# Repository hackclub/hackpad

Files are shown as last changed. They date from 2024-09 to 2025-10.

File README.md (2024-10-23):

# Hackpad

https://hackpad.hackclub.com/ <- website is live! This is probably a better place to start

## Overview
This is a limited-time introductory YSWS (you ship, we ship) where *you* design your own macropad, and we'll ship it to you for free! This is something you definitely don't want to miss out, so make sure to join #hackpad in the slack!

### You ship:
- A PCB Design and schematic
- Files for a case, either in STL or DXF format.
- Firmware for the keyboard. You are allowed to use QMK or other pre-existing firmware!

### We'll send you:
- 3 PCBs! Keep one for yourself, or share some with your friends. Or you can keep them all, I won't judge.
- a Seeed XIAO RP2040 microcontroller. They're pretty nifty microcontrollers, so you can use them for something else too
- Switches! Choices TBD, but you'll have a great selection
- Other components you may need, such as LEDs, diodes, knobs, OLED screens, and more!
- Your case! You can either have it 3D printed, laser cut in acrylic, or both.
- A grab bag of DSA keycaps, and a custom Hack Club keycap too.

You can get the macropads soldered if you don't have a soldering iron, or we can send you the parts directly if you're up for a soldering task. The only catch is that if you want it to be soldered, you *must* use through-hole components only!

### Requirements:
- You design a macropad that integrates a [Seeed XIAO RP2040](https://wiki.seeedstudio.com/XIAO-RP2040/) as the main MCU. Nothing else allowed, sorry!
- It has 20 or less inputs. A single input includes a rotary encoder, switch etc.
- It is meaningfully unique to you. This could be as simple as making a custom layout and adding some decor, or as elaborate as writing an entire firmware in Rust
- The PCB only uses 2 layers
- The PCB does not exceed 100mm in length in any direction
- Don't make a macropad with 40 screens. Or out of pure gold. Please!!

Once that's done, you can go on and make a PR. The instructions will be in the template.

## Anything else?

This YSWS is only guaranteed to run through October 21st, so make sure to get yours submitted before then. Depending on skill level, this should take roughly 6-12 hours to finish.

List of questions from the slack that you may want answered too:

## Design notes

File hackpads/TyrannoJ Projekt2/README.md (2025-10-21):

# TYRANNOJ PROJEKT2  
This is my first PCB, just want to play around with it. My firmware is not fully optimized due to a lack of time, I will optimize it when the parts get shipped. My libraries in the pcb part are zipped, so I could upload everything, you have to unzip them or else the pcb won't work
picture of project  

### Inspiration

Somebody in school told me about it

### Challenges

Did it for the first time, was pretty difficult

### Specifications

BOM:\
•   4x Cherry MX Switches  
•	2x SK6812 MINI Leds  
•	1x XIAO RP2040  
•	2x: RotaryEncoder_Alps_EC11E-Switch_Vertical_H20mm_CircularMountingHoles  
•	4x Blank DSA Keycaps  
•	4x M3x16 Bolt  
•	4x M3 Heatset  

Others: \
•	KMK Firmware <br>
•	Top.stl \
•	Bottom.stl 
Schematic            |  PCB         |   Case
:-------------------------:|:-------------------------:|:-------------------------:|
schematic    |  PCB  | case

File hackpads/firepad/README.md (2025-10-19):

# Firepad
## Firepup's macropad

Primarily intended as a general-use hackpad, I intend to use most of the extra F-keys for stream keybinds, although I've given myself more of those then I needed.

### Pictures

#### Above
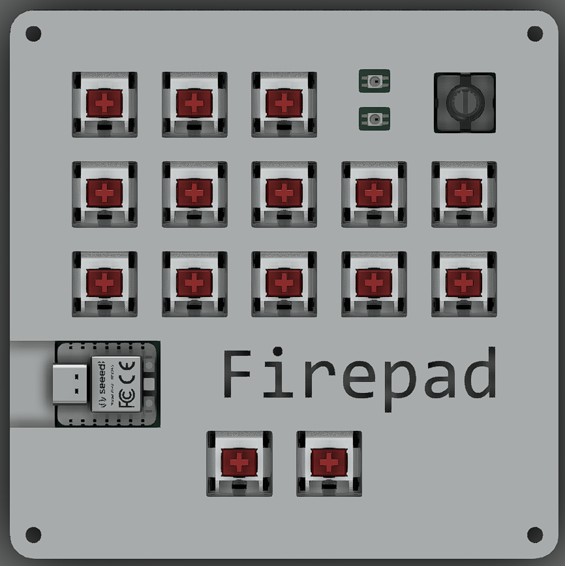
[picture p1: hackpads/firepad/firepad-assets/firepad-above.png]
Above View

#### Diagonal
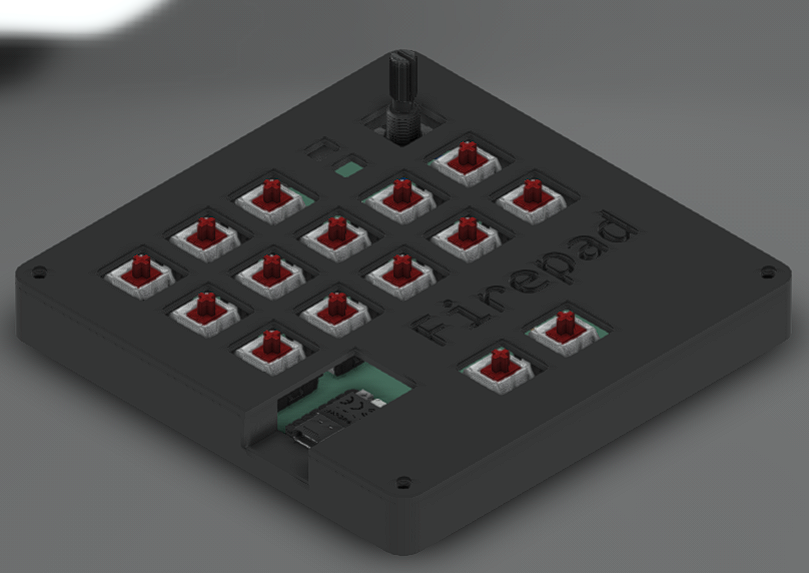
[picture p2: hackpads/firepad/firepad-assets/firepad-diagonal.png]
Diagonal View

#### Below
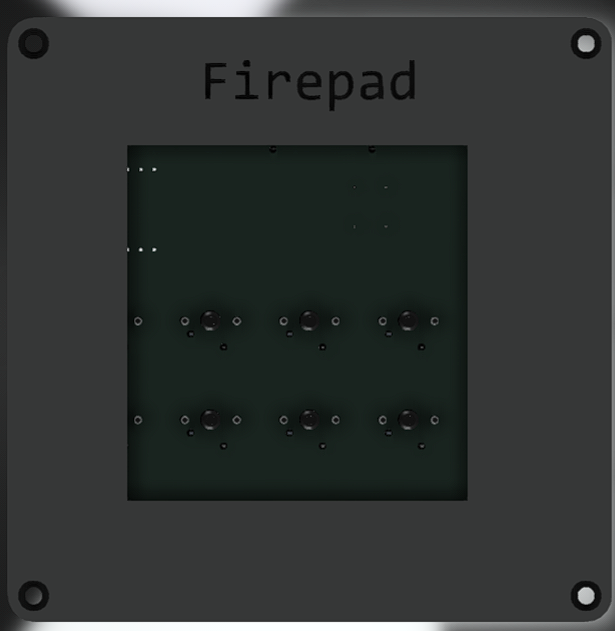
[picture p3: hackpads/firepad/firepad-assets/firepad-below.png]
Below View

#### PCB
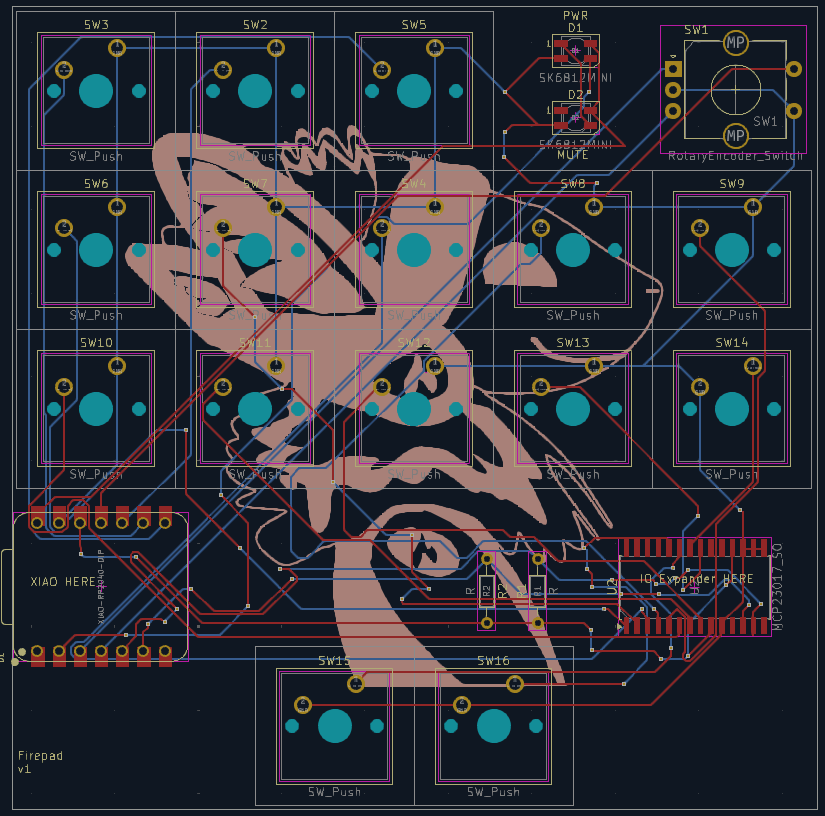
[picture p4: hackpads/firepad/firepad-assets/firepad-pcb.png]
PCB View

#### 3D PCB
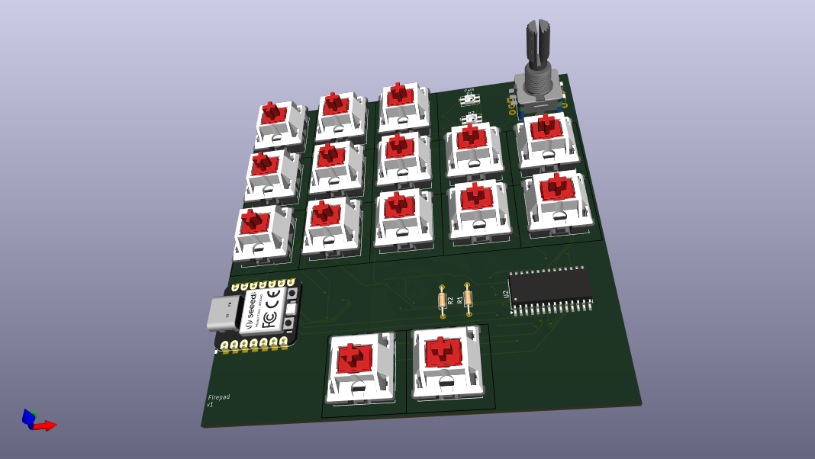
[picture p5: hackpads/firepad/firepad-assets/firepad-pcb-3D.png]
3D PCB View

#### Schematic
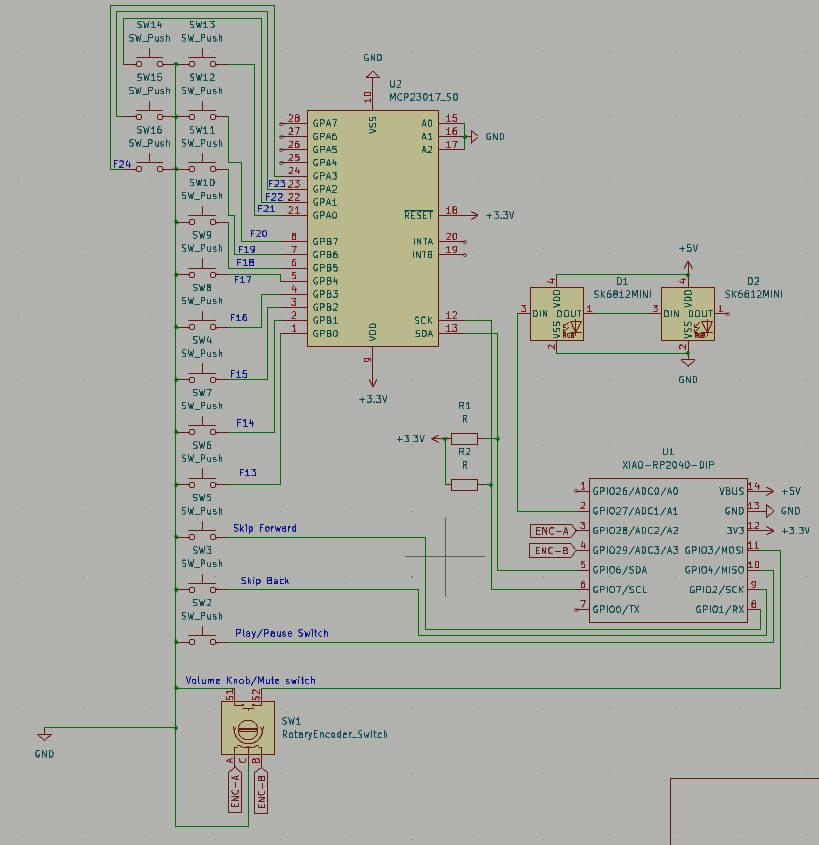
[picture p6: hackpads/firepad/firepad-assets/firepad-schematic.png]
Schematic View


### Frimware

The top three buttons (from left to right) are:
- Skip Backward
- Pause/Play
- Skip Forward

The next 5 buttons are F13-F17, the next five F18-F22, and the last two are F23 and F24.

The rotary encoder is volume control, and can be clicked to mute.

Clicking any button will slightly adjust the color of the power LED, and the mute key will switch on/off the mute LED, although it might be inverted, since I don't think I can detect host mute status.

### BOM
- 1x Seeed XIAO RP2040
- 15x Cherry MX Switches
- 1x EC11 Rotary encoder
- 15x Blank DSA keycaps (Red, preferably)
- 2x SK6812 MINI-E LEDs
- 4x M3x16mm screws
- 4x M3 hex nuts
- 4x M3x5mx4mm heatset inserts
- 1x MCP23017 io expander chip
- 1x Case (2 printed parts)

### TODO:
- Double check BOM & try to find prices

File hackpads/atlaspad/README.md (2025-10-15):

# Atlaspad

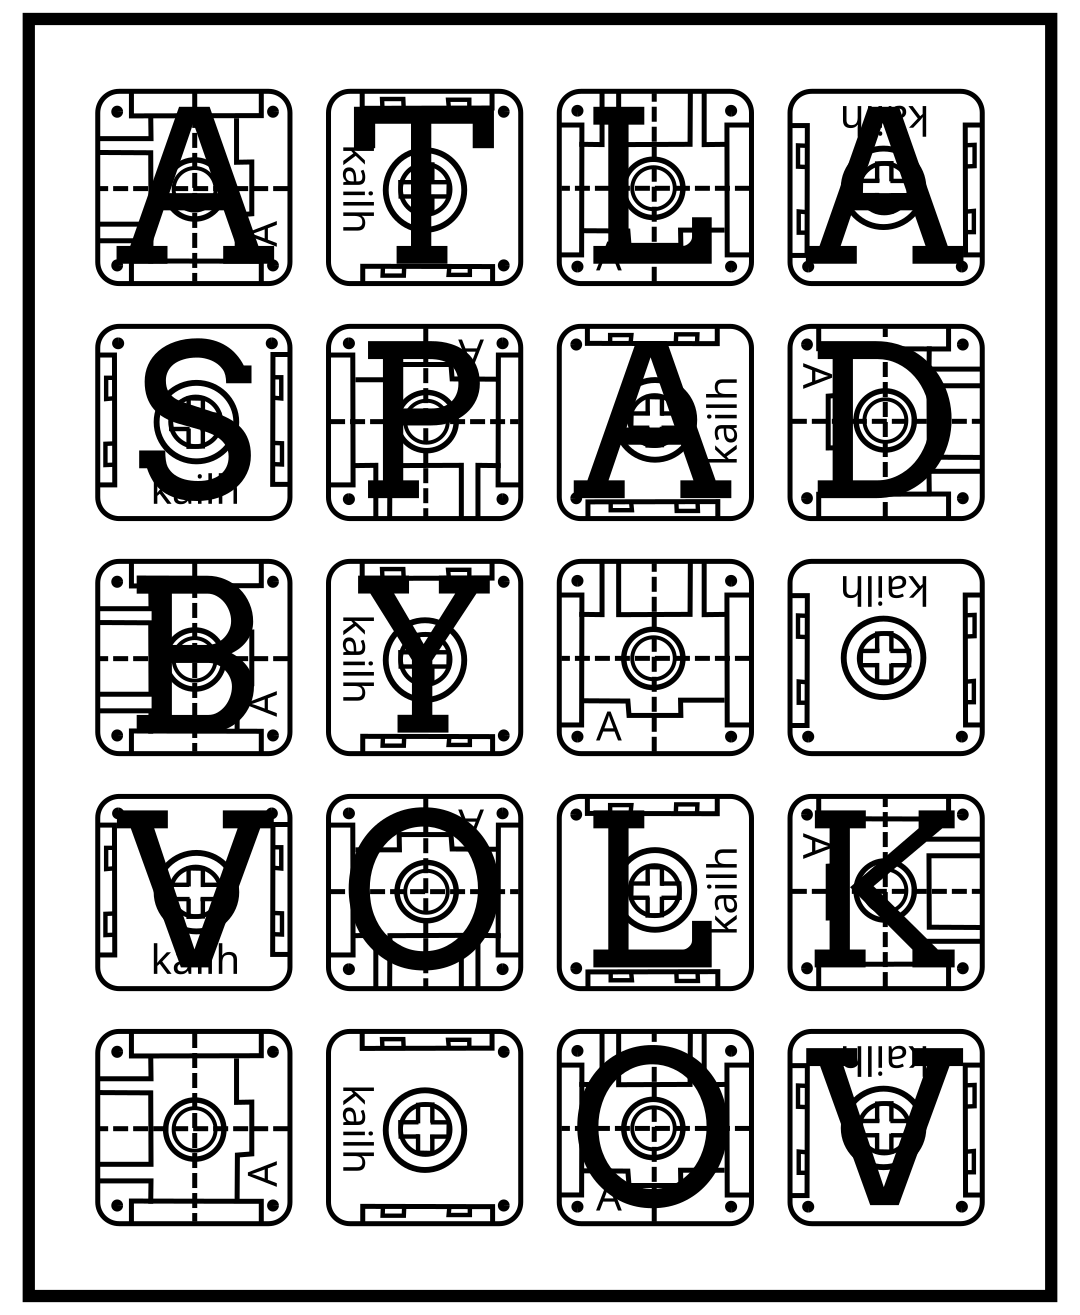
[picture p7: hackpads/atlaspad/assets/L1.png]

A compact Macropad based on a rp2040 xiao, packed with features!
(Originally intended as a Macropad for playing NMS, that functionality is WIP)

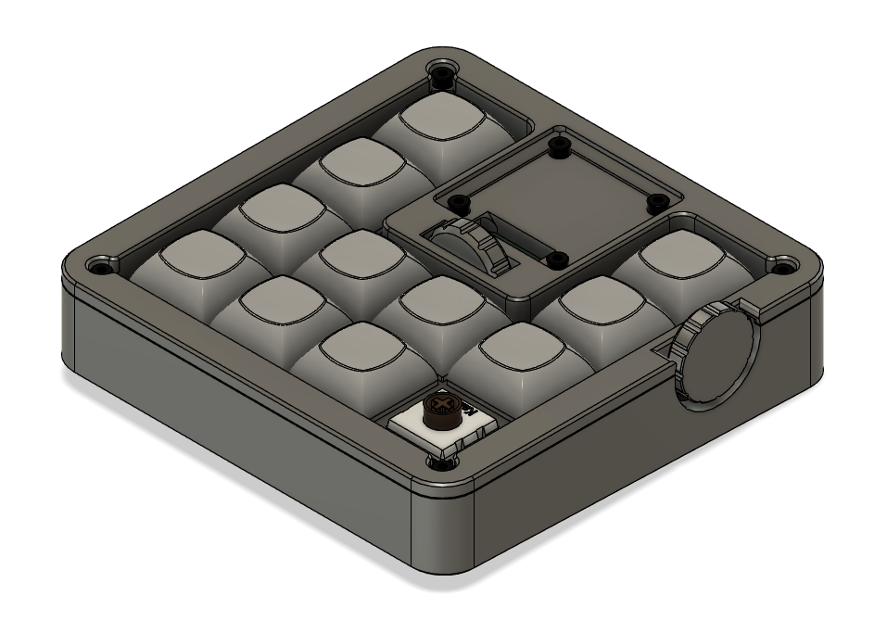
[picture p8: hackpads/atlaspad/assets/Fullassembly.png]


## Features:

-   12 ChocV2 Low-Profile Switches
-   14 Adressable LEDs Distributed across the Board
-   0.96" OLED Display
-   2 (Horizontal) Encoders

## CAD Model:

The model is based on a sandwich mount (Top,Plate,Base), but also includes the following parts:

-   2 custom wheels for the encoders (slightly slimmer one goes on the side, the thicker one in the middle)
-   an insert into the Top.stl piece thatll allow the OLED to be mounted slightly inset w/o any overhangs when printing

It's held together by 6 M2x16 (Back&OLED) and 2 M2x12 (Front) screws and corresponding hex nuts (DIN 912 & 934)

Exploded Assembly
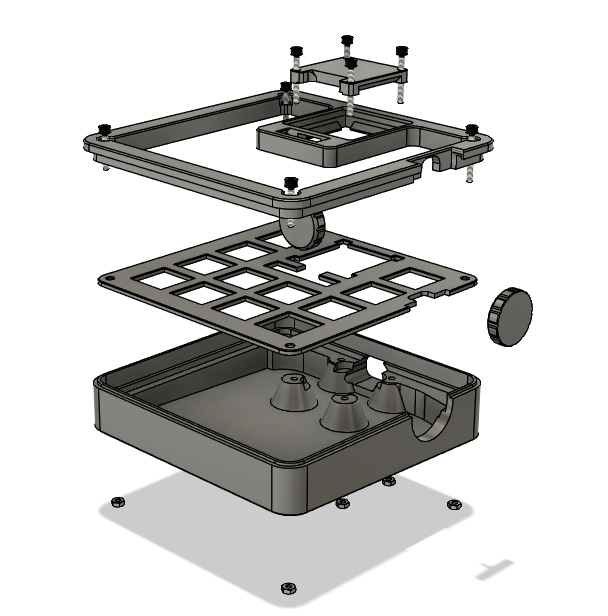
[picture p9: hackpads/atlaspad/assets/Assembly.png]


(the wheels are press-fit for the encoders / have to be glued, these were the only encoders small enough i could find)
_Designed in Fusion360_

## PCB

Schematic:

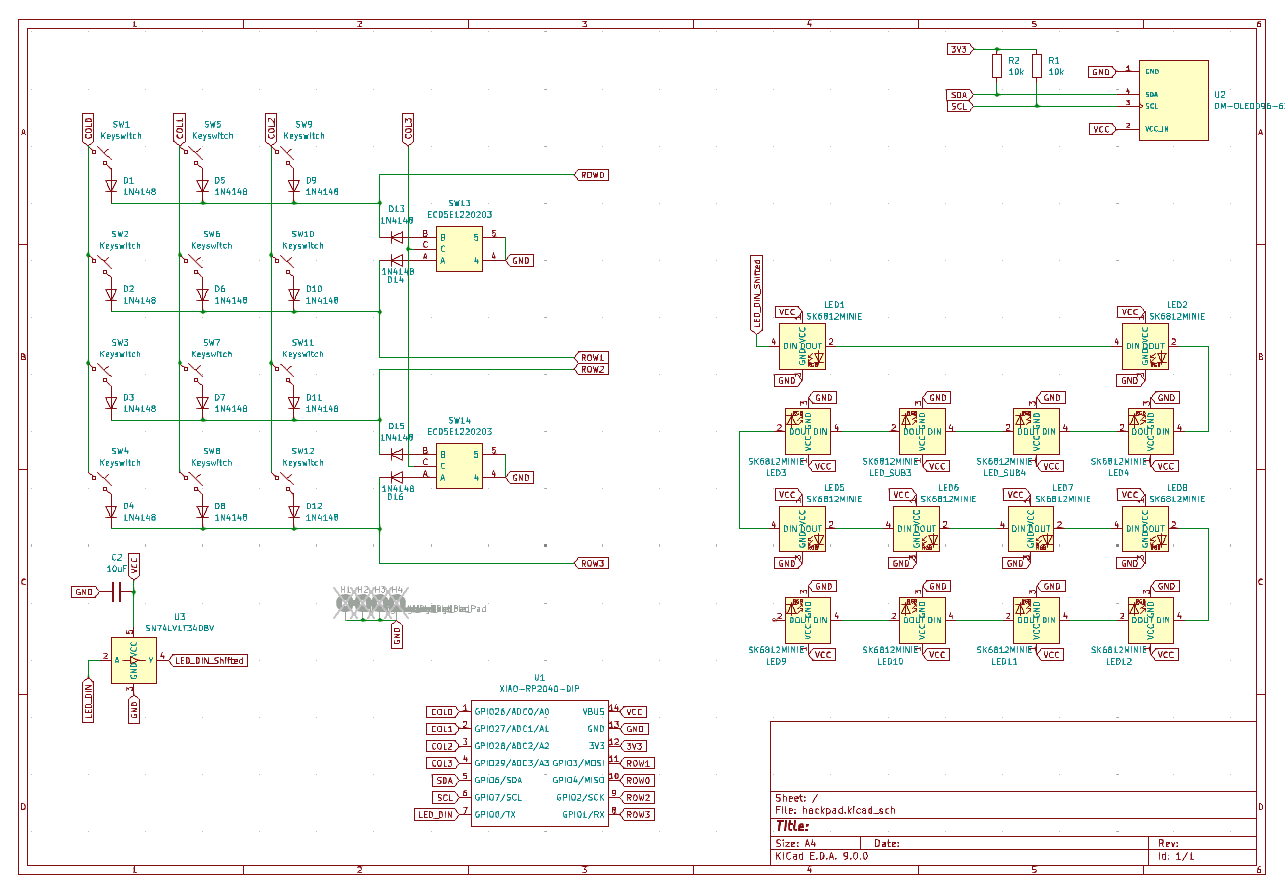
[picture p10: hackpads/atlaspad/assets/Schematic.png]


Front side of PCB:

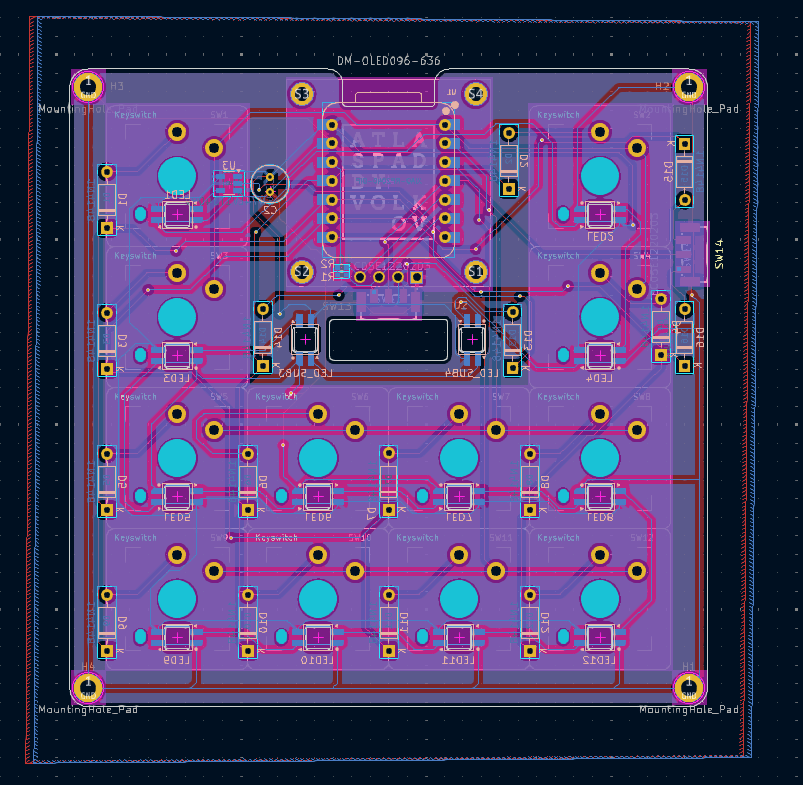
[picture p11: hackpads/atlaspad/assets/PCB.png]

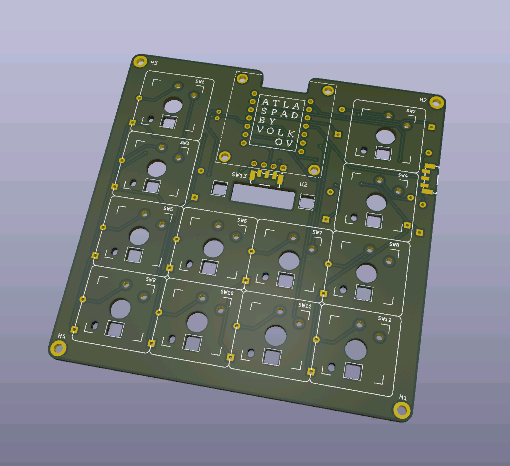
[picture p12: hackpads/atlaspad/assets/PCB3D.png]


_Designed in KiCad_

## Firmware Overview

This hackpad uses [QMK](https://qmk.fm/) firmware for everything.

Since this is my first time using QMK, only a basic configuration using this layout (mainly for KiCad) is in place:

    /*
     * ┌───┬───────┬───┐
     * │/\ │       │Hom│
     * ├───┤       ├───┤
     * │\/ │       │End│
     * ├───┼───┬───┼───┤
     * │F1 │F2 │F3 │F4 │
     * ├───┼───┼───┼───┤
     * │F5 │F6 │F7 │F8 │
     * └───────┴───┴───┘
     */

The LEDS are in a rainbow pattern :3 and the encoders are configured to sideways scrolling and volume. (encoder configuration might still be a bit buggy)
The OLED currently only displays debug information.

### Features planned

Once i get a working hackpad i can debug on, these are the features i wanna add

-   Multiple layers for different tasks (Fusion Shortcuts, Emojis/Emoticons/ NMS shortcuts)
-   OLED displaying info on layers (maybe even showing the layout itself, as a kind of label for the keys) & Toggle keys
-   LEDs reacting to keypresses, custom wave animation (going out from the pressed key)

## BOM:

Here should be everything you need to make this hackpad besides the PCB and 3d printed parts:

#### Mechanical

-   2x M2x12 Screws
-   6x M2x16 Screws
-   8x M2 Hex nuts

#### Main Features

-   1x Seeed Studio rp2040 xiao
-   12x ChocV2 Switches
-   14x sk6812-mini-e LEDs (sk6812-mini have a different pinout)
-   1x .96" sd1306 OLED Display (if you wanna connect it through a pin header, make sure the Order is GND/VCC/SCL/SDA)
-   2x EC05E1220203 Rotary encoders (SMD)

#### Additional

-   16x 1N4148 THT Diodes

### Optional (but recommended)

-   2x 10k 0402 Resistors
-   1x 10uF Electrolytic cap
-   1x SN74LV1T34DBV level shifter

The hackpad might work w/o these components, but its better to add them.
Here is how to adjust when leaving them out:

-   Resistors are i2c pullups. leave empty
-   Capacitor is a buffer for the LEDs (the can draw >700mA at max Brightness). leave empty
-   Voltage shifter is to accomodate the specified 3.4V minimum data High level, just above the 3.3V outputted by the rp2040. It may work without, but possibly inconsistently. If leaving out, bridge the LED_DIN and LED_DIN_Shifted contacts of the IC Footprint (see below).

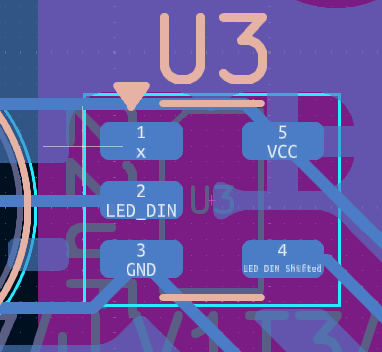
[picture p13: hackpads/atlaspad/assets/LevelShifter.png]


## Notes:

I hope this works lol .-.

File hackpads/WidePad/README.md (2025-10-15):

# WidePad

WidePad is a 15 key macropad with an OLED display. It uses diodes and switches in a matrix to 
achieve key rollover. Currently the test firmware is KMK, although it is very likely that 
WidePad will be migrated to use QMK.

## Features
- 0.96" OLED screen
- Silkscreen art
- 15! Cherry MX style switches
- A wide and large(ish) form factor
- KMK firmware!
- PCB is friction fit so no need for an extra screw :3

## Challenges

Too many to count. I did all the PCB design in a VM on my server (which only has 2.5" SMR 
disks, which was painfully slow). KiCad crashed multiple times. Additionally I made many 
routing mistakes and ended up redoing the whole board (I had LEDS in the first board I was 
designing, cost me 5 hours).  I did all of this in 
<24h and pulled an all nighter.

## BOM
- XIAO RP2040
- 15x Cherry MX style switches
- 15x Blank DSA keycaps
- 1x SSD1306 128x64O LED (5V VCC, 3.3V logic, I2C)
- 2x 4.7k ohm resistors
- 6x 1N4148 diodes
- 4x Same screws and heatset inserts as orpheuspad (M3 Bolts and heatset inserts?)

## Gallery

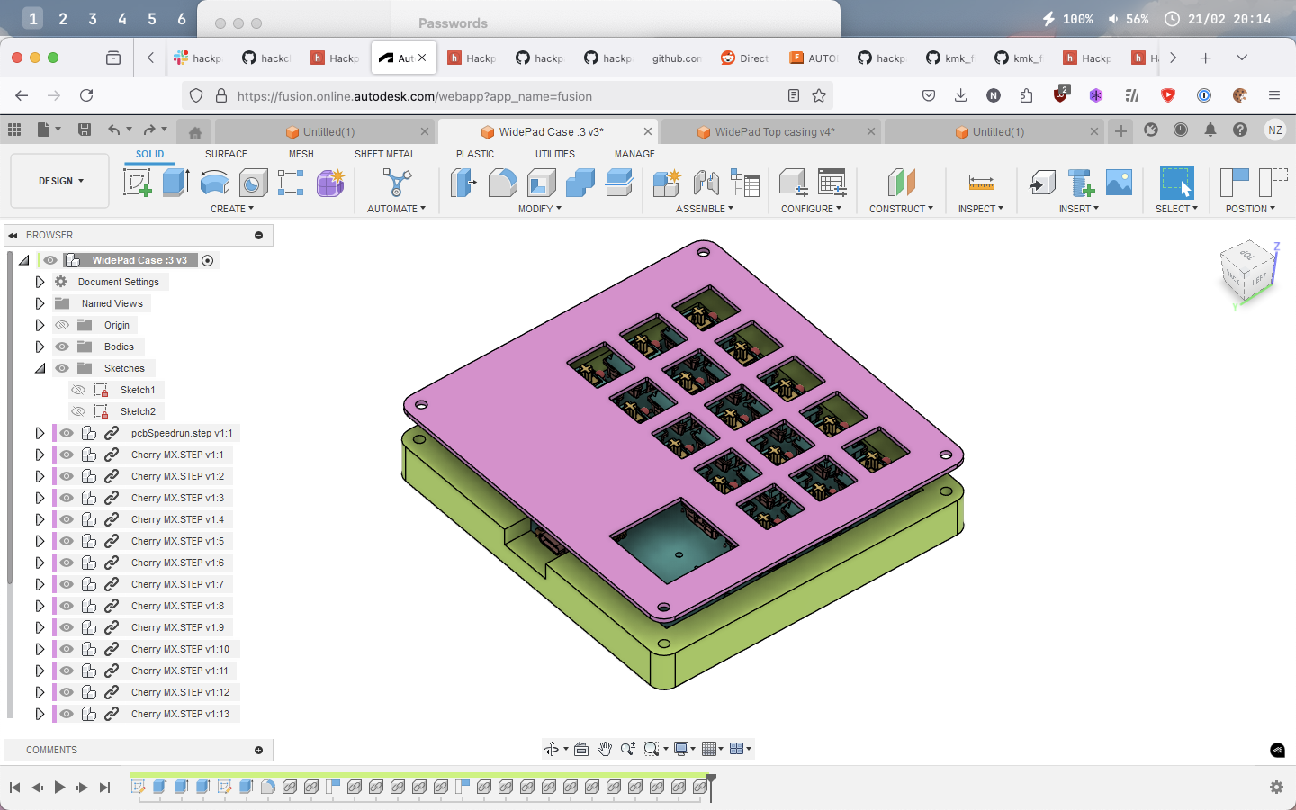
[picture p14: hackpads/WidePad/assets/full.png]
Everything put together

Note OLED screen not cadded because I can't find a model (or maybe the sleep loss is getting 
to me deadge)

Here are some pictures of my schematic, PCB, and case:

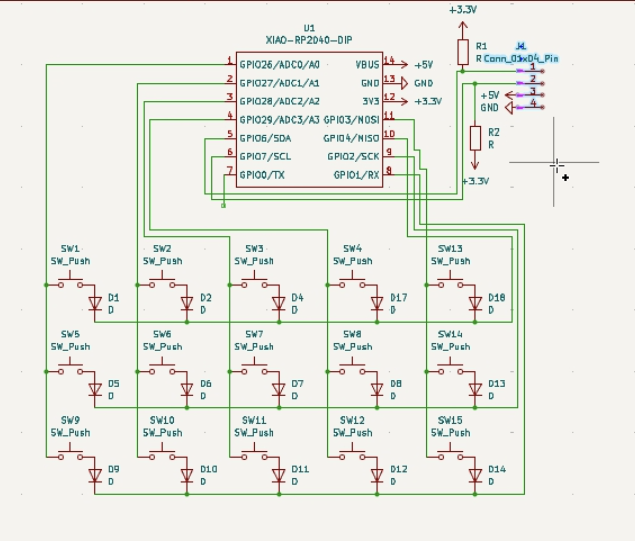
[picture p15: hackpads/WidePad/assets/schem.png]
Schematic

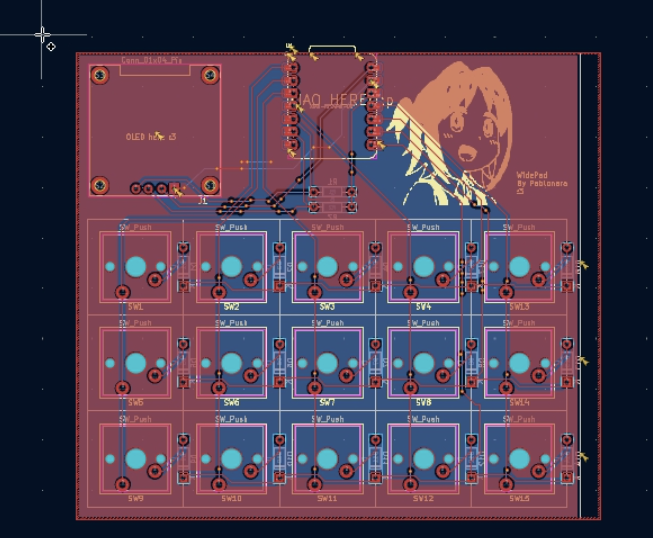
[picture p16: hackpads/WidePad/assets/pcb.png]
PCB

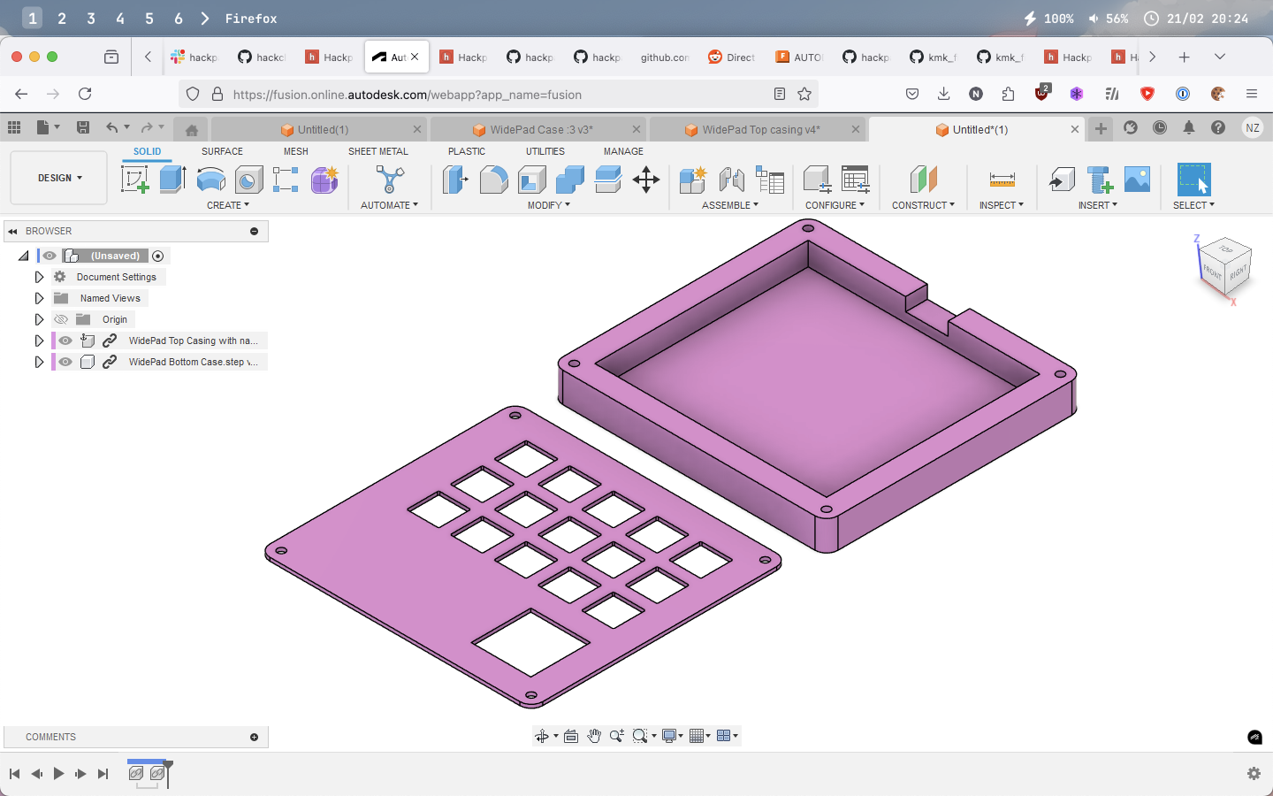
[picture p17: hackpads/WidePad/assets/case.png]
Case


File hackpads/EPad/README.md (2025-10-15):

# Epad
This is my submission for Hackpad V2!

## Inspiration
I was inspired by a macropad that I saw in a YouTube video a while back. It looked really cool so I tried to replicate it as best as I could from memory.

## Challenges
My biggest challenge was getting everything to line up correctly. I know I spent a long time just getting every hole at the top lined up with the switches.

## Features
- 12x cherry mx keys
- 1x rotary encoder switch
- KMK firmware

## PCB

| **Schematic** | **PCB** |
|---|---|
|||

## CAD

Designed with Fusion 360. The guide helped a ton!




## Firmware

Made using KMK Firmware

## BOM
- 1 XIAO-RP2040
- 12x Cherry MX Switches
- 12x White keycaps
- 12x 35_SOD27_P7.62mm diodes
- 1x Rotary Encoder Switch
- 4x 8mm deep 3.332mm wide 4mm size m4x0.7 screws
- 1x knob for the rotary encoder

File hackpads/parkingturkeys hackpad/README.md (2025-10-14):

# PARKING TURKEYS'S awesome hackpad :3c

*abbreviated as p-t's hackpad :3c*
p-t's hackpad :3c is a 4 key macropad arranged in the style of arrow keys. You can use it for playing games and typing and stuf.

## Features:
- Keys.
- the power of WONDERHOY⭐
- 4 LEDs
- ✨customizability✨

## CAD Model:
Everything fits together using 5 M3 Bolts and heatset inserts. 4 for the case, one for the PCB. Also, it has a 5 degree tilt

It has 2 separate printed pieces. The bottom and the top cover.
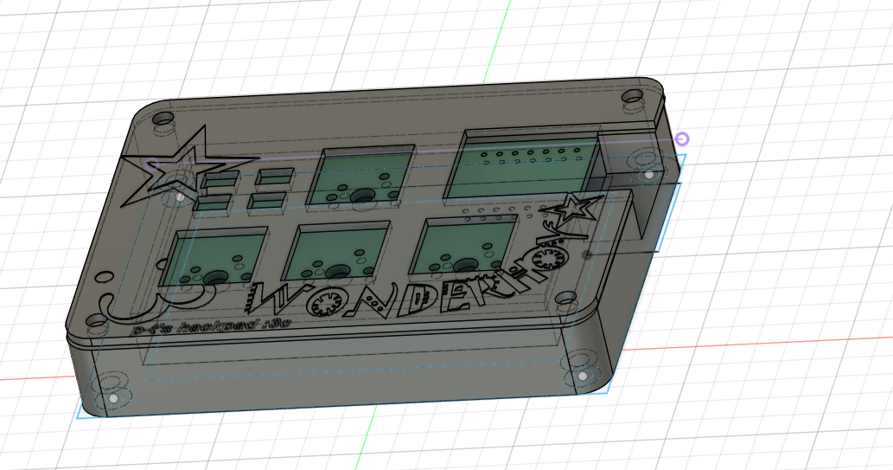
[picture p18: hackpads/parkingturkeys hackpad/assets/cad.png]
3d model of the case


I made it in Fusion 360! :3

## PCB
Here's my PCB! It was made in KiCad.

Schematic
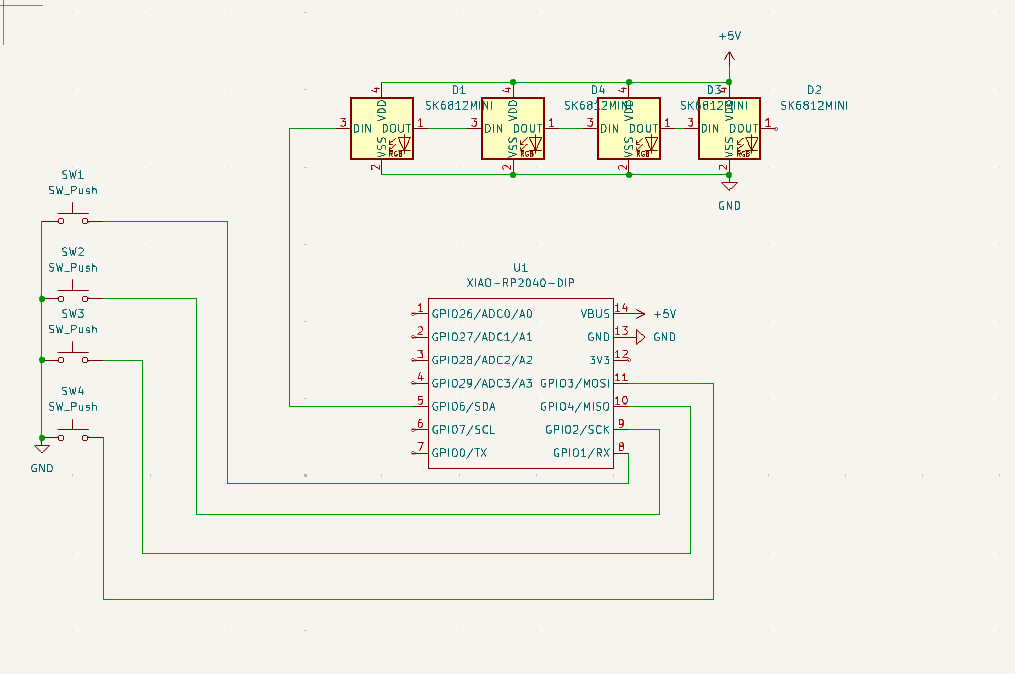
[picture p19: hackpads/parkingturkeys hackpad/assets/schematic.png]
Schematic


PCB
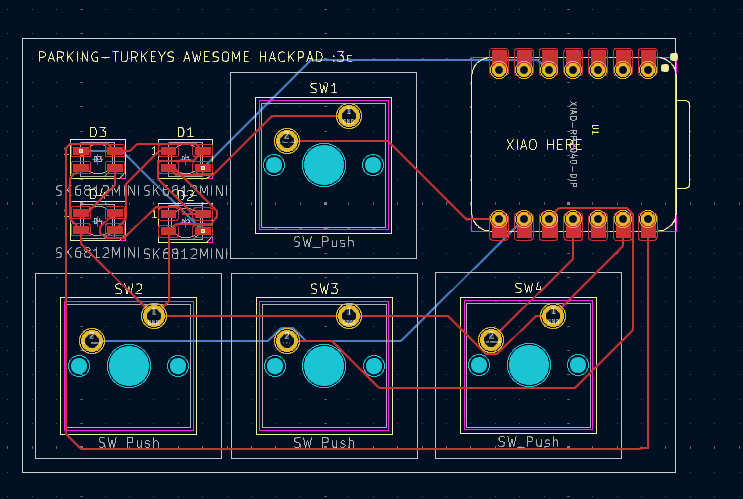
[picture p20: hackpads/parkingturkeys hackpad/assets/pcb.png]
pcb


It was made by moving around the tutorial a bit

## Firmware Overview
This hackpad uses [KMK](https://github.com/KMKfw/kmk_firmware/) firmware for everything. 

- I'm using the keys as arrows for now
- I would like to try macros at some point
- IDK how the LED works :heavysob:

:heavysob:

I might add more in the future! That's it for now

## BOM:
Here should be everything you need to make this hackpad

- 4x Cherry MX Switches
- 4x DSA Keycaps (preferred black)
- 4x M3x16 Bolt
- 4x SK6812 MINI Leds
- 1x Case (2 printed parts)
- 1x XIAO RP2040

... this is probably wrong :heavysob:

## Extra stuff

WONDERHOY is a project sekai reference. :3c

A lot of this README is taken from the Orpheuspad one so heres the MIT license it's under 

```
MIT License

Copyright (c) 2024-2025 Hack Club

Permission is hereby granted, free of charge, to any person obtaining a copy of this software and associated documentation files (the “Software”), to deal in the Software without restriction, including without limitation the rights to use, copy, modify, merge, publish, distribute, sublicense, and/or sell copies of the Software, and to permit persons to whom the Software is furnished to do so, subject to the following conditions:

The above copyright notice and this permission notice shall be included in all copies or substantial portions of the Software.

THE SOFTWARE IS PROVIDED “AS IS”, WITHOUT WARRANTY OF ANY KIND, EXPRESS OR IMPLIED, INCLUDING BUT NOT LIMITED TO THE WARRANTIES OF MERCHANTABILITY, FITNESS FOR A PARTICULAR PURPOSE AND NONINFRINGEMENT. IN NO EVENT SHALL THE AUTHORS OR COPYRIGHT HOLDERS BE LIABLE FOR ANY CLAIM, DAMAGES OR OTHER LIABILITY, WHETHER IN AN ACTION OF CONTRACT, TORT OR OTHERWISE, ARISING FROM, OUT OF OR IN CONNECTION WITH THE SOFTWARE OR THE USE OR OTHER DEALINGS IN THE SOFTWARE.
```

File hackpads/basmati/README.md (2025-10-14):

# basmati
Yet another macropad. Built for [hackpad](https://hackpad.hackclub.com).

## Designs
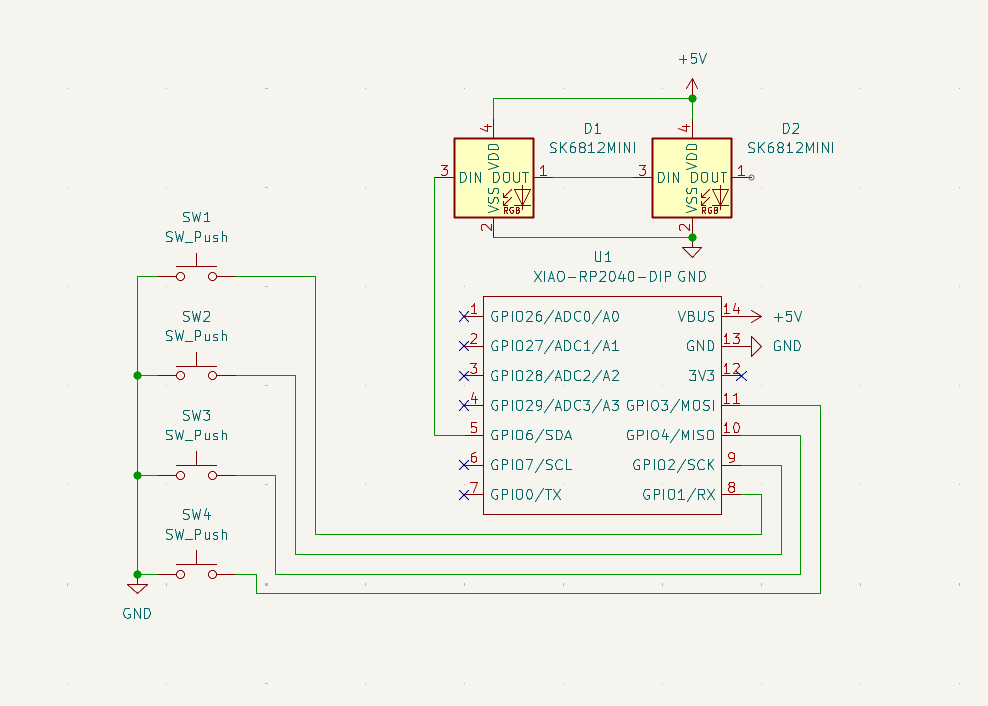
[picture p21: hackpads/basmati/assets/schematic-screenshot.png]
Schematic Diagram

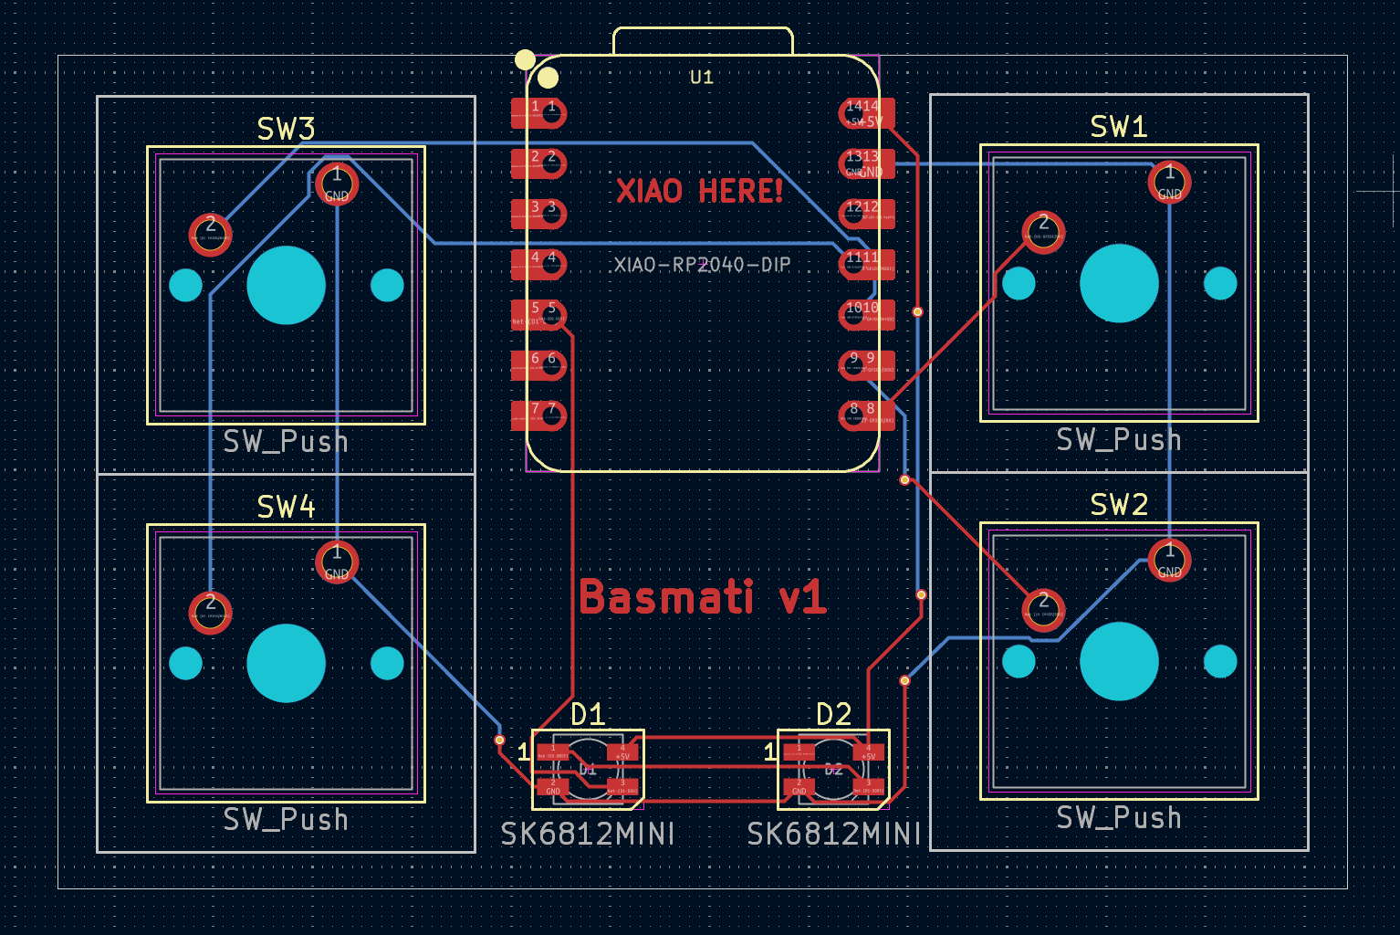
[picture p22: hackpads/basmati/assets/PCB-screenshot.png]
PCB Diagram

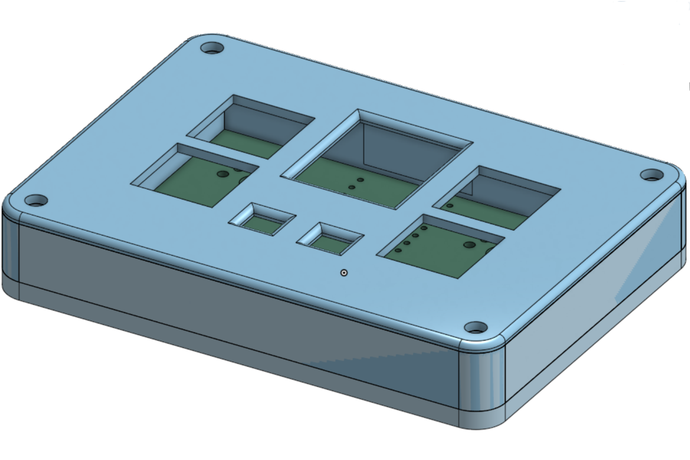
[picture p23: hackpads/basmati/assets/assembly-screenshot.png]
Assembly


## Firmware

Firmware for basmati is made with [KMK](https://github.com/KMKfw/kmk_firmware). Located at `production/main.py`.

## BOM

- SK6812 Mini LEDs
- XIAO RP2040 Microcontroller
- SW Cherry MX Switches
- 3D-Printed Case (See `CAD/`)
- PCB (SEE `PCB/`)
- 4x Red DSA Keycaps
## Case

The case comes in two parts:
- The base holds the PCB, and has text engraved on the bottom.
- The top has holes for all the keys and LEDs, plus it exposes the RP2040 so you can be hacker.

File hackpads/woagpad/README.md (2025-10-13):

# The Woagpad

## A macropad of all time

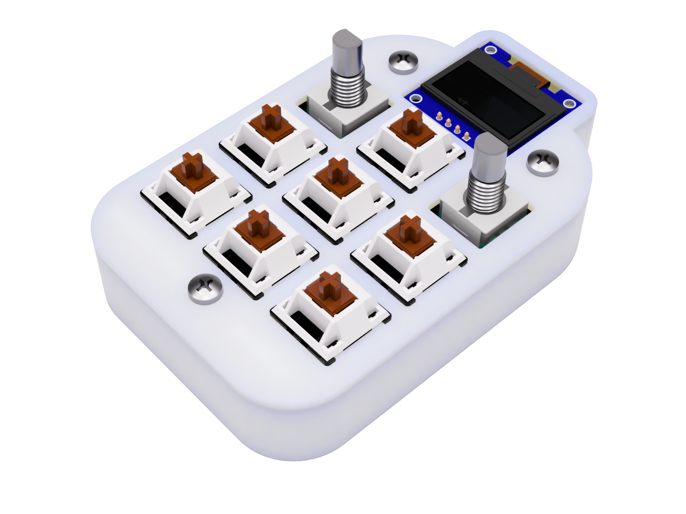
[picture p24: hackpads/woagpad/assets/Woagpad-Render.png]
Woagpad


The woagpad is a board I decided to create because a macropad
kinda just sounds fun. I really also wanted the rotary encoders
to be able to change volume and control media playback (although RMK doesn't support it yet. Eventually:tm:).

## Features

- **Rust based firmware**: Through the power of [RMK](https://haobogu.github.io/rmk), the firmware is written in 100% Rust. Crab gaming :crab:
  - [VIAL](https://get.vial.today/) support OOTB
- **128x64 OLED Display**: Display whatever the hell you want*
- **2 EC11 Rotary Encoders**: Control your volume or scroll through pages with these*
- **3x3 key matrix**: Keypad, macro, media controls, whatever the hell you want. You have 9 keys to mess around with (this includes the push buttons on the rotary encoders)

*The default rmk firmware does not support OLED display or rotary encoders yet.
Once those are implemented, the firmware will be updated to support them.
Write your own firmware to take advantage of these features!

## Design

### PCB
Schematic

Bog standard PCB Schematic for a macropad.
This is actually my first design that uses a matrix
and an OLED display so that's fun.

Also yes, 2 encoders can share a pin! Neat.

|Front|Back|
|---|---|
|PCB Front Design|PCB Back Design|

First PCB with actual mounting holes.
although in this case, the mounting holes are used
for mounting the top and bottom of the case.
See the case design for more details.

### Case
Case Design

Top integrated plate + frame. Bottom half with standoffs
for heat inserts to screw the two halves together.

Also yes, the encoder holes are slightly larger than the encoders.
I have no idea how well they'll actually fit so I decided for
more tolerance than normal. It'll be fine... right?

### BOM
- 1x PCB
  - see production/gerber.zip
- 1x Case
  - see production/Top.step
  - see production/Bottom.step
- 7X Cherry MX Switches
- 7X DSA Keycaps
- 2X Rotary Encoders
- 9X 1N4148 Diodes
- 3X M3x5mx4mm Heatset inserts
- 3X M3x16mm Bolts
- 1x XIAO RP2040
- 1x 0.91" 128x64 OLED Display

## Extras
First time using [RMK](https://haobogu.github.io/rmk) for firmware. It was WAY easier compared to other firmware options.
Highly reccomend if you don't need additional features.

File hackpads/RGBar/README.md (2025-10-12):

# RGBar
RGBoard is an 8 key macropad with a rotary encoder. Each key is backlit with a SK6812 reverse mounted neopixel.
KW-01 Assembled

### Inspiration
I wanted to make something sleek and minimalist - kinda like a streamdeck, but with keys. I couldn't resist the RGB temptation though... oh well. More is better than less, right?

### Challenges
Since this was my first ever PCB, routing and learning the process took a looong time... Also, writing firmware without testing was a bit unorthodox, it it's *probably* fine...

## Features
- 3D printed case
- EC11 rotary encoder
- 8 keys w/ rgb backlighting

## CAD
The top and bottom are assembled using 4 M3 bolts and heated inserts. 
KW-01 Deconstructed

Here's a top view:


## PCB
The PCB was made in KiCad - the board is powered by a Seeed Studio XIAO RP2040.

Here's the schematic:


...and the PCB:


## Firmware
This hackpad uses KMK firmware. Currently, RGBar just acts like a numpad (with backlighting on press) and the rotary encoder adjusts screen brightness, but it can be reprogrammed to do much more...

## BOM
### Custom Components
- 1x Custom PCB
- 1x 3D printed case (top, bottom, and knob)
- 8x 3D printed keycaps (...or any other keycap for Cherry MX switches)
  
### COTS Components
- 8x Cherry MX switches (4 clicky and 4 linear as a personal preference~)
- 8x 1N4148 Diodes (through hole)
- 8x SK6812 MINI-E LEDs
- 1x EC11 Rotary encoder
- 1x Seeed XIAO RP2040 (through hole)
- 14x Male headers
- 4x M3 x 6mm Screws
- 4x M3x5mx4mm heatset inserts

## Extra stuff
I built this as a part of Hack Club's Hackpad program. I haven't tested any of it yet, since I don't currently have the parts~

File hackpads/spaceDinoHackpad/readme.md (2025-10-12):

# Space Dino Hackpad
The Space Dino Hackpad is a 12 key macropad. It also contains a rotary encoder, and 12 leds, one under each key.
It uses KMK firmware, designed to make programming easier.

## Features List
- 2 part 3d printed case
- EC11 Rotary Encoder
- 12 keys
- 12 rgb leds

## Case
The case is fully 3d printed, and contains two parts. The two parts are attached with 4 M3 bolts and heatset inserts. It was designed in FreeCad.
20250217_14h36m06s_grim

## PCB
The PCB was designed in KiCad. It uses a switch matrix to attach all the keys. The LED's are reverse mounted, and simply wired in a line.

Schematic
20250220_13h25m19s_grim

The PCB is 2 layers, and contains a ground plane. The silkscreen art was drawn by me.
PCB
20250220_13h31m59s_grim

## Firmware
The firmware was written in python using KMK.

### Rotary Encoder
The rotary encoder simply controls volume. Pressing the switch mutes volume.

### LEDs
The LEDs are set to run a "rainbow" animation

### Keys
The keys are all linked to various functions useful when programming.

#### Copy Paste

The first two keys on the top row are routed to Ctrl+Shift+C and Ctrl+Shift+V. This allows for copying and pasting in the terminal on most Linux systems.
The two keys below these are routed to Ctrl+C and Ctrl+V for copy pasting in most IDEs and text editors

#### Run
On the first row the rightmost key is routed to F5. This is the shortcut in VS Code to start debugging.
The key below this is routed to Ctrl+F5, which runs without debugging in VS Code.

#### Macros
The third row is dedicated to useful macros for programming. The first key inserts a TODO comment.
The second inserts a formatedd docstring with spots to insert a function description, info on parameters, and info on returns.
The last key copies the current line, pastes it on a new line below, and comments the original. This is useful for testing alternative parameters, without deleting the original.
These are all setup to use python formatting, and the last one uses VS Code shortcuts.

#### Terminal shortcut
The first key on the fourth row is routed to Ctrl+ `. In VS Code, this switches between the code editor and the terminal.

#### Blank Keys
The last two keys currently have no function. Functions will likely be added in the future. For now, they serve as keys to fidget with while thinking.

## Challenges
This was my first time using both KiCad and 3d design software, meaning I had to learn the ins and outs of the software. I also attempted to use FreeCad on a pi 4, which in hindsight wasn't the best of ideas. It led to long loading times, slow software, and many crashes. It wasn't too bad, as these problems were minimized for most of the design process, and mostly caused problems when the PCB was loaded into the software. 

## BOM
- 12x Cherry MX Switches
- 12x DSA Keycaps(assorment of colors prefered)
- 12x SK6812 MINI-E LEDs
- 12x Through hole 1N4148 Diodes
- 1x EC11 Roatary Encoder
- 1x Seeed XIAO RP2040
- 4x M3 screws
- 4x M3 heatset inserets
- 1x 3d printed case(2 parts)

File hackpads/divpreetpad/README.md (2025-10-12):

# divpreetpad
-- --
> a custom macropad i made to boost my productivity, or ruin it.
-- --
entire_board

### Inspiration
After hours of binging custom macropad videos, i finally got the chance to make my own! and its REALLY fun, i didnt really have alot of time to spend (only two days!) but i did end up pulling it off, the journey is pretty fun! but at times it gets annoying, yup thanks but no thanks FreeCAD
-- --
### Challenges
It was my first time using a set of software like KiCad and Fusion! it was really frustruating since mouse controls in KiCad SUCK, but once you get the hang of it, they arent that bad! also i tried FreeCAD, which was my worst choice in the journey. spending almost two days on just the plate! im really greatful to @Cyao, @Daamin, and #hackpad for helping me out! 
-- --
top case
-- --
### My Overall Journey
I'll try to keep this as short and simple as i can! so i first went ahead to make my schematics following the [guide](https://hackpad.hackclub.com), and stuff was going pretty well, until i wanted to add a display! so i spammed google, slack, and ChatPPT, and eventually i did get the OLED Screen ready! next was the routing, it seems pretty complicated, but once you get the hang of it and learn to keep one finger at V, its pretty easy! after that, we had to make the 3D Models! this part was where i messed up by choosing FreeCAD. it was less resource intensive, so i chose it! it took me TWO days to get the top plate, so i gave up and moved onto Fusion! in which i was able to make the whole case in a day (same day as PR)! after that every thing was pretty smooth, i did face problems in the measurements, but taking a closer look and asking for help got me a pretty great result! after that it was time for the firmware, the starter code and the documentation really helped in that too! oops too long 😭
-- --
Schematic            |  PCB         |   Case
:-------------------------:|:-------------------------:|:-------------------------:|
shematic    |  pcb  | 

-- --
### Specifications

BOM:
- 12x Cherry MX Switches
- 12x 1N4148 diodes
- 1x XIAO RP2040
- Blank DSA Keycaps (6x Black, 6x White)
- 1x SSD1306 128x32 0.91" OLED (5V VCC, 3.3V logic, I2C)
- 4x M3x16 Bolt
- 4x M3 Heatset
- 1x Case (Top and Bottom)
- 1x PCB
  
-- --

Others:
- KMK Firmware
- Top.step
- Bottom.step
-- --
### Final Look
i love it

completed

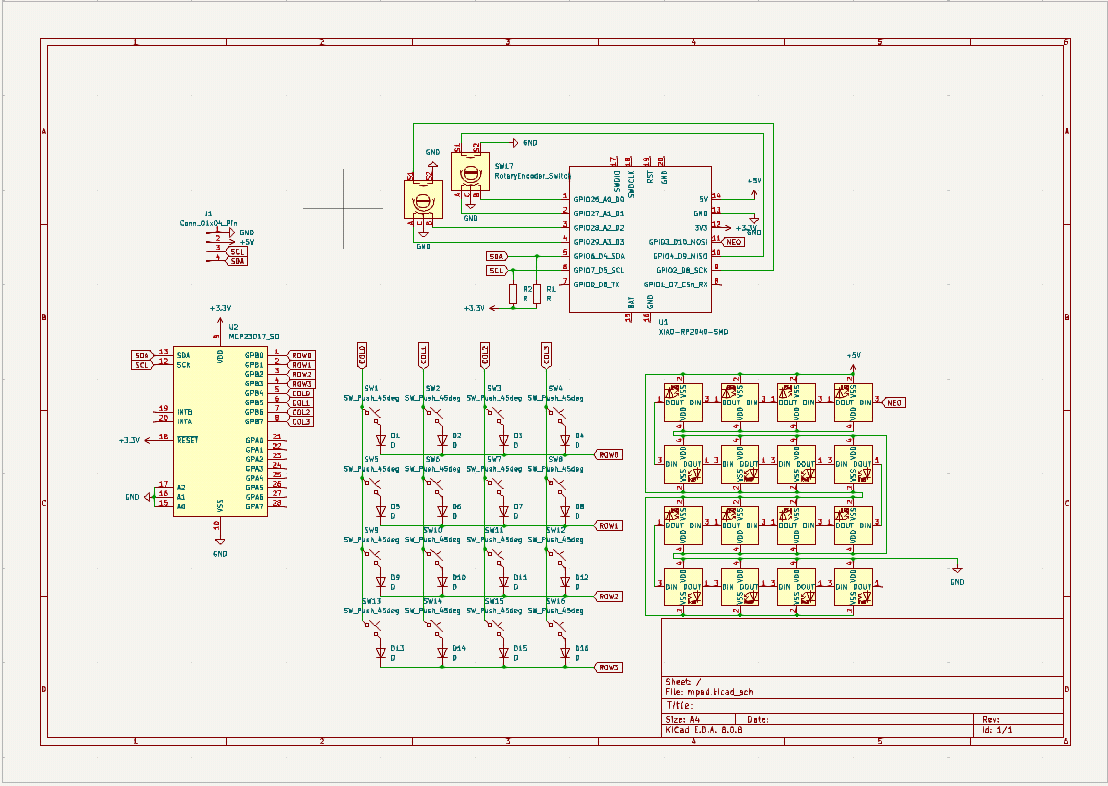
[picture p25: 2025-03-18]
hackpads/jankpad/assets/schematic.png

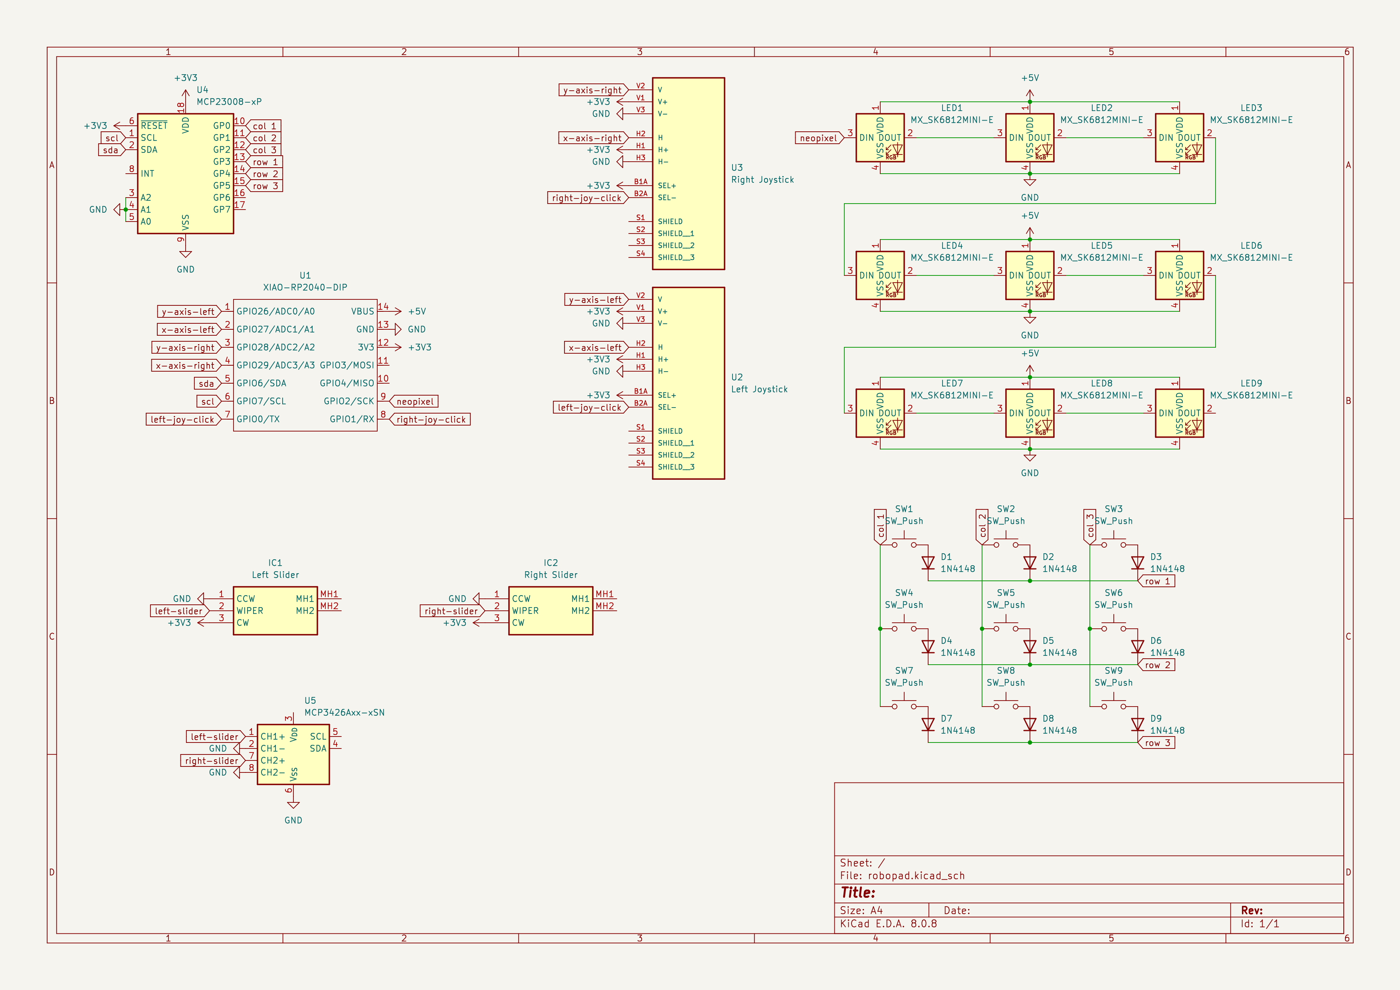
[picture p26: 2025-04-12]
hackpads/robopad/assets/schematic.png

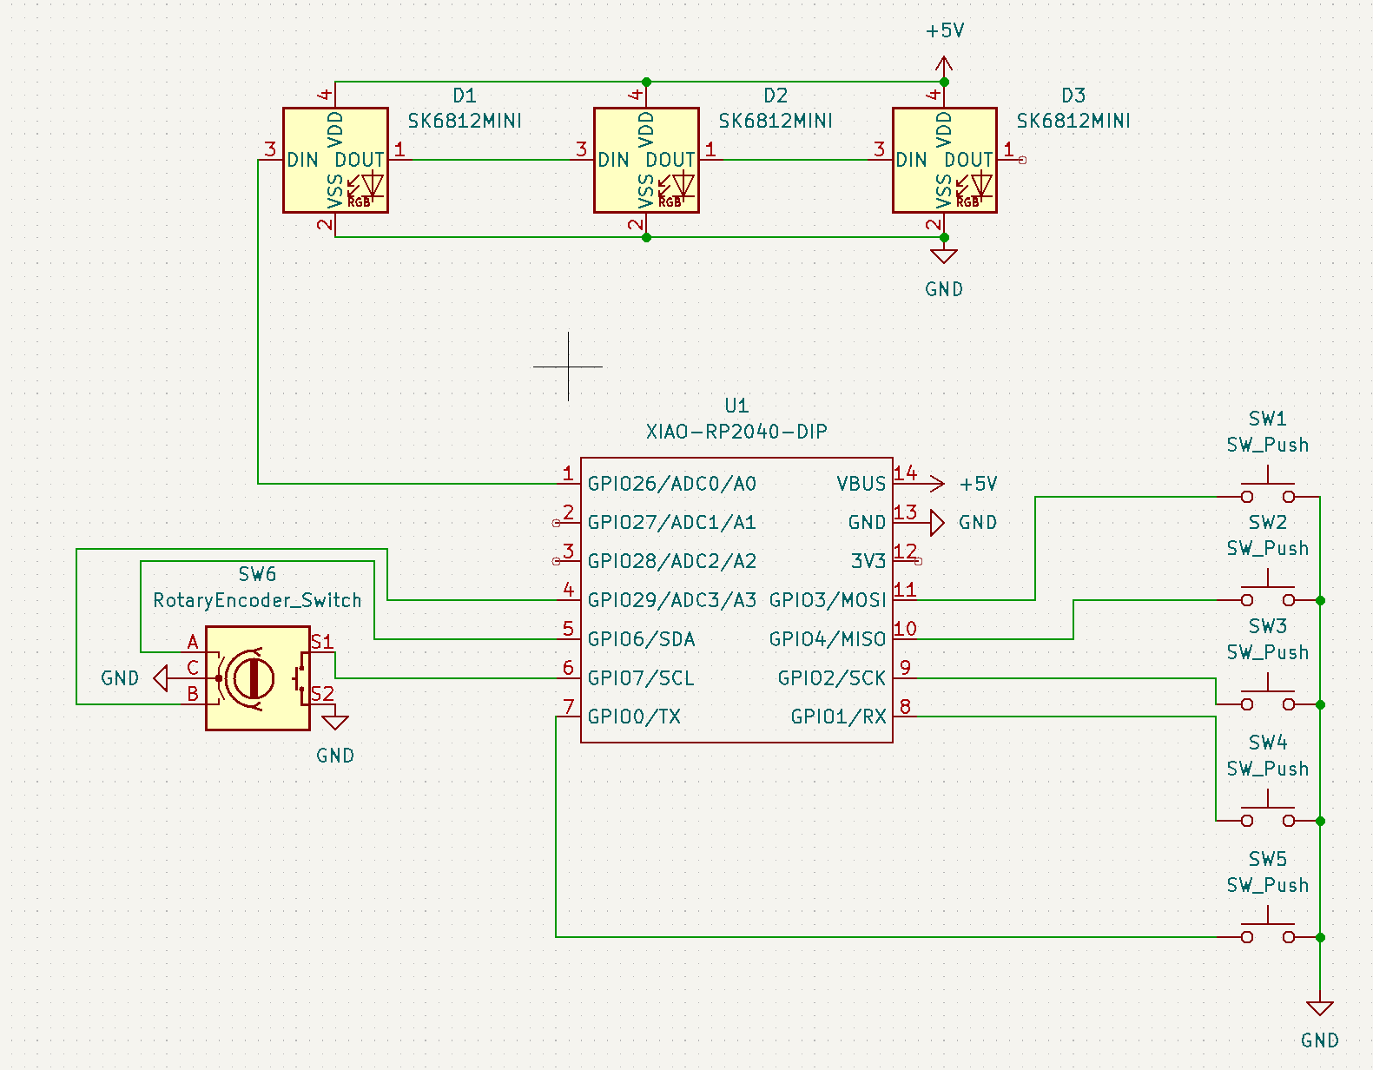
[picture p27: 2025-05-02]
hackpads/ButtonMasher.exe/assets/pcb_schematic.png

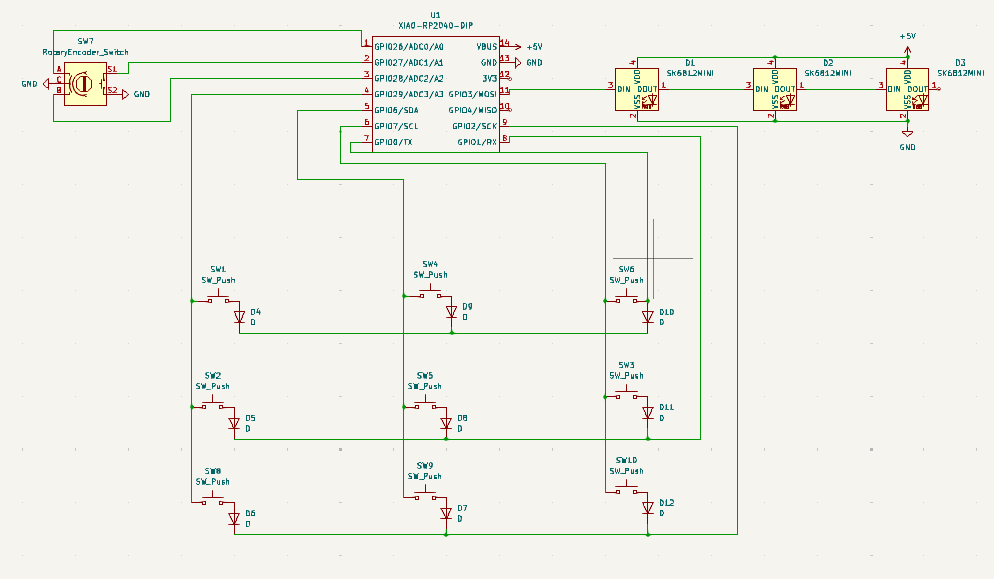
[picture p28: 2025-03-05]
hackpads/Yound PADavan/assets/Schematic.png

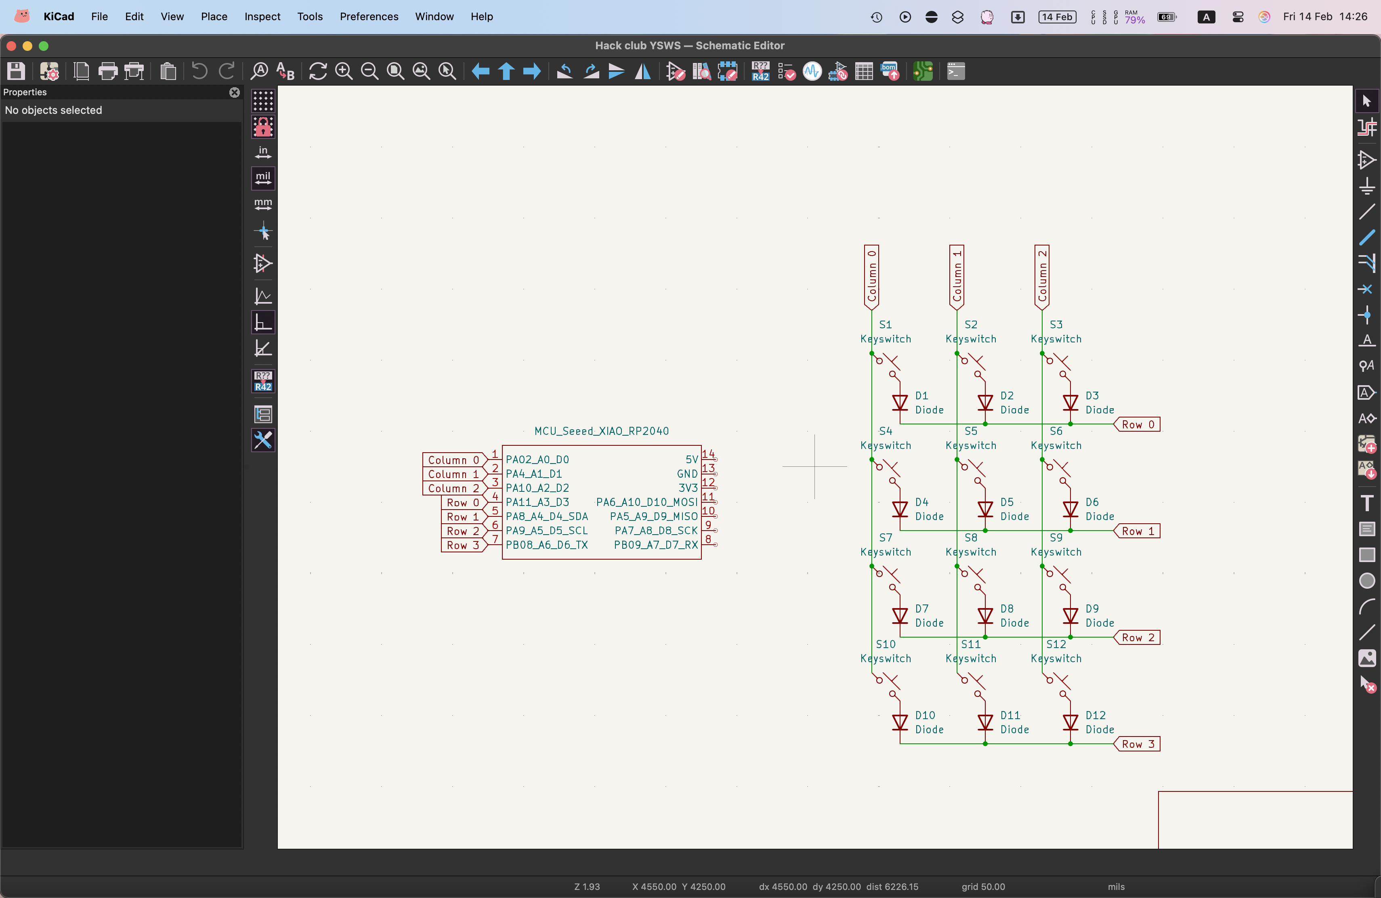
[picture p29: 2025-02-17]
hackpads/Shortycuts/assets/Schematic.png

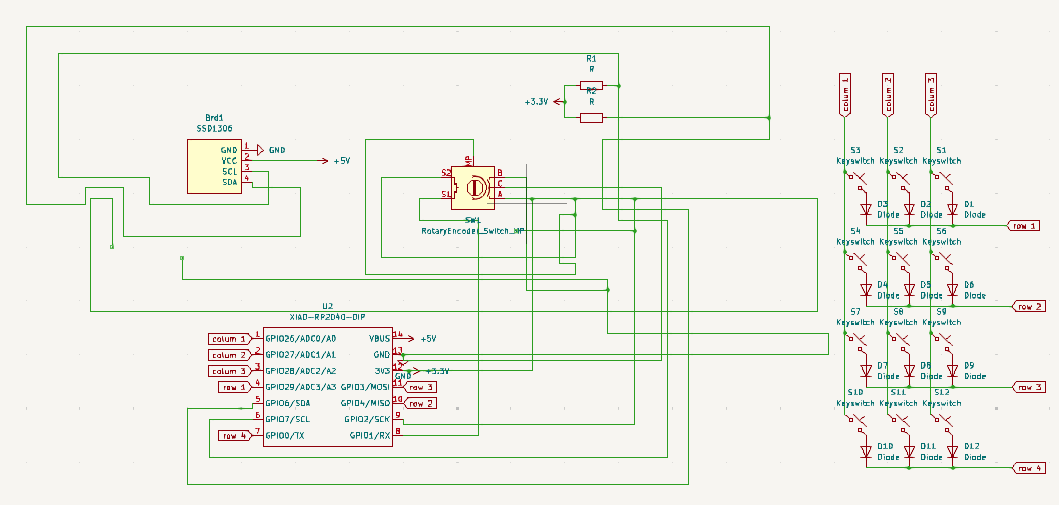
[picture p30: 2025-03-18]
hackpads/Astral_Hack_Pad/assets/schematic.png

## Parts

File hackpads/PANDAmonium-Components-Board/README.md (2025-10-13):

# PANDAmonium Components Board
The PANDAmonium Components board is a panda themed macropad designed by me (kai pereira);

It's a simple 9 key layout with some fun LED's and silly design.

I'm really happy I did this project because it heavily inspired me to turn away from just software and build more hardware projects.

## What I want to use it for
I want to use my macropad to potentially make some complicated VIM motions like search and replace or smth and maybe for optimizing the browser experience.

## Features
- 9 keys
- RGB LED's
- Panda themed case

## Screenshots

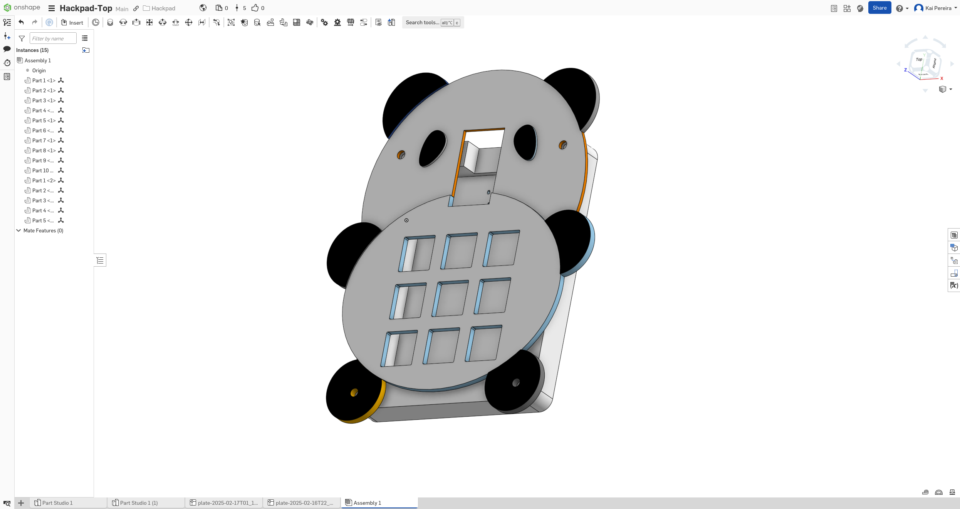
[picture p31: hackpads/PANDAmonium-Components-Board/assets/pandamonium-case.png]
case Case

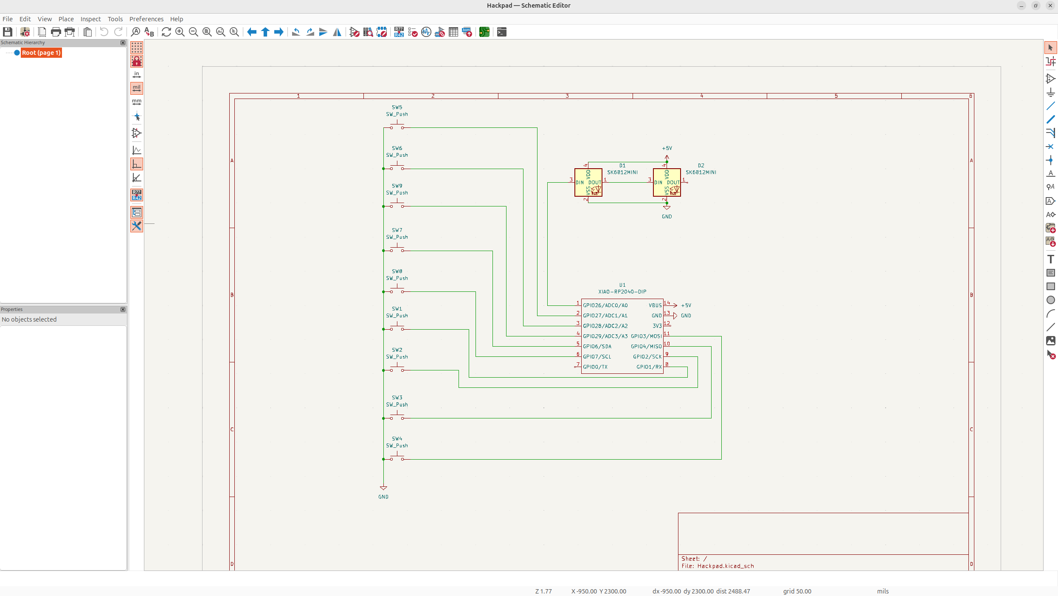
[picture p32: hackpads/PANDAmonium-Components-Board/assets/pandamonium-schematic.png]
schematic Schematic

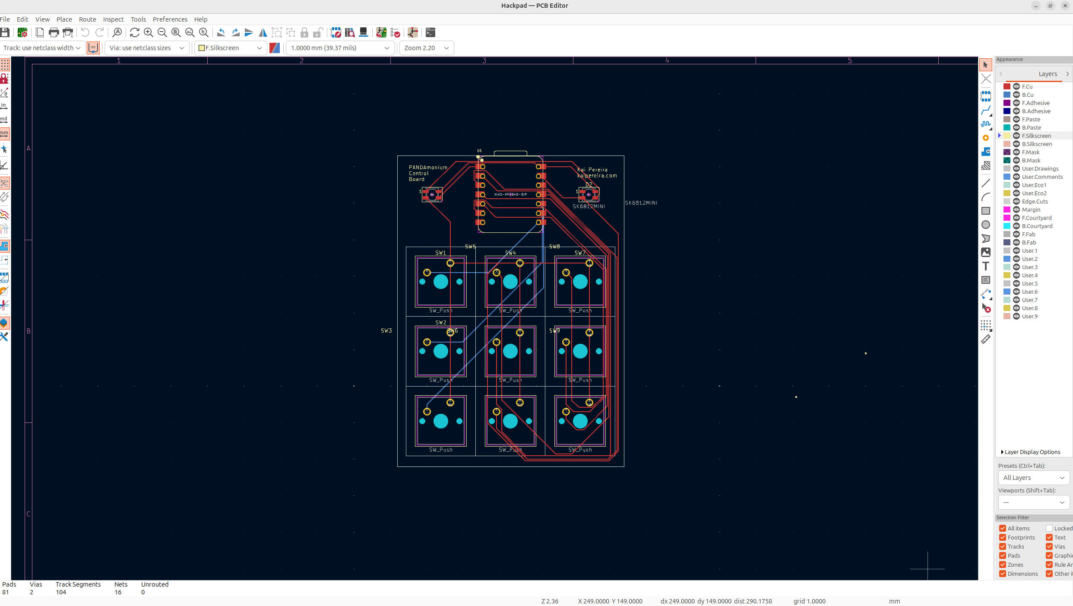
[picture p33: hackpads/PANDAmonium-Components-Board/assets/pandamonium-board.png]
board Board


## BOM

- 1x XIAO-RP2040-DIP
- 9x Cherry MX Switches
- 2x SK6812 MINI LED

Expanded BOM in /PCB/BOM.csv

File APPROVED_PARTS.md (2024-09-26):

# List of approved parts

Here is the list of approved parts!! If there's anything you think should be here please send it in #hackpad!

NOTE: For parts that we do *not* have at HQ, it may take significantly longer (1-2+ more weeks) for your parts to arrive. 

NOTE 2: If you use any SMD parts (including hotswap sockets!), I will *not* solder any of it for you!!

## Parts at HQ
- Seeed XIAO RP2040 through-hole [MANDATORY TO INCLUDE]
- 1N4148 Diodes (through hole)
- MX-Style switches
    - Gateron Milky Yellows
- EC11 Rotary encoders

## Other allowed parts

ANY SMD PARTS

### Microcontrollers:
- ESP8266 modules

### Switches
- Kailh Choc V2s

### Other
- Kailh Hotswap sockets (MX STYLE ONLY)
- Mill-Max 0305s

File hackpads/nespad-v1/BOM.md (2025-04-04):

# BOM:
- 6x Cherry MX switches
- 1x SEEED XIAO DIP RP2040
- 1x PCB

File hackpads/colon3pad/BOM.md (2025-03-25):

# BOM

For PCB:
- 1x Seeed Studio XIAO RP2040 
- 1x SSD1306 128x32 OLED 
- 16x Kailh Choc V2 switches
- 16x SK6812-E reverse mount NeoPixel LEDs
- 16x 1N4148 diodes 

For Case:
- Case is 3D printed with PLA
- 4x M3x12mm screws
- 4x M3 hex nuts
- 4x M3x5mx4mm heatset inserts
- 15x 1u low profile key caps ([compatibility list](https://docs.google.com/spreadsheets/d/1ylYmEZ1jNiPuHWl6rjiI3xzooOwUTS33BZfYSW-n7Ok/edit?gid=0#gid=0))
- 1x 2u low profile key cap

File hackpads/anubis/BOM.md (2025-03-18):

# BOM
 - 14x MX-Style switches
 - 2x EC11 Rotary encoders
 - 12x Through-hole 1N4148 Diodes
 - 1x Seeed XIAO RP2040
 - 14x Blank DSA keycaps
 - 4x M3x16mm screws
 - 4x M3x5mx4mm heatset inserts
 - 2x 4.7kΩ resistors
 - 1x MCP23017 IO Expander

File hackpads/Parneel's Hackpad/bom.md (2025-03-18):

| Component | Qty | Comments |
|---|-----|---|
| XIAO RP2040 | 1 | |
| EC11 Rotary Encoder | 1 | |
| Cherry MX-style switches | 12  | will be ordering [custom switches](https://divinikey.com/products/gateron-smoothie-linear-switches) w/ grant if possible |
| 1N4148 diodes | 12  | |
| 0.91" SSD1306 OLED | 1 | |
| 1U Keycaps | 12  | preferably mostly white with a few red/black ones |
| M3x16 screws | 4 | |
| M3 heat-set inserts | 4 | |
| Case.stl | 1 | black if possible |
| Plate.stl | 1 | black if possible |
| Knob.stl | 1 | black if possible |
| PCB | 1 |

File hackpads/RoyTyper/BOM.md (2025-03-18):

# Bill Of Materials

### Name - Link(just for example, doesn't have to be from there)

XIAO RP2040 Microcontroller - [here](https://www.amazon.in/Microcontroller-Dual-Core-MicroPython-CircuitPython-Interfaces/dp/B09NNVNW7M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) (x1)

1N4148 / Diodes - [here](https://www.digikey.com/en/products/detail/onsemi/1N4148/458603) (x9)

Cherry MX Keys - [here](https://www.amazon.in/dp/B09ZT8BY6W/ref=twister_B0BFGC2MJY?_encoding=UTF8) (x9)

SK6812 Mini - [here](https://keeb.io/products/sk-6812-mini-e-rgb-leds-12-pack) (x3)

EC11 Rotary Encoder - [here](https://keeb.io/products/rotary-encoder-ec11) (x1)

1.7mm(diameter)x10mm screws (x4)  - [here](https://www.moddiy.com/products/M1.7-x-10mm-Black-Screws-(PM1.7X10).html)

Blank DSA Keycaps (Black)(x9) - [here](https://meckeys.com/shop/accessories/keyboard-accessories/keycaps/blank-dsa-keycaps-1u/)

EC11 Rotary Encoder knob (Black)(x1) - Couldn't find any

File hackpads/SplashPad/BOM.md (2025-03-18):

# SplashPad - Bill of Materials

Welcome to the **Bill of Materials (BOM)** – the sacred scroll of **everything** needed for my SplashPad. 

*(Because nothing’s worse than realizing you forgot the screws after your parts arrive.)* 

| **Component** | **Qty** |
|---|---|
| **XIAO RP2040** | 1 |
| **SK6812 Mini LEDs** | 14 |
| **Rotary Encoder** | 1 |
| **Cherry MX Switches** | 9 |
| **PCB** | 1 |
| **Diodes (1N4148)** | 9 |
| **M3x8 Bolt** | 4 |

Others:

| **Component** | **Qty** |
|---|---|
| **1U Keycaps** | 9 |
| **KMK Firmware** | 1 |
| **PCB** | 1 |
| [**Case Top.stl**](./CAD/STL/SplashPad%20Case%20-%20Case%20Top.stl) | 1 |
| [**Case Bottom.stl**](./CAD/STL/SplashPad%20Case%20-%20Case%20Bottom.stl) | 1 |
| **Knob.stl** | 1 |

### Notes:
It would be awesome to have the crown parts printed in black! (Files in [production folder](./Production).)<br>
I can print the knob.<br>
I am buying the M3x8 Bolts.<br>

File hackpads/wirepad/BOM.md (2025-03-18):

# BOM

- 1x Seeed XIAO - RP2040 (THT)
- 1x 0.96" 4-pin I2C OLED display
- 12x 1N4148 THT diodes
- 12x MX-style switches (15x15 mm from the approved parts)

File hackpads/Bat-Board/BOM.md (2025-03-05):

## BOM
- 13x Cherry MX Switches
- 4x SK6812 MINI Leds
- 1x XIAO RP2040
- 4x Blank DSA Keycaps
- 9x M3x16 Bolt
- 9x M3 Heatset
- 1x 0.91" 128x32 OLED Display
- 13x Through-hole 1N4148 Diodes
- 1x Red Blank DSA keycaps
- 4x White Blank DSA keycaps
- 9x Black Blank DSA keycaps
- 9x M3 hex nuts

Extras:-
- Few Jump Wires
- Breadboard
- A soldering iron and its required materials
For testing before placing
- a sd card

Others:
- KMK Firmware
- Top Case.stl 
- Bottom Case.stl

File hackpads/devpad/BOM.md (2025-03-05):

# **BOM**
- 2x LED_SK6812MINI_PLCC4_3.5x3.5mm_P1.75mm
- 4x Cherry MX Switches
- 1x SEEED Xiao RP2040

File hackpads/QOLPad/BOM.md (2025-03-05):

To make this project, I'll need:
- 6x Cherry MX Switches
- 6x Blank DSA Keycaps
- 1x EC11E Rotary Encoder
- 6x 1N4148 Diodes
- 6x SK6812 Mini-E LEDs
- 1x XIAO RP2040 Microcontroller
- 4x M3 Heatset
- 4x M3x16 Bolt

- 1x Case (Top case printed in black, bottom in black if possible)

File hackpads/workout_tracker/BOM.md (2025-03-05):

# BOM:
2x Cherry MX switches
1x EC11 Encoder
1x PCB - black with white drawings if possible
3x Through-hole resistors (5k)
1x 0.96" OLED
3D printed case

Self-provided SD card reader (supported but optional)

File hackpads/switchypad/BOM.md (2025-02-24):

# BOM

| Footprint | Quantity | Designation |
|---|---|---|
| SW_Cherry_MX_1.00u_PCB | 9 | SW_Push |
| LED_SK6812MINI_PLCC4_3.5x3.5mm_P1.75mm | 2 | SK6812MINI |
| XIAO-RP2040-DIP | 1 | XIAO-RP2040-DIP |
| D_DO-35_SOD27_P7.62mm_Horizontal | 9 | 1N4148 |

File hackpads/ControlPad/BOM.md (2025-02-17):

# BOM:
- 12x Cherry MX switches
- 1x EC11 Rotary Encoder
- 12x Through-hole 1N4148 Diodes
- 1x 0.91" OLED
- 4x M3x5mx4mm heatset inserts
- 4x M3x16mm screws

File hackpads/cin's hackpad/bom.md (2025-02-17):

# Bill Of Materials

Here should be everything you need to make this hackpad.
- 5x Cherry MX Switches
- 5x DSA Keycaps
- 4x M3x5mx4mm heatset inserts
- 4X M3x16mm screws
- 2x SK6812MINI LEDs
- 1x XIAO RP2040
- 1x Case (2 printed parts)
#### The following will be sourced with my grant. All costs are in USD:
- 1x PCB (It cost 14.08 USD to make and ship. $2.00 for 5x + 12.08 for shipping from JLCPCB)
### Total before tax: $14.08

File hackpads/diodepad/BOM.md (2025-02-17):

# BOM
<hr>
<ul>
    <li>10x Cherry MX switches</li>
    <li>10x DSA Keycaps</li>
    <li>1x 0.91" 128x32 OLED screen</li>
    <li>10x DO-35 1N4148 Diodes</li>
    <li>4x M3 Headset</li>
    <li>4x M3x16 Bolt</li>
    <li>XIAO RP2040</li>
</ul>

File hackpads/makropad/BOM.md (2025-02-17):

# Makropad BOM

| Quantity | Component Description |
|---|---|
| 10x | Kailh choc v2 switches (Brown/Blue, or any other color) |
| 8x | Red Keycaps |
| 2x | White Keycaps |
| 6x | Normal front-mounted SK6812-MINI SMD LEDs (SK6812mini-012) |
| 2x | EC11 Rotary encoders |
| 1x | 0.91" OLED display |
| 1x | Seeed Studio XIAO RP2040 |
| 5x | M3 hex nuts |
| 5x | M3x5mx4mm heatset inserts |
| 5x | M3x16mm screws |
| 12x | SMD Diodes (1N4148W) |
| 6x | 10kΩ SMD 1206 resistors |
| 16x | 100nF SMD 1206 capacitors | 
| 1x | PCF8574A I2C I/O expander |
| 10x | Reverse-mounted SK6812MINI-E SMD LEDs |

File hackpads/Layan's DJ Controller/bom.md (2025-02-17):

# Hackpad - Bill of Materials

- 1x XIAO SEEED RP2040: XIAO-RP2040-DIP
- 1x MCP23017-SO: Package_SO:SOIC-28W_7.5x17.9mm_P1.27mm
- 2x LEDs: LED_SK6812MINI_PLCC4_3.5x3.5mm_P1.75mm
- 2x Bourns slide potentiometer: TRIM_PTA4543-2015DPA103
- 2x 4.7kΩ resistors: R_Axial_DIN0204_L3.6mm_D1.6mm_P7.62mm_Horizontal
- 8x Cherry MX switches: SW_Cherry_MX_1.00u_PCB
- 2x Alps rotary encoders: RotaryEncoder_Alps_EC11E_Vertical_H20mm

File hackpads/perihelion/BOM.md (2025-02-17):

# BOM

This file contains all the components you need to build your own Perihelion. 

| Component | Qty |
|---|---|
| XIAO RP2040 | 1 |
| SK6812MINI LEDs | 7 |
| Cherry MX Switches | 4 |
| 1U Keycaps | 4 |
| PCB | 1 |
| OLED Display 128x32 | 1 |

You also need the case for the Perihelion! It's included in the CAD folder.

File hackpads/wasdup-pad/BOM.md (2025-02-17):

# Bill Of Materials for wasdup_pad

## The big parts

- 1x Case (2 printed parts)
- 1x PCB of the keyboard

## For the PCB

- 1x XIAO RP2040
- 4x 3.5x3.5mm LED
- 2x 4.7kΩ horizontal resistors
- 2x 6mm Push button
- 4x Cherry MX switches
- 1x 0.96" 128x64 OLED Display

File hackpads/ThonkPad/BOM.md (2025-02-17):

List of Materials:
- 3D printed base + side housing (black if possible)
- 1 Seeed XIAO RP2040
- * 1N4148 Diodes
- 6 MX-Style switches
- 1 EC11 Rotary encoder
- 1 0.91 inch OLED displays
- Blank DSA keycaps (preferably black but white is the second choice)
- 5 M3x16mm screws
- 55 M3 hex nuts

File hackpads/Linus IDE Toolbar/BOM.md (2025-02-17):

# BOM

## Components

- 5x Cherry MX key switches
- 1x SSD1036 OLED 128x32 0.96"
- 2x WS2812B LEDs
- 1x PCB
- 1x Red DSA key cap
- 4x Black DSA key caps

## Colours
I'd like the case to be black if possible.

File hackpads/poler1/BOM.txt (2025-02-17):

BOM for poler1

1. PCB in white color
2. Seeed XIAO RP2040
3. 6 Gateron Jupiter Red Switches
4. 6 Blank Keycaps (Black Color)
5. 16 SK6812 MINI-E LEDs
6. 4 M3x16mm screws
7. 4 M3 hex nuts
8. 6 Through-hole 1N4148 Diodes
9. Soldering Iron
10. Pin Cutter
11. 0.96 inch OLED display
12. EC11 Rotary encoders

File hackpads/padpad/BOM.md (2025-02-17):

# BOM
- 1x SEEEDUINO XIAO RP2040
- 1x 0.91 inch OLED display (128x32)
- 6x Cherry MX Switches
- 6x DSA Keycaps
- 4x same screws as orpheuspad and corresponding nuts
- 3D Printed Case

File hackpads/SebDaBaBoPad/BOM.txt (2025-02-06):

### BOM for SebDaBaBoPad

PCBs
3-part case
20 Gateron Jupiter Banana Switches
Mill-Max 0305s for switches
Set of DSA keycaps
23 1N4148 Diodes (through hole)
2 WS2812B
Screws & heatsets for 2.9mm hole
ESP8266 module for WiFi
IO/Port expander

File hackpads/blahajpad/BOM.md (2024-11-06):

## BOM

 - 2x Case Parts (printed in Black)
 - 17x Gateron milky yellow switches
 - 2x Plate-mounted 2U Vertical stabilisers
 - 1x Plate-mounted 2U stabiliser
 - 1x EC11 Rotary Encoder
 - 1x 0.91" 128x32 SSD1306
 - 1x SEEED XIAO RP2040
 - 17x 1N1418W Diodes
 - 17x Reverse-Mount SK6812-E
 - 4x 4.7kΩ resistors
 - 1x MC23017 i2c expander
 - 34x Mill-Max 0305 Hotswap Sockets
 - 10x white keycaps
 - 4x <any colour> keycaps
 - 2x <same as above colour> 2U Vertical Keycaps
 - 1x <again same colour>2U Keycap
 - 4x M3x4 Heatset Inserts
 - 4x M3x6 Screws

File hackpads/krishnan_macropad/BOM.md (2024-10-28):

# Bill of Materials

- 1x PCB (black if possible)
- 1x case (black, no supports needed)
- 4x M3 screws and heatsets (same as OrpheusPad)
- 1x Seeed XIAO RP2040 through-hole
- 9x Cherry MX switches
- 9x blank DSA keycaps (light gray or white if possible)

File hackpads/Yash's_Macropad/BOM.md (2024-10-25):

Bill of Materials:
- 1x Xiao rp2040 Thru-Hole
- 9x Gateron Milky Yellows
- Keycaps
- 10 Diodes
- 2 4.7K thru-hole resistors
- 1x Rotary Encoder
- 1x Rotary Encoder Cap
- 1x 0.91 OLED Display
- 4 heatset inserts
- 2 M3 16mm screws
- 2 M3 12mm screws

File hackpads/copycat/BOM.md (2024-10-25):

# Bill of Materials (BOM)

## Project Name: CopyCat (Ctrl C & V) Macropad

| Description | Quantity | Notes |
|---|---|---|
| [Cherry MX switches] | [3] | [Any notes] |
| [Through-hole Seeed Xiao RP2040] | [1] | [Any notes] |
| [Through Hole LED] | [3] | [https://kono.store/products/1-8mm-keyboard-leds-100-pack] |
| [0.25W Resistor] | [3] | [https://www.digikey.com/en/products/detail/yageo/CFR-25JB-52-68R/2832?s=N4IgTCBcDaIGwA4CKAhA0gWgHIBEQF0BfIA] |
| [4 screws (from tutorial?)] | [4] | [Any notes] |

## Additional Notes
- If possible, please print the case in black, the pcb purple, and white keycaps, tysmm

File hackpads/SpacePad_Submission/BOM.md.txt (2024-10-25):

BOM materials:
- 12x Cherry MX Switches
- 12x through hole 1N4148 Diodes
- 1x SEEED Studio XIAO RP2040
- 1x PCB
- 3d case (whole case black, the "spacepad" text is blue)
- 4x M3 screw

Note: please solderate it

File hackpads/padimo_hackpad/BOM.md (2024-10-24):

# BOM:
4x Cherry MX switches
1x EC11 Encoder
1x PCB - black with white drawings if possible
4x Through-hole 1N4148 Diodes
1x 0.96" OLED
3D printed case

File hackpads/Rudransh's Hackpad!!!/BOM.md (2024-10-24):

# BOM : 

1) 15 MX style switches
2) 1 xiao rp2040
3) 15 1N4148 Diodes (through hole) 
4) case - should be white in color  
5)  pcb 
6) 15 keycaps ( Red color ) 
7) Need 8 M3 screwholes
8) 8x m3 screws

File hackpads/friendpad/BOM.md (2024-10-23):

### Bill of Materials
| Component | Quantity  |  
| --- | --- |
| Seeed Studio XIAO RP2040 | 1 |
| PCF8574A IO Expander | 1 |
| Gateron Milky Yellows MX Switches | 12 |
| EC11 Rotary Encoder | 2 |
| 1N4148 Diodes | 14 |
| THT 4.7k Ohm Resistors | 3 |
| 0.96 inch SSD1306 OLED | 1 |
| DSA Keycaps | 12 |
| Encoder Caps | 2 |
| M3x20mm Screws | 4 |

### Additional Notes  
Shapr3D wouldn't let me change the colours for the cad:  
- keycaps are stuck as red in the .3mf, but they can be any colour  
- would prefer if case could be printed in black

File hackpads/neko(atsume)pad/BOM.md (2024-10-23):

## BOM (Bill of materials)

 - 12x Diodes
 - 11x Gateron Milky Yellow Switches
 - 22x Mill-Max 0305 Hotswap Sockets
 - 17x Keycaps
 - 1x Custom Hack Club Keycap (promised like [here](https://www.youtube.com/watch?v=PBGjZdLGUp4&t=32m22s))
 - 1x SSD1306 0.91" 128x32 OLED display
 - 1x EC11 Rotary Encoder (with switch :3)
 - 1x SEEED Xiao RP2040
 - 4x M3x4 Heatset Inserts
 - 4x M3x6 Screws
 - 1x 3D Printed Case (Yellow please!)
 - 1x 3D Printed top plate (also Yellow please!)

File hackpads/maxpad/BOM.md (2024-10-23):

1x rp2040 xiao
12x gateron milky yellows
1x 0.96in oled display
1x ec11 rotary encoder
12x 1N4148 through hole Diodes

think that's it

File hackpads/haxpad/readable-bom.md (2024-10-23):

# Bill of Materials for my hackpad

## Components List

1. **Display**
   - Quantity: 1
   - Component: SSD1306 128x64 OLED Display
   - Reference Designator: Brd1

2. **Rotary Encoder**
   - Quantity: 1
   - Component: EC11E15244C0 Rotary Encoder
   - Reference Designator: U1
   - Footprint: EC11B202440M

3. **Diodes**
   - Quantity: 9
   - Component: Through-hole Diodes (DO-35 package)
   - Reference Designators: D1, D2, D3, D4, D5, D6, D7, D8, D9

4. **Mechanical Switches**
   - Quantity: 9
   - Component: MX-style Hot-swappable Keyswitches (1U size)
   - Reference Designators: S1, S2, S3, S4, S5, S6, S7, S8, S9
   Note: I preferably want to use the Gazzew Boba U4T Switches

5. **Microcontroller**
   - Quantity: 1
   - Component: Seeed XIAO RP2040 Microcontroller
   - Reference Designator: U2

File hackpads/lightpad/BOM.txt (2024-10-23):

1x Seeed Studio Xiao RP2040
1x 0.91" OLED Display
1x Microchip Technology MCP23017 IO Expander
3x 4.7k THT Resistor
16x WS2812B Neopixel SMD
16x Cherry MX Switch (Gateron Milky Yellows)
19x 1N4148 Diode (through hole)
3x EC11 Rotary Encoder (With Switch)

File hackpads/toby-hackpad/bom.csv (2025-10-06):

Quantity | Part
1 | PinHeader_1x16_P2.54mm_Vertical
12 | LED_SK6812MINI_PLCC4
10 | SW_Cherry_MX
1 | C-100nF-0603
1 | MCP23017_SO
5 | C-1uF-0603
2 | R-4.7K-0603
1 | XIAO-RP2040-DIP
1 | RotaryEncoder_Alps_EC11E-Switch

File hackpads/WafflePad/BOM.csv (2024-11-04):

Id | Designator | Footprint | Quantity | Designation | Supplier and ref
1 | SW1,SW6,SW3,SW2,SW5,SW4 | SW_Cherry_MX_1.00u_PCB | 6 | SW_Push
2 | ,, |  | 3
3 | D3,D2,D6,D1,D4,D5 | D_DO-35_SOD27_P7.62mm_Horizontal | 6 | 1N4148
4 | U1 | XIAO-Generic-Thruhole-14P-2.54-21X17.8MM | 1 | Seeed Studio XIAO SAMD21
5 | SW7 | Bourns-PEC11R-4220F-S0024-0-0-0 | 1 | RotaryEncoder_Switch

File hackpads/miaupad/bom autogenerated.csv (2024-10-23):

Id | Designator | Footprint | Quantity | Designation | Supplier and ref
1 | SW4,SW6,SW3,SW1,SW2,SW7 | 1U-Switch | 6 | SW_Push_45deg
2 | SW5 | RotaryEncoder_Alps_EC11E-Switch_Vertical_H20mm | 1 | RotaryEncoder_Switch
3 | D2,D6,D8,D9,D7,D5,D1 | Diode_DO-35 | 7 | D
4 | U1 | XIAO | 1 | MOUDLE-SEEEDUINO-XIAO
5 | U2 | SSD1306-0.91-OLED-4pin-128x32 | 1 | DM-OLED096-636

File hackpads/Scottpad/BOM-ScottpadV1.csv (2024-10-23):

ID | Name | Designator | Footprint | Quantity | Manufacturer Part | Manufacturer | Supplier | Supplier Part | Price
1 | DIODE_1N4007 | D1,D2,D3,D4,D5,D6,D7,D8,D9 | DIODE_1N4007 | 9 | 1N4007 | ST(先科) |  | C106903 | 0.017
2 | PEC11R-4015F-S0024 | ENC1 | SW-TH_PEC11R-4XXXF-SXXXX | 1 | PEC11R-4015F-S0024 | BOURNS | LCSC | C143789 | 2.292
3 | HS91L02W2C01 | OLED1 | OLED-TH_L38.0-W12.0_HS91L02W2C01 | 1 | HS91L02W2C01 | HS(汉昇) | LCSC | C5248081 | 1.992

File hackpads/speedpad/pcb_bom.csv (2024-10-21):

Reference | Value | Datasheet | Footprint | Qty
Brd1 | SSD1306 |  | custom library:SSD1306-0.91-OLED-4pin-128x32 | 1
D1,D2,D3,D4,D5,D6,D7,D8,D9 | D | ~ | custom library:DIODE-1N4148 | 9
R1,R2 | 4.7k | ~ | Resistor_THT:R_Axial_DIN0204_L3.6mm_D1.6mm_P5.08mm_Horizontal | 2
SW1,SW2,SW3,SW4,SW5,SW6,SW7,SW8,SW9 | SW_Push | ~ | Button_Switch_Keyboard:SW_Cherry_MX_1.00u_PCB | 9
SW10 | RotaryEncoder_Switch | ~ | Rotary_Encoder:RotaryEncoder_Alps_EC11E-Switch_Vertical_H20mm | 1
U2 | MCU_Seeed_XIAO_RP2040 |  | custom library:XIAO-RP2040 | 1

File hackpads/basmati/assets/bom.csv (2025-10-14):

Id | Designator | Footprint | Quantity | Designation | Supplier and ref
1 | D2,D1 | LED_SK6812MINI_PLCC4_3.5x3.5mm_P1.75mm | 2 | SK6812MINI
2 | U1 | XIAO-RP2040-DIP | 1 | XIAO-RP2040-DIP
3 | SW1,SW2,SW4,SW3 | SW_Cherry_MX_1.00u_PCB | 4 | SW_Push

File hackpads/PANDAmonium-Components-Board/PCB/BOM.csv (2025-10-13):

Id | Designator | Footprint | Quantity | Designation | Supplier and ref
1 | SW6,SW9,SW1,SW4,SW7,SW2,SW5,SW3,SW8 | SW_Cherry_MX_1.00u_PCB | 9 | SW_Push
2 | D1,D2 | LED_SK6812MINI_PLCC4_3.5x3.5mm_P1.75mm | 2 | SK6812MINI
3 | U1 | XIAO-RP2040-DIP | 1 | XIAO-RP2040-DIP

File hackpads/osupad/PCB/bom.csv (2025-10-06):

Id | Designator | Footprint | Quantity | Designation | Supplier and ref
1 | SW3,SW4,SW2,SW1 | SW_Cherry_MX_1.00u_PCB | 4 | SW_Push
2 | U1 | XIAO-Generic-Hybrid-14P-2.54-21X17.8MM | 1 | MOUDLE-SEEEDUINO-XIAO
3 | SW5 | RotaryEncoder_Alps_EC11E-Switch_Vertical_H20mm | 1 | RotaryEncoder_Switch

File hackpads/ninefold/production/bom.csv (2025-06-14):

Designator | Footprint | Quantity | Value | LCSC Part #
D1, D2, D3, D4, D5, D6, D7, D8, D9 | Diode_DO-35 | 9 | Diode
S1, S2, S3, S4, S5, S6, S7, S8, S9 | MX_Plate_1.00u | 9 | Keyswitch
U1 | XIAO-RP2040-DIP | 1 | XIAO-RP2040-DIP

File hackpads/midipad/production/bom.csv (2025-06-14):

Id | Designator | Footprint | Quantity | Designation | Supplier and ref
1 | OLED1 | OLED-TH_L38.0-W12.0_HS91L02W2C01 | 1 | HS91L02W2C01
2 | D15,D14,D13 | LED_SK6812MINI_PLCC4_3.5x3.5mm_P1.75mm | 3 | SK6812MINI
3 | SW14,SW13,SW15 | RotaryEncoder_Alps_EC11E-Switch_Vertical_H20mm_CircularMountingHoles | 3 | RotaryEncoder_Switch
4 | U1 | XIAO-RP2040-DIP | 1 | XIAO-RP2040-DIP
5 | D9,D5,D12,D11,D10,D7,D3,D6,D1,D8,D2,D4 | D_DO-35_SOD27_P7.62mm_Horizontal | 12 | D
6 | SW5,SW1,SW9,SW2,SW8,SW10,SW3,SW7,SW12,SW6,SW4,SW11 | SW_Kailh_Choc_V2_1.00u | 12 | SW_Push
7 | U2 | SOIC-28W_7.5x17.9mm_P1.27mm | 1 | MCP23017_SO
8 | R2,R1 | R_Axial_DIN0204_L3.6mm_D1.6mm_P7.62mm_Horizontal | 2 | 4.7k

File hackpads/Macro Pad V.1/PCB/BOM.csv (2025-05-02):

ID | Name | Designator | Footprint | Quantity | Manufacturer Part | Manufacturer | Supplier | Supplier Part | Price | Pins | Contributor | JLCPCB Part Class | link
1 | DISPLAY-OLED-128X64-I2C | 1 | DISPLAY-OLED-128X64-I2C | 1 |  |  |  |  |  | 4 | Ferran Soliva Alvarez
2 | 1N4148 | D1,D2,D3,D4 | 1N4148_1N4148W | 4 |  |  |  |  |  | 2 | lkjhwnsgur
3 | SK6812MINI-EA ASM | LED1,LED2,LED3,LED4,LED5,LED6 | LED-SMD_4P-L3.2-W2.8_SK6812MINI-EA ASM | 6 | SK6812MINI-EA | 欧思科光电 | LCSC | C5378731 | 0.099 | 4 | lcsc | Extended Part
4 | 10kΩ | R1,R2,R3 | RES_TH_250MW | 3 | RN 1/4W 10K F T/B A1 | Tyohm(幸亚电阻) | LCSC | C410695 | 0.01 | 2 | Deepak Sahu | Extended Part
5 | Cherry MX brown | S1,S2,S3,S4 | MX1A | 4 | MX1A-11NW |  | Mouser | 540-MX1A-11NW |  | 2 | thijsvader |  | http://cherryamericas.com/wp-content/uploads/2014/12/mx_cat.pdf
6 | Seeed XIAO RP2040 ALL PINS | U1 | SEEED XIAO RP2040 | 1 | 102010328 | Seeedstudio |  |  |  | 20 | Derick2k |  | https://www.seeedstudio.com/Seeeduino-XIAO-Arduino-Microcontroller-SAMD21-Cortex-M0+-p-4426.html
7 | ROTARY_ENCODERS_EC11 | U2,U3 | ROTARY_ENCODERS_EC11 | 2 |  |  |  |  |  | 7 | Gona_Order

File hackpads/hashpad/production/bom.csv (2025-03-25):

Designator | Footprint | Quantity | Value | LCSC Part #
D1, D10, D2, D3, D5, D6, D7, D8, D9 | D_DO-35_SOD27_P7.62mm_Horizontal | 9 | 1N4148
D11, D12, D13, D14, D15, D16, D17, D18, D4 | SK6812MINI-E | 9 | SK6812MINI
J1 | OLED_128x64 | 1 | OLED_128x64
SW1, SW2, SW3, SW4, SW5, SW6, SW7, SW8, SW9 | MX_PCB_1.00u | 9 | SW_Push
SW10 | Encoder_EC11_MX | 1 | RotaryEncoder_Switch
U2 | Seeed_XIAO_RP2040 | 1 | XIAO-RP2040-DIP

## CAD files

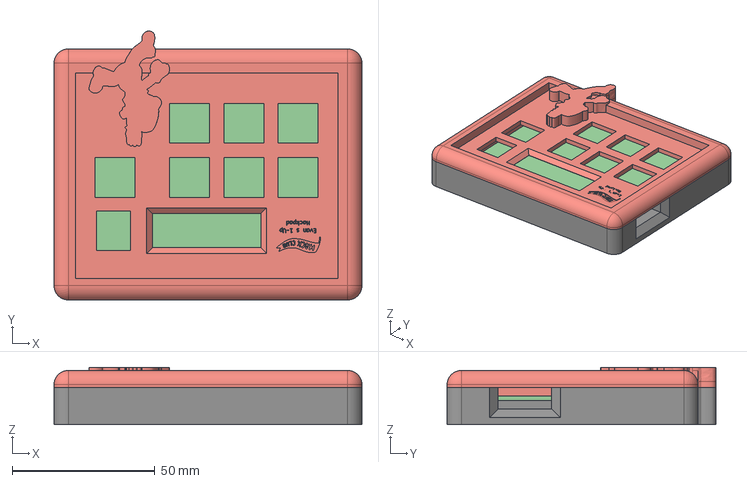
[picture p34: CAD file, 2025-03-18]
hackpads/1-Up-Hackpad/cad/Hackpad Full Model.step
108.0 x 94.3 x 20.1 mm

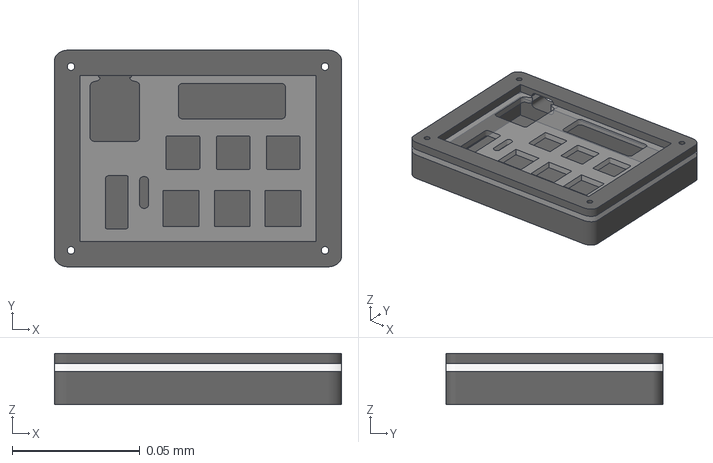
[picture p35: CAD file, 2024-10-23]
hackpads/3XAY_Hackpad/CAD/3MF/fullHackPad.3mf
0.112 x 0.0848 x 0.02 mm

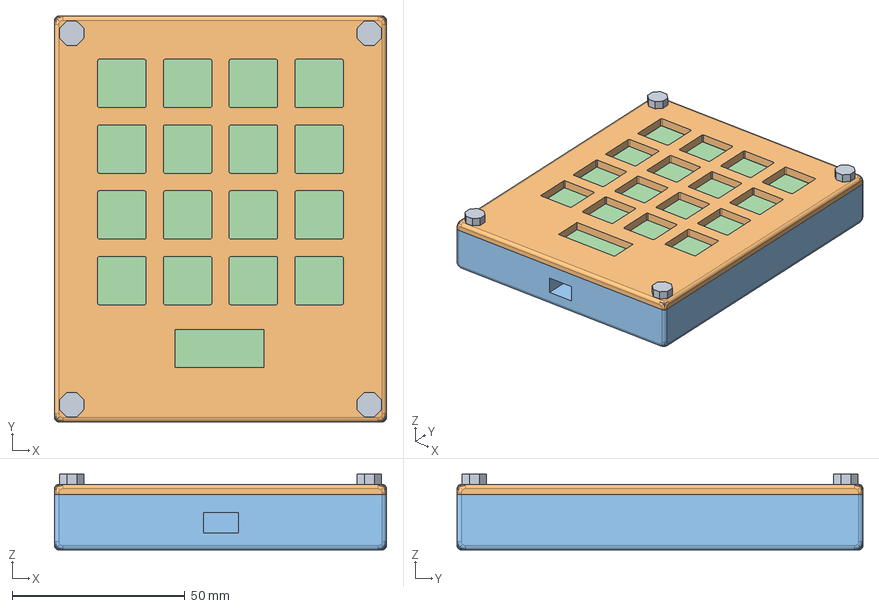
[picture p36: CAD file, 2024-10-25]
hackpads/buildpad/cad/Buildpad Assembled.step
96.2 x 117.6 x 22.0 mm
Screw x 4
Case Top
Case Bottom

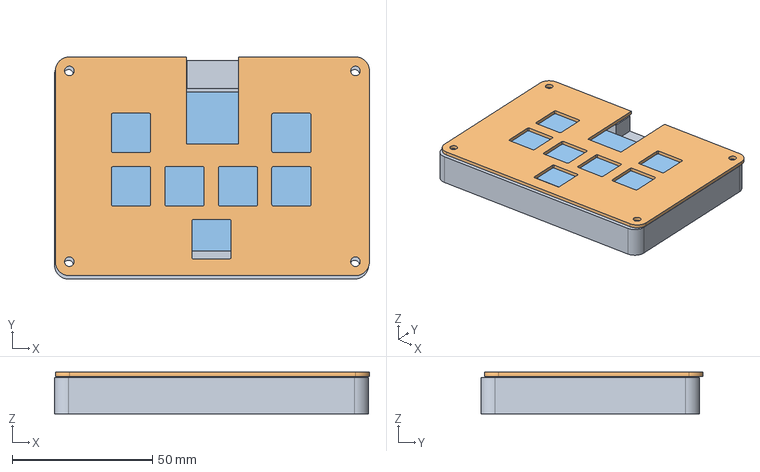
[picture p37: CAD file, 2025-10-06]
hackpads/ChessPad/CAD/Assembled_Case.step
112.3 x 79.2 x 14.9 mm

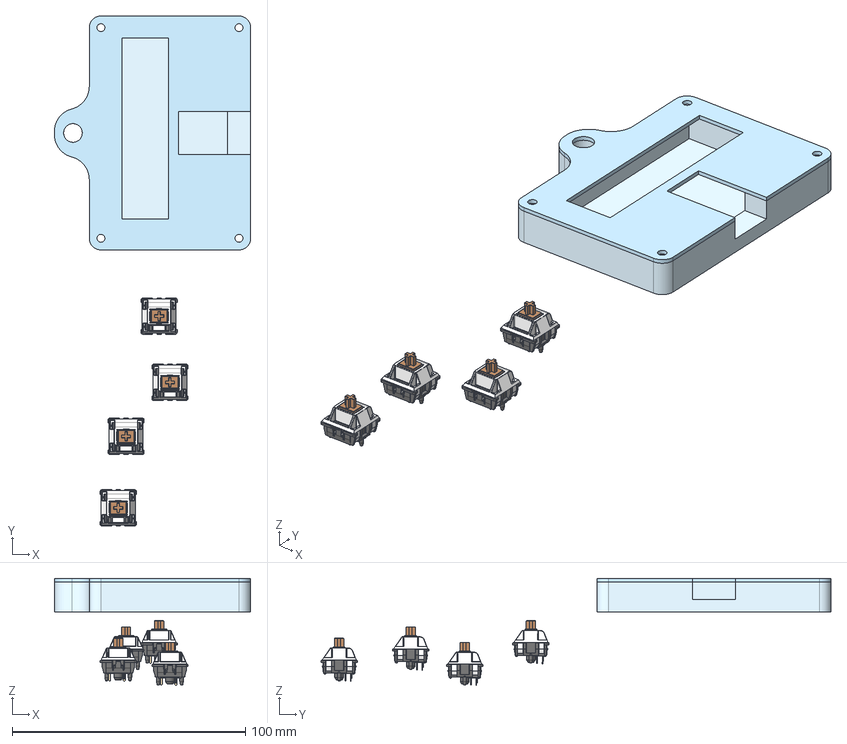
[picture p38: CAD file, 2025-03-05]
hackpads/devpad/CAD/Assembly 1 CAD.step
84.3 x 218.9 x 46.1 mm
SW_Cherry_MX_PCB_cp x 28

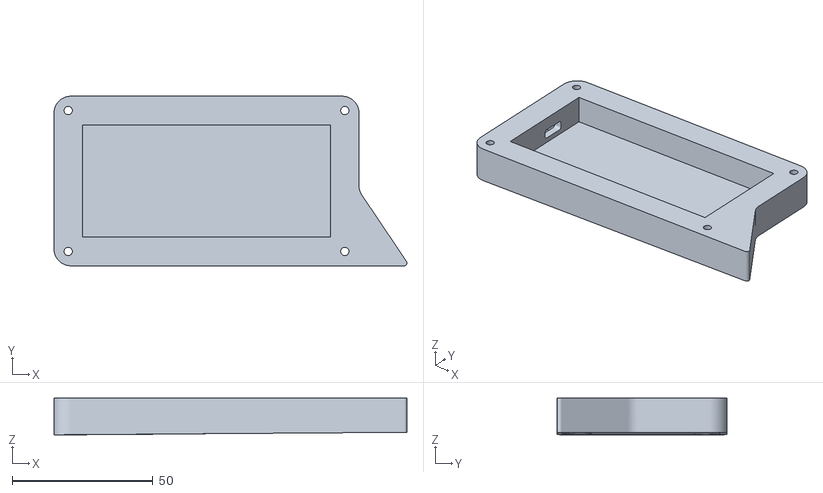
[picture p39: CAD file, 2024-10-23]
hackpads/Dinopad/production/case/main_case.stl
125.2 x 60.2 x 13.0

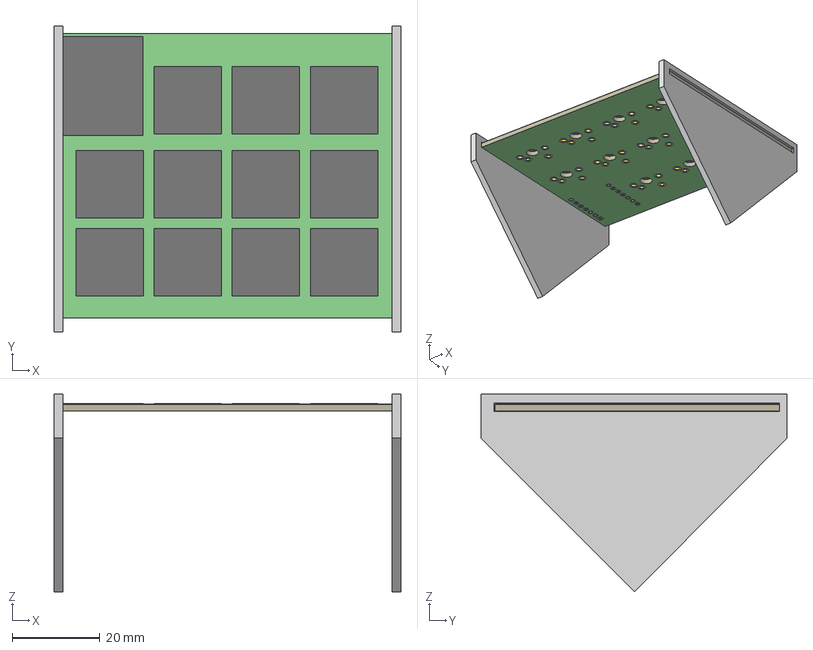
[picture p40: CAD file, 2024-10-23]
hackpads/dmcegan/cad/Full Hackpad Case.step
79.0 x 69.8 x 45.0 mm
Board
1-copper
16-copper
1-soldermask
16-soldermask
XIAO-GENERIC-THRUHOLE-MODULE14P-2.54-21X17.8MM
CHERRY-MX x 11

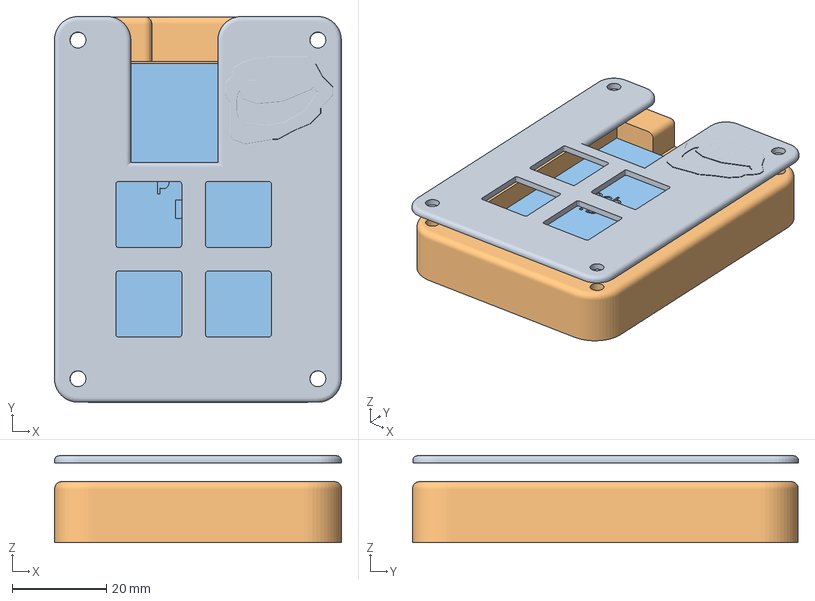
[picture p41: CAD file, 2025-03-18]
hackpads/hackpadtrollface/cad/hackpadtrollface assembled.3mf
61.0 x 82.1 x 18.6 mm
Untitled v3

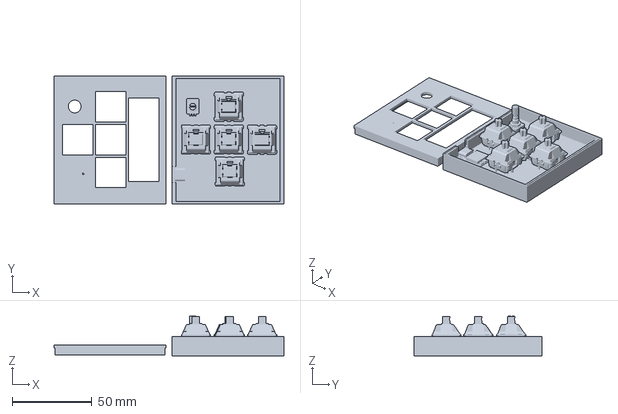
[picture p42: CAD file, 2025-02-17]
hackpads/HackPanel/CAD/HackPanelAssembled.3mf
144.0 x 80.0 x 24.9 mm

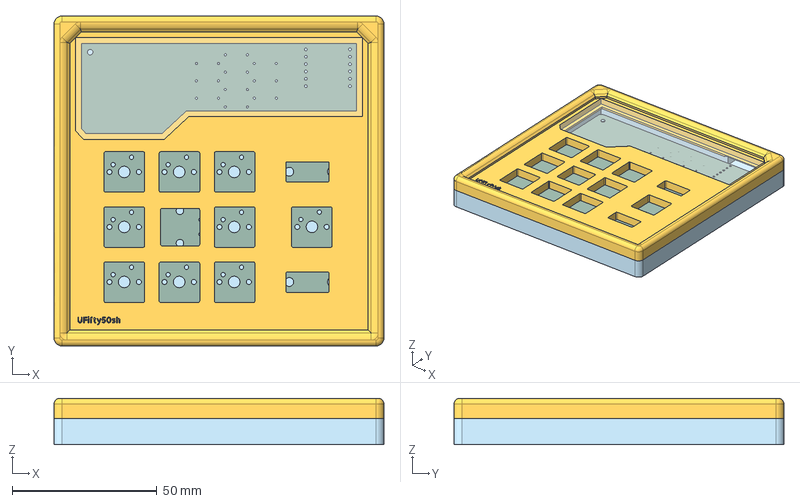
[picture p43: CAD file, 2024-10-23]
hackpads/hajpad/CAD/Whole_Model.step
114.0 x 114.0 x 16.0 mm

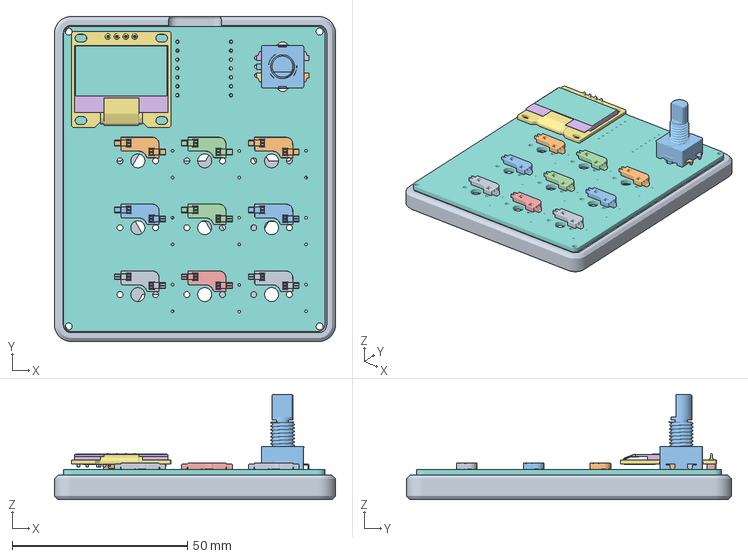
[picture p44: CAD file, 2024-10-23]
hackpads/haxpad/cad/assembled case (pcb in it).3mf
80.1 x 92.6 x 30.0 mm

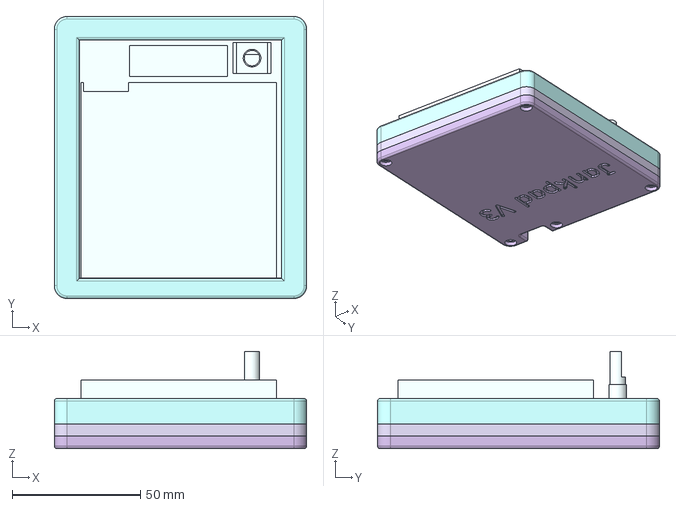
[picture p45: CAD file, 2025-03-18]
hackpads/jankpad/production/assembled.step
98.4 x 110.0 x 38.0 mm

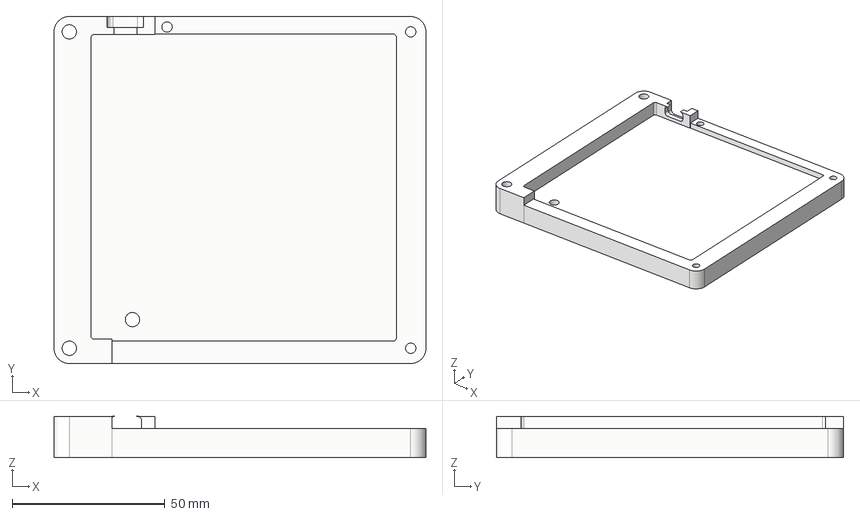
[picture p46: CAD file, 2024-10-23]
hackpads/JokaPad/Production/Case/MainBody.step
121.9 x 113.7 x 13.6 mm

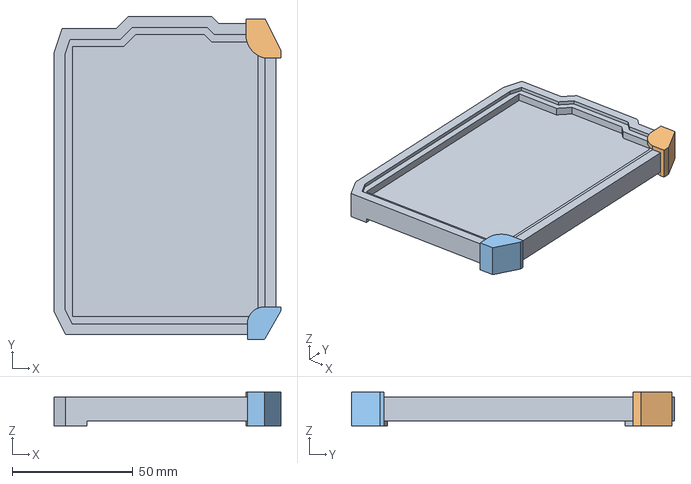
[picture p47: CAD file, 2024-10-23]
hackpads/maxpad/production/cad/maxpad_whole.step
94.0 x 134.0 x 14.0 mm

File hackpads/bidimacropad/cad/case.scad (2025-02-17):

pcb_size = [90.4875,80.9625,1.6];
tolerance =0.5;
case_thickness=5;
angle = 15;


module pcb(){
    
    cube(pcb_size);
}

module case(){
    difference() {
        union() {
            cube(
                pcb_size +
                [
                    case_thickness/2,
                    case_thickness,
                    case_thickness
                ]
            );

            case_feet();
        }
        
        translate([case_thickness/2,
                case_thickness/2-tolerance/2,
                case_thickness/2-tolerance/2]) 
        cube(pcb_size+[0,tolerance,tolerance]);

        translate([case_thickness,
                case_thickness,
                -500]) 
        cube(pcb_size-[case_thickness/2,case_thickness,0]+ [0,0,10000]);
    }

}

module case_feet() {
  /*
        /
       |\    /     /
       | \  /     /
       \  \/     /___
   |    \ |      
  a|     \|___________
          
          |--b-- ... ---|

  */

    top_piece_d = pcb_size.x  + case_thickness/2;

    top_piece_h = pcb_size.z + case_thickness;
    top_piece_w = pcb_size.y + case_thickness;

    a = cos(angle) * top_piece_h;
    b = cos(angle) * top_piece_d + sin(angle) * top_piece_h;
    
    difference() {
        translate([0,0,top_piece_h]) 
        rotate([0,90+angle,0]) 
        cube([a,top_piece_w,b]);
    }

}






rotate([0,-angle,0]){
    color(c = "green") 
   pcb();

translate([-case_thickness/2,-case_thickness/2,-case_thickness/2]) 
case();

}

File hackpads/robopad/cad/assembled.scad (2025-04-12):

use <case_bottom.scad>
use <case_top.scad>

translate([0, 0, 5]) case_top();
translate([0, 0, -1.5]) case_bottom();
color("green") import("./components/pcb.stl");

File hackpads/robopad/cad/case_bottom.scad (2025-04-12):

include <BOSL2/std.scad>

module case_bottom() {
    overlapBuffer = 0.1;
    difference() {
        cuboid([120, 120, 13], rounding=1, except=TOP);
        translate([0, 0, 3]) cube([101, 101, 10 + overlapBuffer], center=true);
        translate([55, -55, 0]) cylinder(r=1.7, h=13+overlapBuffer, center=true);
        translate([-55, -55, 0]) cylinder(r=1.7, h=13+overlapBuffer, center=true);
        translate([-55, 55, 0]) cylinder(r=1.7, h=13+overlapBuffer, center=true);
        translate([55, 55, 0]) cylinder(r=1.7, h=13+overlapBuffer, center=true);

        translate([0, 55, -1.5]) cuboid(size=[10, 10+overlapBuffer, 4], rounding=1, except=[FRONT, BACK]);
    }
}

translate([0, 0, -1.5]) case_bottom();
color("green") import("./components/pcb.stl");

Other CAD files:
hackpads/HackPad DK/CAD/Full/Hackpad Full.stp
hackpads/HackPad DK/Production/CAD/Full/Hackpad Full.stp
hackpads/Nano_Deck/CAD/seperate-3d-parts/Main body.3mf
hackpads/Nano_Deck/production/case/Main body.stl
hackpads/robopad/cad/case_top.scad
extras/knurled_knob.step
hackpads/0xBB/CAD/case_bottom.step
hackpads/0xBB/CAD/case_top.step
hackpads/0xBB/CAD/full case.step
hackpads/0xBB/CAD/plate-2024-10-05T20_56_19.932Z.dxf
hackpads/1-Up-Hackpad/production/Hackpad Bottom.step
hackpads/1-Up-Hackpad/production/Hackpad Top.step
hackpads/38key/cad/case.step
hackpads/38key/pcb/Vpad/Vpad.step
hackpads/38key/production/case/case.step
hackpads/3XAY_Hackpad/CAD/3MF/bottomCase.3mf
hackpads/3XAY_Hackpad/CAD/3MF/switchPlate.3mf
hackpads/3XAY_Hackpad/CAD/3MF/topPlate.3mf
hackpads/3XAY_Hackpad/Production/case/3D PRINTED Bottom Case.3mf
hackpads/3XAY_Hackpad/Production/case/3D PRINTED Top Plate.3mf
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

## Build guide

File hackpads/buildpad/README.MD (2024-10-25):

# Buildpad

This is my first time working on any hardware-ish stuff. This took me way longer than it should have because there are many versions that I scrapped (I didn't even push) and because I had to learn how to use KiCad and Fusion360. I initially planned on having two rotary encoders but I decided that IO expansion was a little too difficult to deal with especially to be within the size constraint and without SMD parts (since I am not comfortable soldering them). I also wanted to have Neopixels for the underglow but that never ended up happening because I designed a solution and later realized the need for resistors and decoupling capacitors which I tried adding, but I also later decided that I did not want to solder SMD components. My best solution to still get the RGB effect I wanted was to use these color changing LEDs in my BOM below.

# BOM:

- 16x Gateron Milky Yellow Switches (or any other switch)
- 16x Through-hole 1N4148 Diodes
- 16x Slow Fading RGB LEDs (234-RGB-Slow at https://www.aliexpress.com/item/1005005310058942.html) (3.0-3.4V, 20mA)
- 16x 15 Ohm Resistors (for the LEDs)
- 1x Bottom of the Case 3D Printed in Yellow Filament (if available or just the closest available color)
- 1x Top of the Case 3D Printed in Yellow Filament (if available or just the closest available color)
- 4x 3D Printed Screws in Black Filament (if available or just the closest available color)
- 16x Blank Red Keycaps (1u size)
- 1x 0.91 inch OLED Display (128x32) SSD1306
- 1x Xiao Seed RP2040
- 1x PCB

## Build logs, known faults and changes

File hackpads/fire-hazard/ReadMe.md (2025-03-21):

I was originally inspired to make this because I typically need to mute/deafen on calls a lot.

The hardest challenge I faced was attempting to CAD the case. I am very unfamiliar with CAD modeling.

BOM:
- 4x Cherry MX Switches
- 1x EC11 Encoder
- 6x SK6812 MINI Leds
- 1x 0.96in 128x32px OLED (SSD1306)
- 4x M3x20mm screws
- 1x Bottom case (3D Printed)
- 1x Top plate (3D Printed)
- 1x Seeed XIAO RP2040
- 4x Blank DSA Keycaps

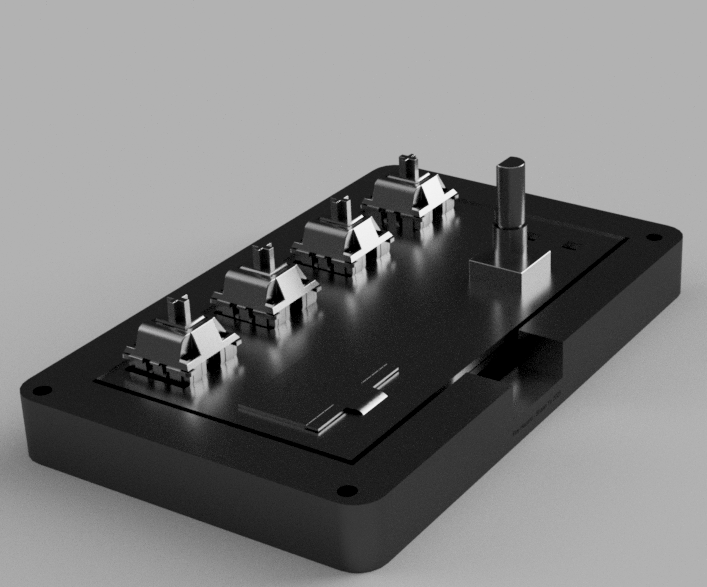
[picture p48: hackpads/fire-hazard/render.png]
Render


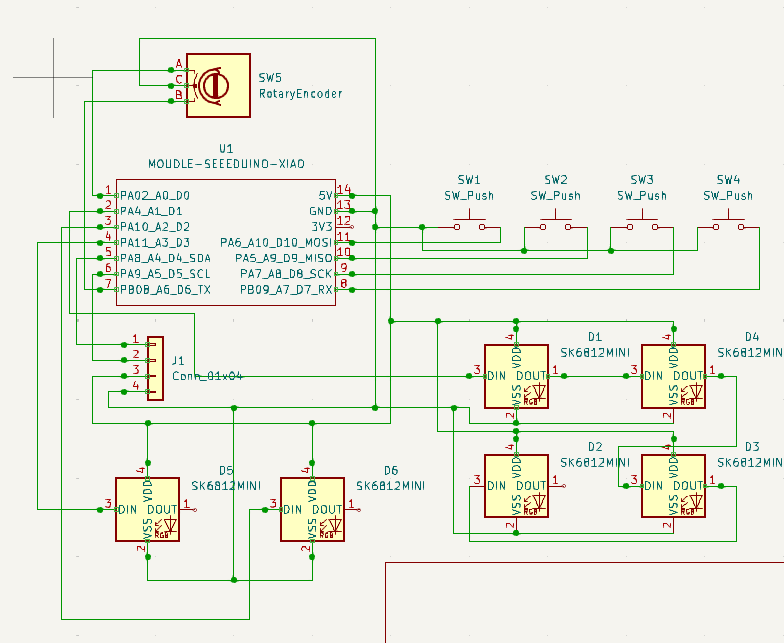
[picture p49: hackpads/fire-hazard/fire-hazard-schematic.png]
Schematic


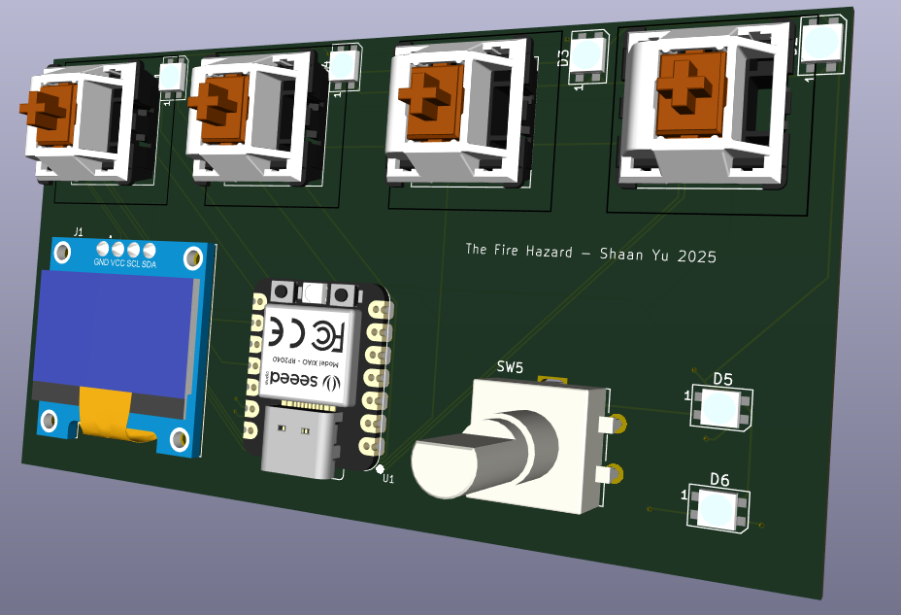
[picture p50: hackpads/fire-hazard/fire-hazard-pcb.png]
PCB


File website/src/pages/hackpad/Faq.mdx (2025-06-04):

# Frequently Asked Questions

Welcome to the FAQ section! If you have something you think should be added here please ping @dari in the #hackpad channel

**What's this Highway thing?** \
[Highway](https://highway.hackclub.com) is our current general hardware YSWS! Instead of being limited to just macropads, you can build any project you want! You can check out more about it [here](https://highway.hackclub.com/).

**What gets shipped to me?**
- An unsoldered Seeed XIAO RP2040 with headers
- A kit of all the parts in the approved parts list!
- a $15 HCB Card grant to get your **PCB** made
- a $18 HCB Card grant to get your soldering iron, if you need one. This is non-transferrable and fraud will result in a permanent ban from Hack Club.

{/* **What is the Card Grant?** \
[READ ME](/cardgrant) FOR INFO */}

**When is the deadline?** \
Same deadline as Highway! July 31st, but PLEASE don't hold it until then!

**Where can I find KiCAD footprints / what's the measurement for this thing / etc** \
A lot of these questions can be answered by checking out the [resources and tips section](/resources)! You can find **KiCAD footprints**, 3D models, etc

**Can I use a microcontroller other than the XIAO RP2040?** \
Sorry, no! If you want to use a different set of parts, you can make a custom project in [Highway](https://highway.hackclub.com), our current general hardware YSWS. You'll be given a $50 card grant instead to buy everything.

The XIAO is a great primer and I recommend using it, but it's totally understandable if you want to do something more advanced! We won't stop you :)

{/* **What's new with v2?** \
Lots of stuff! Updated list of requirements, more content, and other goodies - the big thing is that after making a macropad, you can design and submit an entire ***keyboard*** to be made! */}

{/* **Do *I* have to make a macropad before making a keyboard?** \
Absolutely! A keyboard is *significantly* harder to design, and so its a prerequisite you understand the fundamentals with a macropad first. You don't need to wait for it to come though! You can start your keyboard as soon as its approved */}

**Will my hackpad come assembled?** \
Unfortunately not! Not to fear though - assembling a 

**Can I use acrylic/cnc metal/etc for the case/plate?** \
NO!!! Only 3D prints are supported.

**Can I use parts outside of the approved list?** \
Yes! You are responsible for sourcing it on your own money though

**What colours are the keycaps?** \
White

**Can I use Choc switches?** \
No!

**What are the footprint name for through hole diodes?** \
The footprint for 1N4148 Diodes are D_DO-35_SOD27_P7.62mm_Horizontal. These are the diodes we are using

**Where will everything be shipped from?** \
It'll be shipped from HQ, which is located in Shelburne VT.

**I have more questions!!!**  \
Join the #hackpad channel in the Hack Club slack!

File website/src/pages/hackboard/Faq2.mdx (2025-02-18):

# Frequently asked questions, keyboard edition

Welcome to the FAQ of the keyboard section! This part is pretty emtpy for now - drop your questions in the slack and I'll answer them here

**Can I use a generator like Ergogen?** \
You're free to use it to experiment with layouts and make design decisions, but the actual placement of the footprints and schematic has to be done manually by you.

**Can I get PCBA?** \
NO!!!!

**Can I get a 4 layer PCB?** \
NO!!!!

**Can I use metal for my case?** \
NO!!!

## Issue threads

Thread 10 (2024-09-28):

Website Parts link is incorrect

PonderSlime, 2024-09-28:
Hi! the current link in the website redirects to here:
[https://github.com/hackclub/hackpad/APPROVED_PARTS.md](https://github.com/hackclub/hackpad/APPROVED_PARTS.md)

This is incorrect and doesn't exist.  This is the correct link:
[https://github.com/hackclub/hackpad/blob/main/APPROVED_PARTS.md](https://github.com/hackclub/hackpad/blob/main/APPROVED_PARTS.md)

PonderSlime, 2024-09-28:
@qcoral

Closed 2024-10-09.

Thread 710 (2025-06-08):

Multiple broken links & "Adding 3D models" section does not exist even though listed in table of contents

BananaJeanss, 2025-06-08:
There's multiple broken links in the [hackpad guide](https://hackpad.hackclub.com/guide) currently:

There's multiple broken links in this section as shown in the image, all leading to 404 pages

- https://hackpad.hackclub.com/advancedguide#silkscreen
- https://hackpad.hackclub.com/errors
- https://hackpad.hackclub.com/advancedPCB

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

---

The "Adding 3D models" section does not exist in the guide, though is still linked in the table of contents. Clicking on the link does nothing.

- https://hackpad.hackclub.com/guide#3d_models

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

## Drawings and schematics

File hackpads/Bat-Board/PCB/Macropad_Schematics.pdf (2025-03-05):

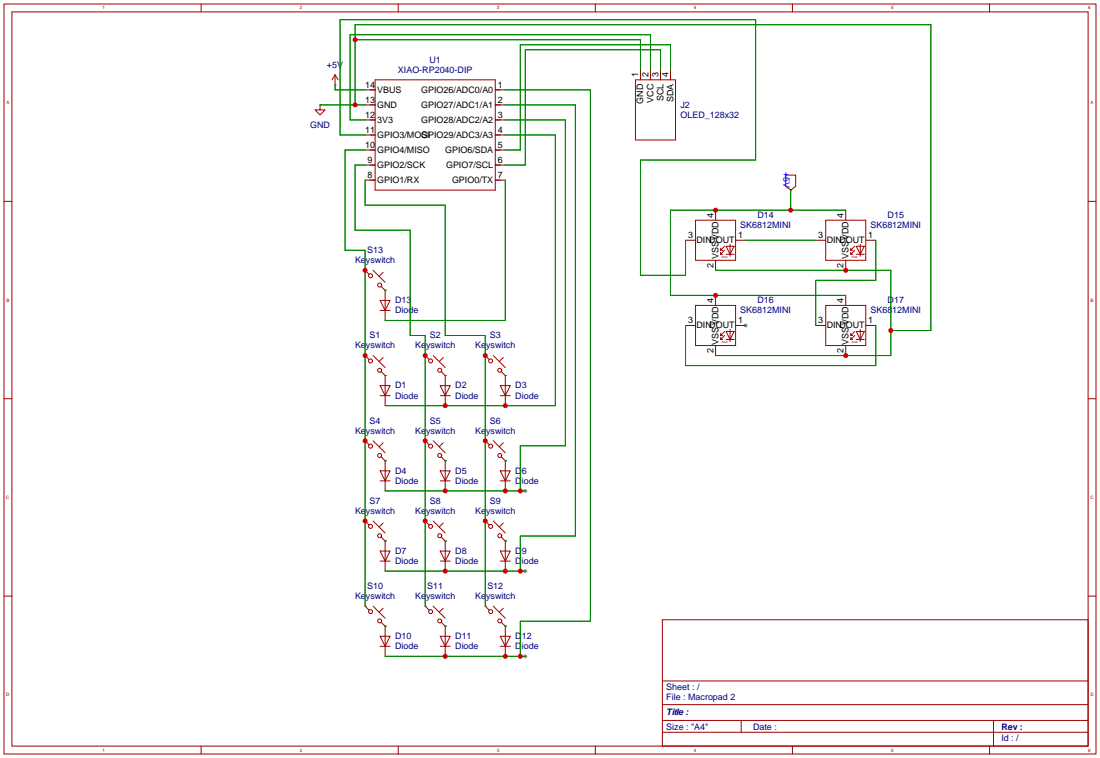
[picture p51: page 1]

GND 13 3V3 12 | 2

GPIO3/MOSI 11 | 4
GPIO4/MISO 10 | 5

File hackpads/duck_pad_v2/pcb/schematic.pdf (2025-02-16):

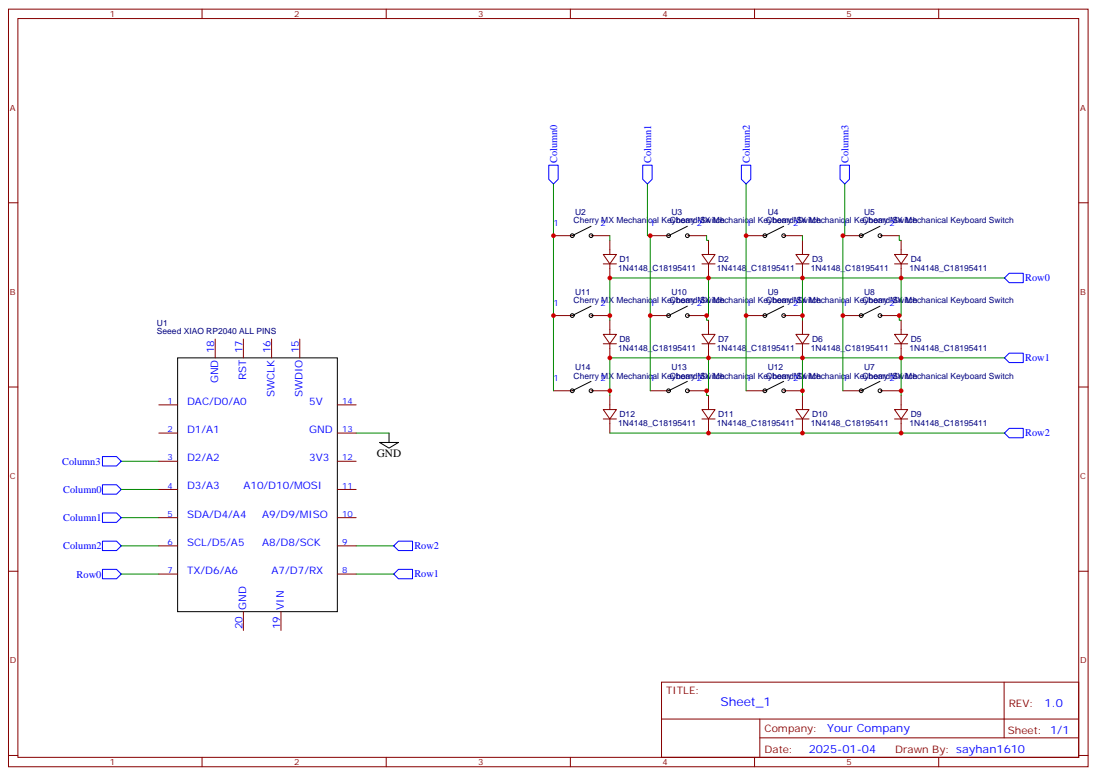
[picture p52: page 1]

Cherry MX Mechanical Keyboard Switch

Seeed XIAO RP2040 ALL PINS

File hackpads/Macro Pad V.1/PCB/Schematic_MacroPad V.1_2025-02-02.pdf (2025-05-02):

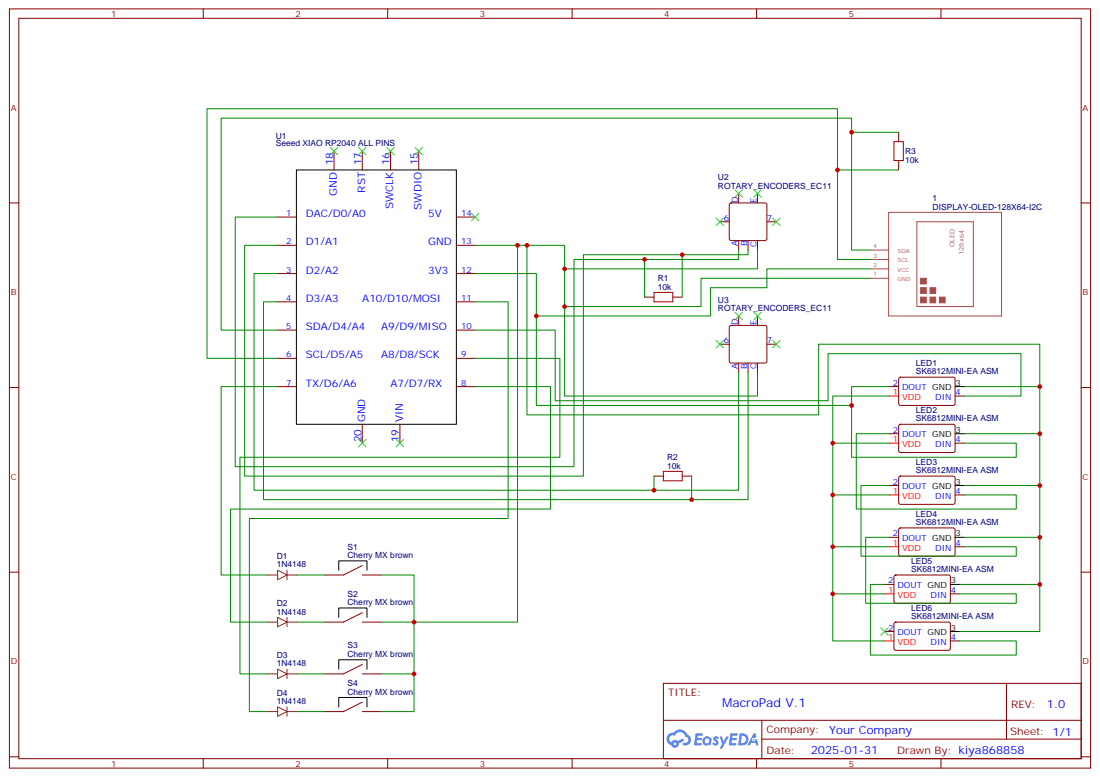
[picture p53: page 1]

Seeed XIAO RP2040 ALL PINS

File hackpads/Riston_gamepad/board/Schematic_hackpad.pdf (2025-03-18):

A | A
B | B
C | C
D | D

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
TITLE:
Sheet_1 | REV: 1.0
Date: | 2023-06-07

Sheet: 1/1

### Drawn By: maximusimperiousthe723rd

### Company: Your Company

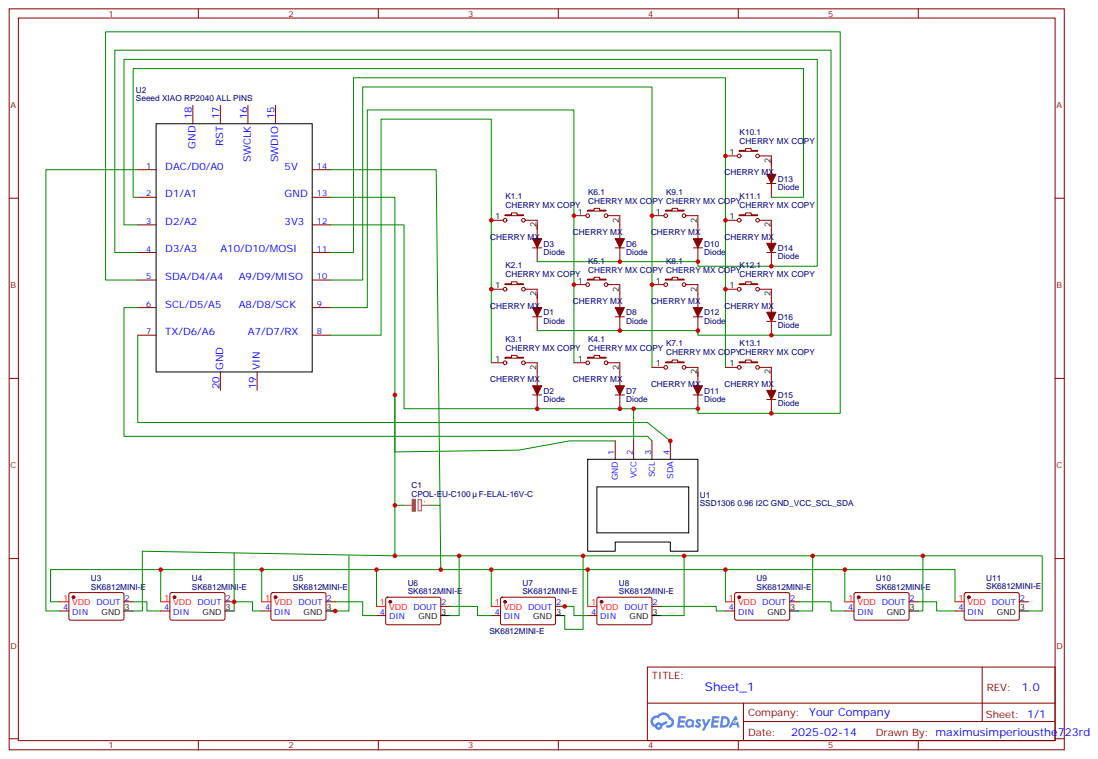
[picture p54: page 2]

Seeed XIAO RP2040 ALL PINS

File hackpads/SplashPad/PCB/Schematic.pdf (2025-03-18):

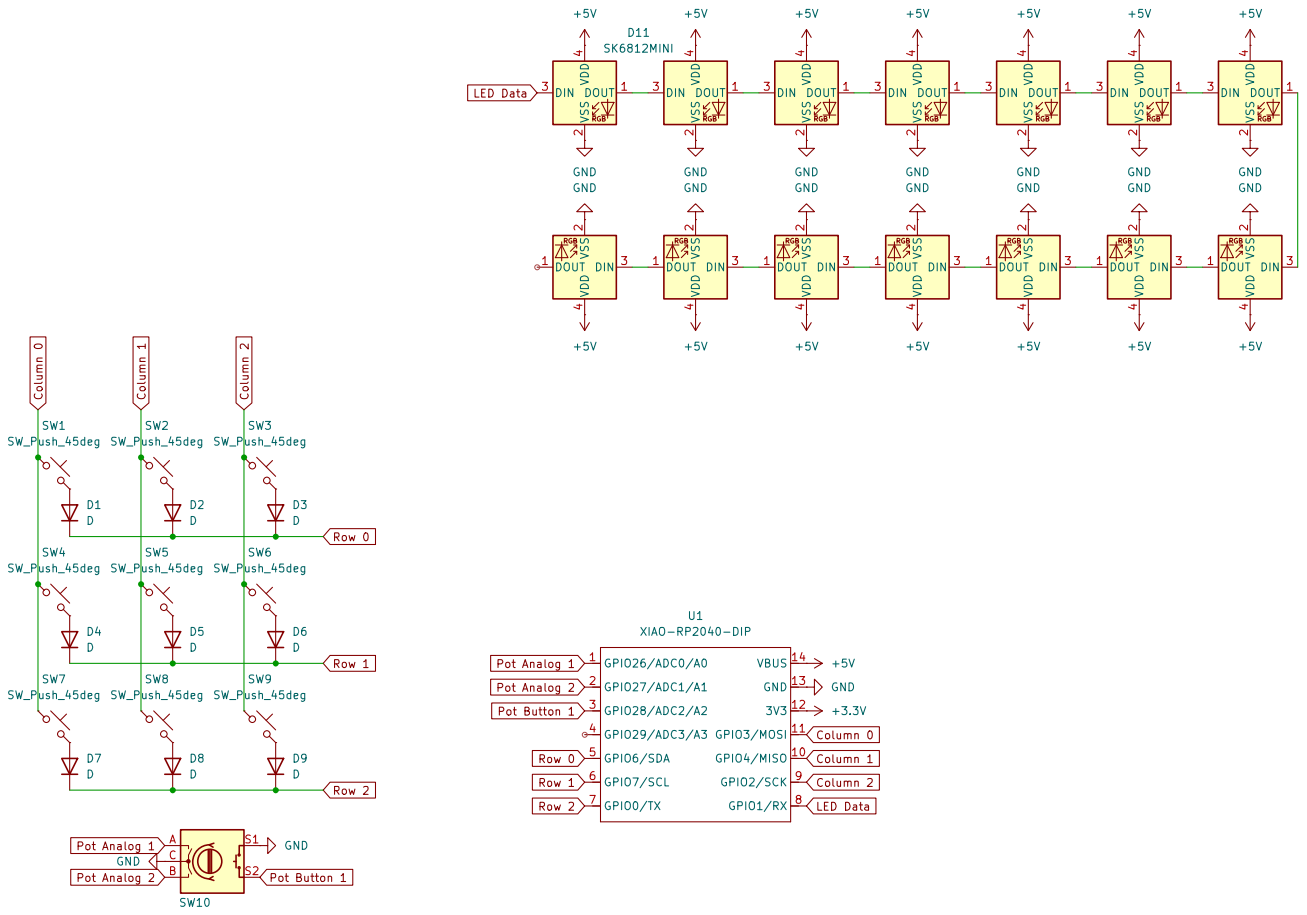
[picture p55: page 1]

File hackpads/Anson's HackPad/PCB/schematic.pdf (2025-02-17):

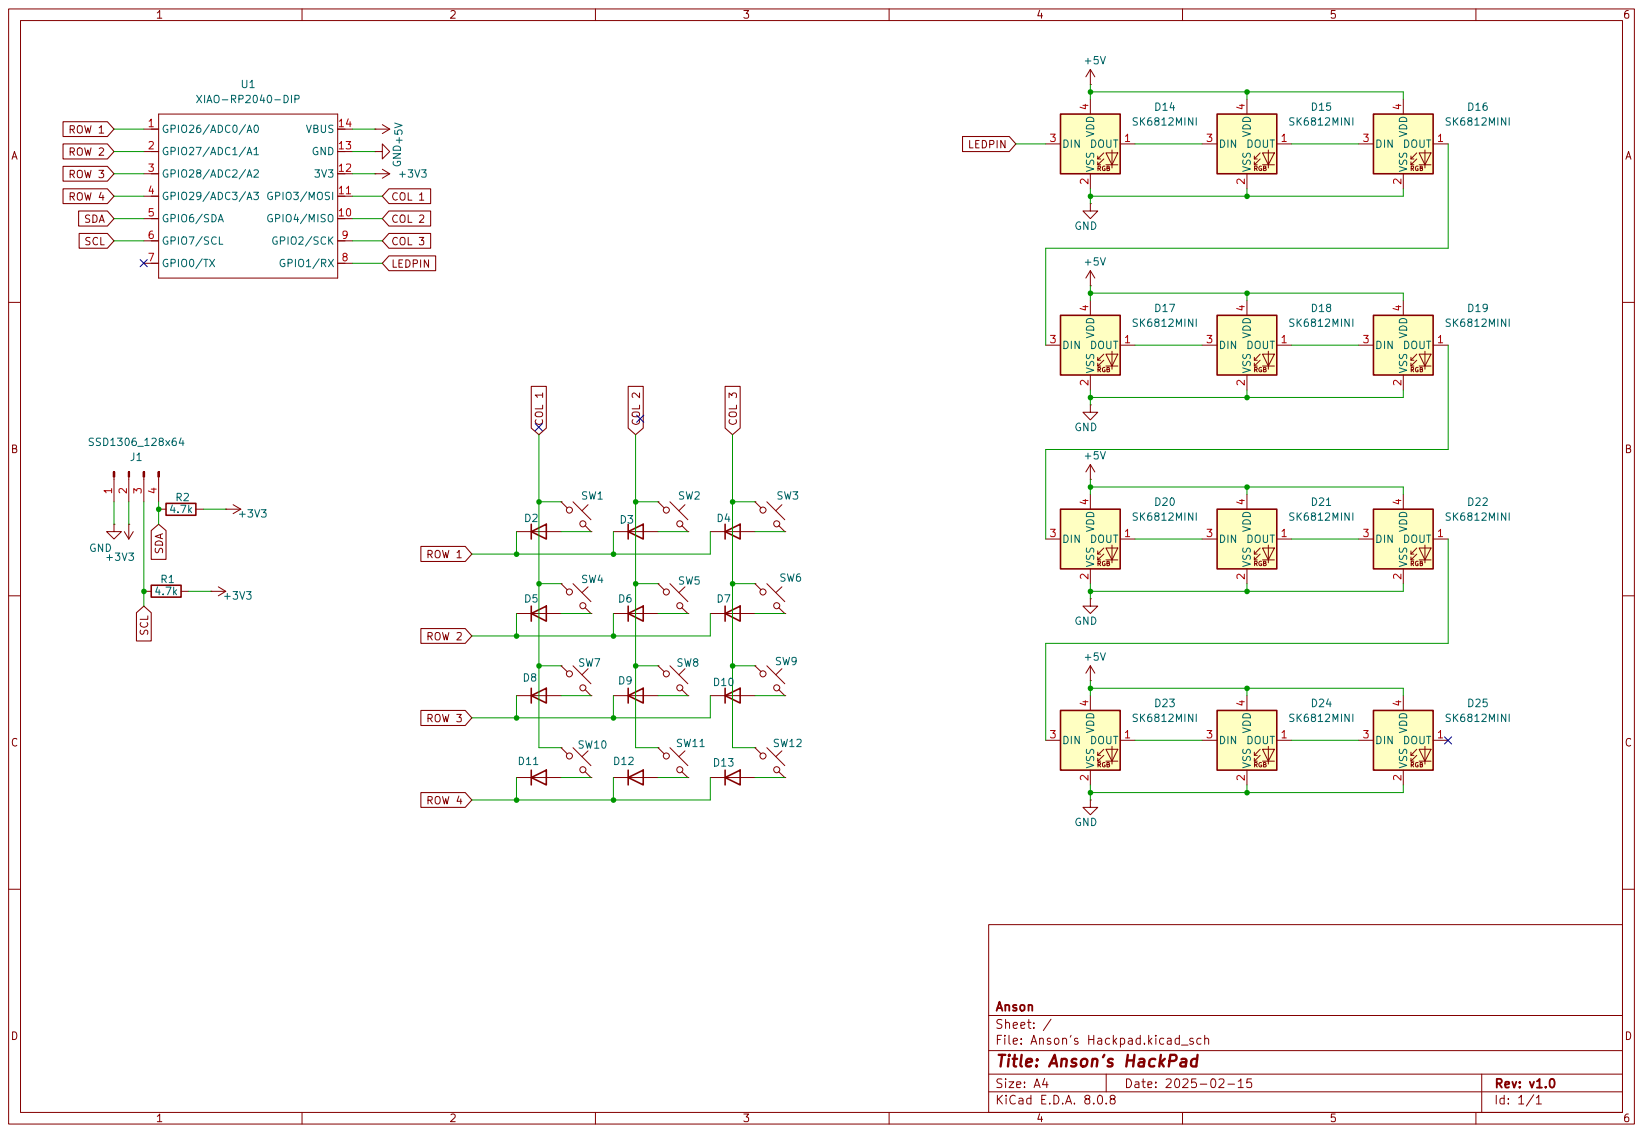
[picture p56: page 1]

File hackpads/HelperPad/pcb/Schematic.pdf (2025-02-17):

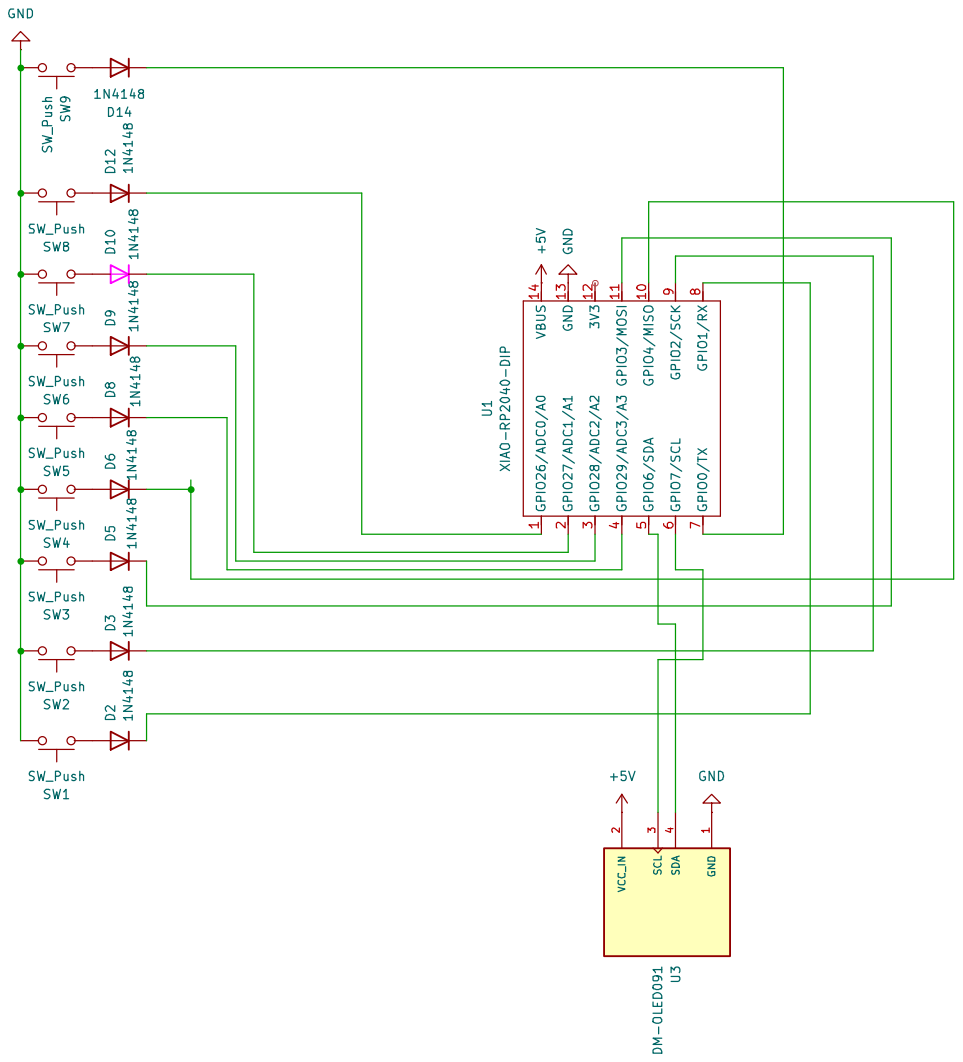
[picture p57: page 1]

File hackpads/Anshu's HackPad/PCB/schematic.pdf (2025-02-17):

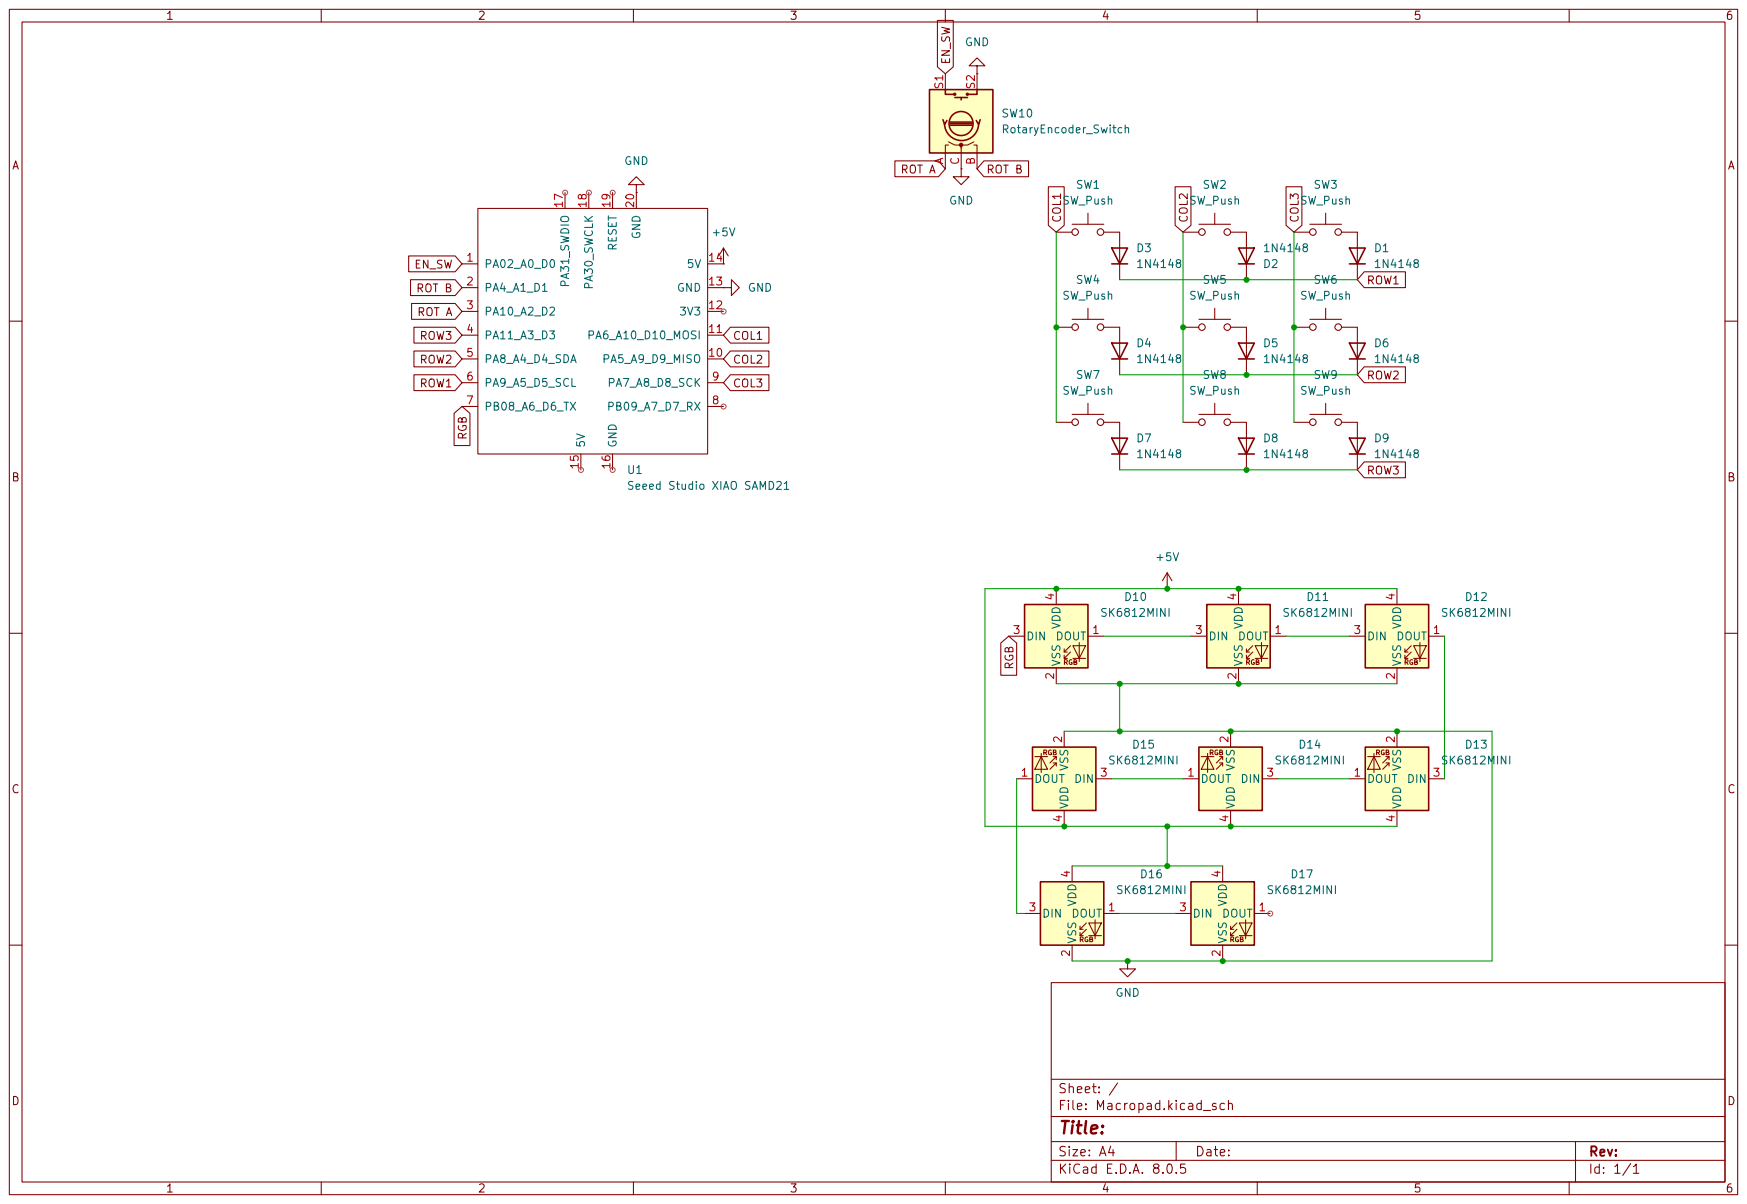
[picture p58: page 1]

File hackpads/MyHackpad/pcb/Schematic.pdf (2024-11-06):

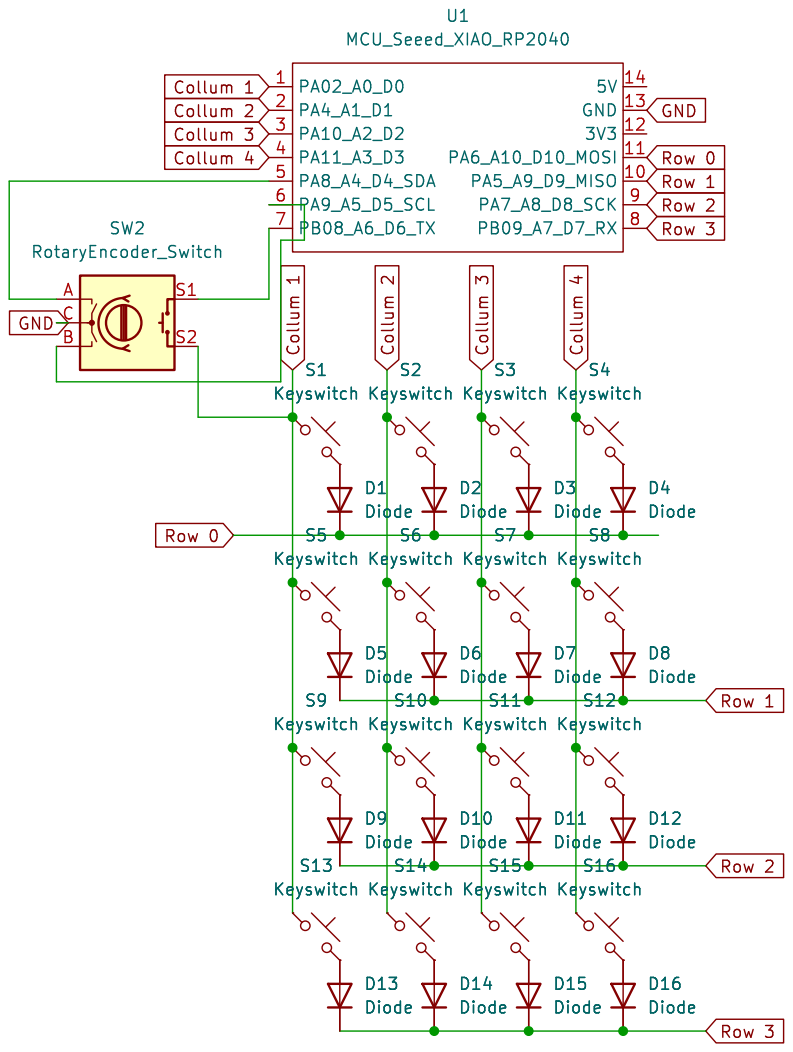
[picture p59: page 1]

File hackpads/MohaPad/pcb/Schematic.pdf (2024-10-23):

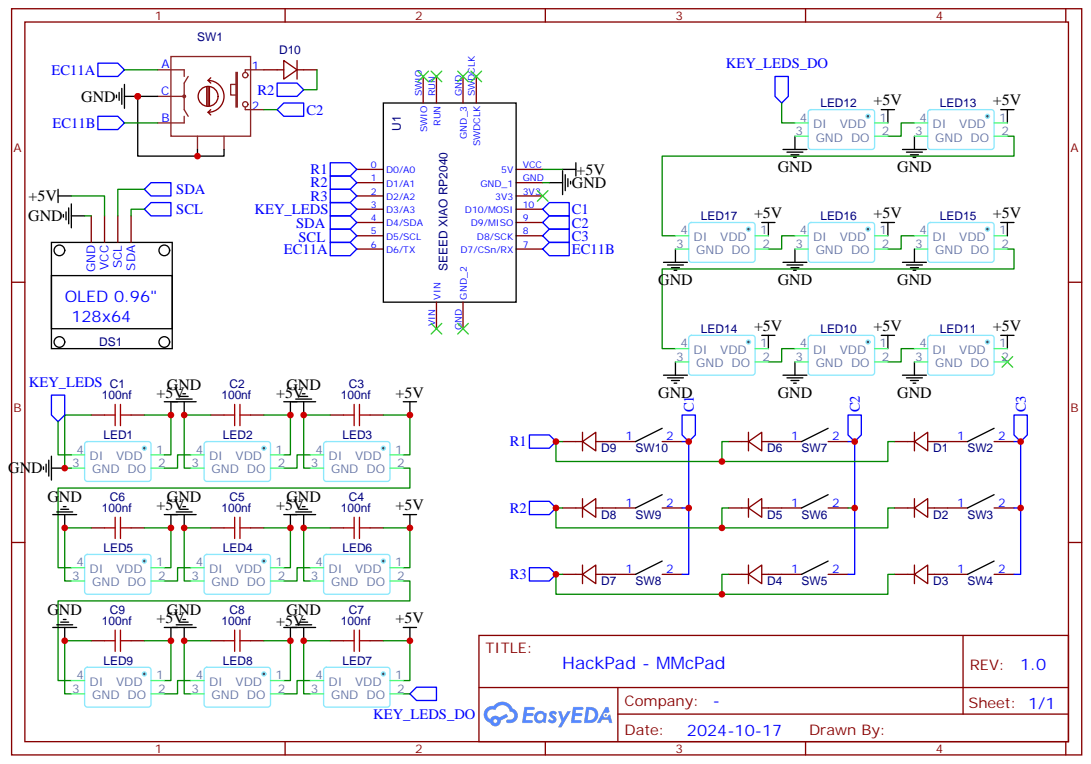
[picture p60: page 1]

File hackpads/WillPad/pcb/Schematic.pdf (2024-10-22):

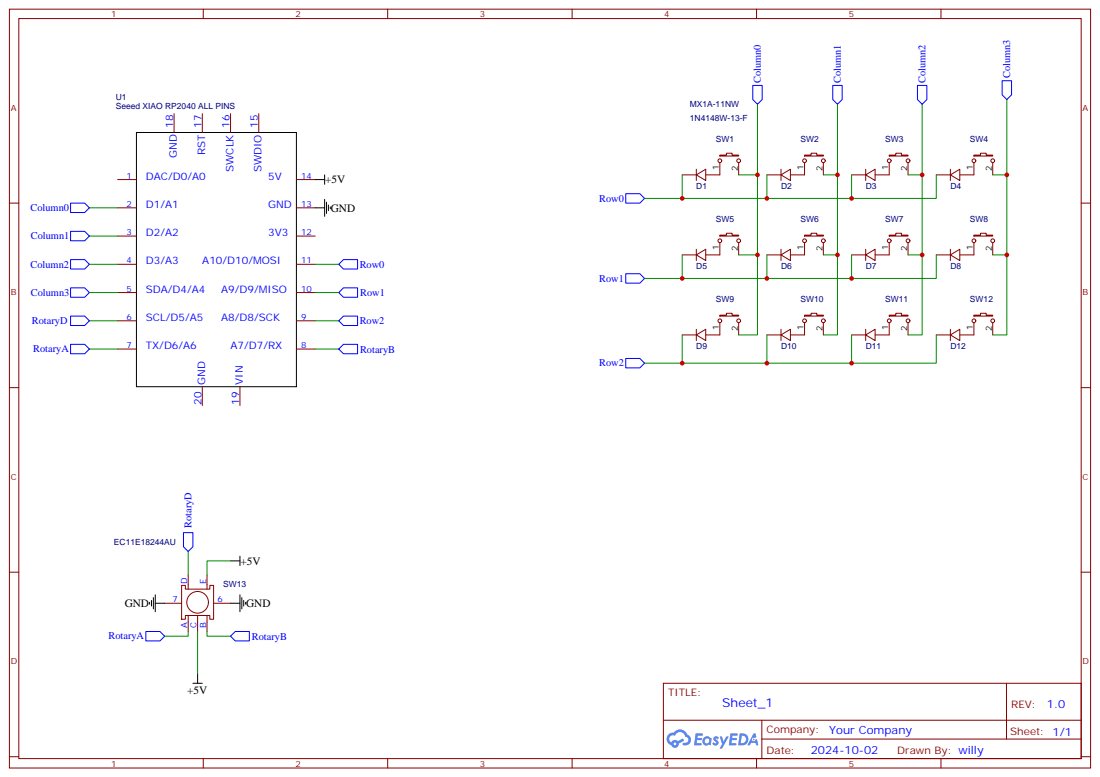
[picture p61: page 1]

Seeed XIAO RP2040 ALL PINS

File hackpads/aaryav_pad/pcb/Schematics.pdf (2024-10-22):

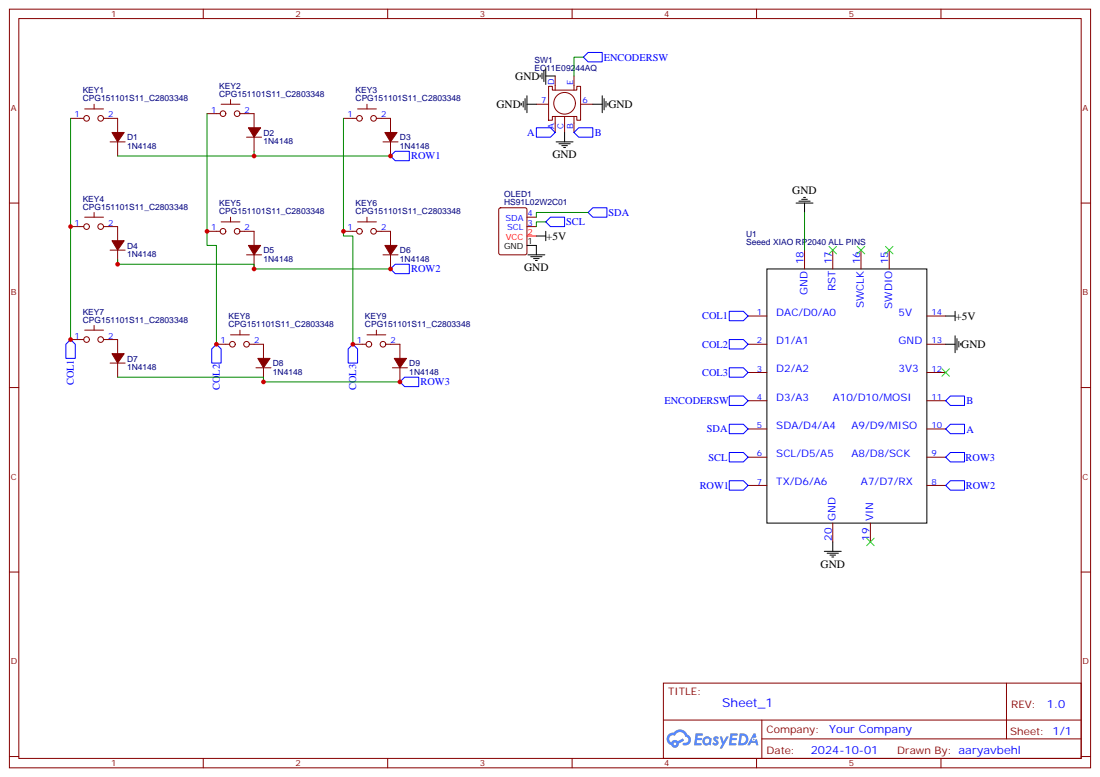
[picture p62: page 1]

Seeed XIAO RP2040 ALL PINS

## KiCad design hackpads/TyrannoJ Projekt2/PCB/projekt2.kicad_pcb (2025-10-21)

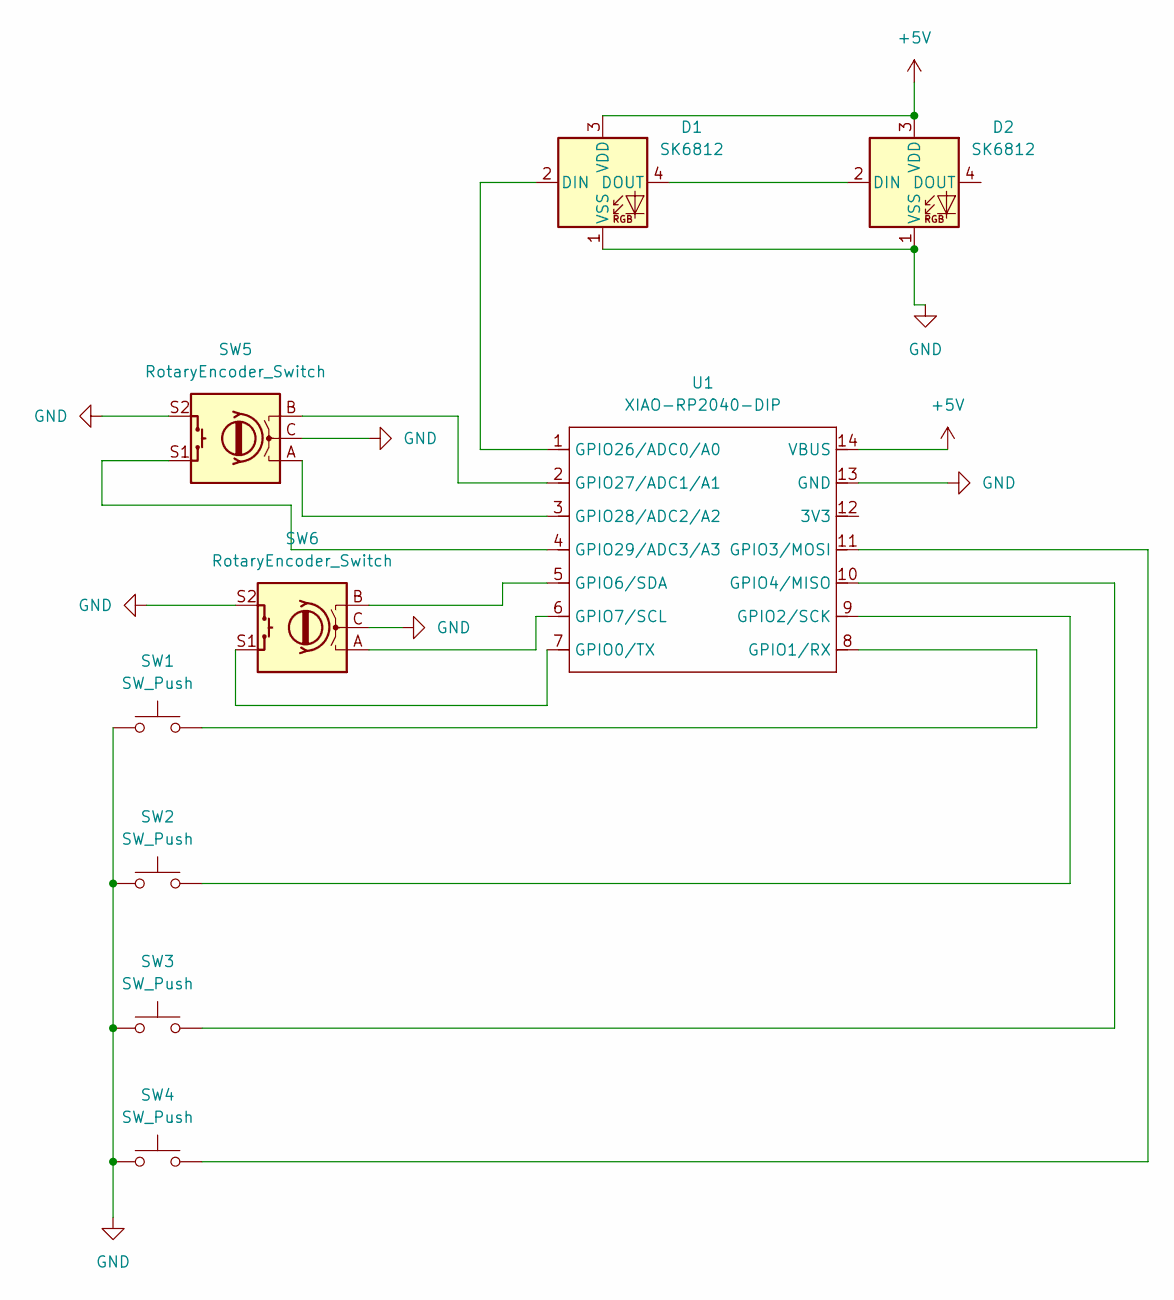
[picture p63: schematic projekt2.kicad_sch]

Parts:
D1, D2: SK6812; LED_SK6812MINI_PLCC4_3.5x3.5mm_P1.75mm
SW1, SW2, SW3, SW4: SW_Push; SW_Cherry_MX_1.00u_PCB
SW5, SW6: RotaryEncoder_Switch; RotaryEncoder_Alps_EC11E-Switch_Vertical_H20mm_CircularMoun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
U1: XIAO-RP2040-DIP

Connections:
+5V: D1.3 (VDD), D2.3 (VDD), U1.14 (VBUS)
GND: D1.1 (VSS), D2.1 (VSS), SW1.1, SW2.1, SW3.1, SW4.1, SW5.C, SW5.S2, SW6.C, SW6.S2, U1.13 (GND)
unnamed: D1.2 (DIN), U1.1 (GPIO26/ADC0/A0)
unnamed: D1.4 (DOUT), D2.2 (DIN)
unnamed: SW6.S1, U1.7 (GPIO0/TX)
unnamed: SW1.2, U1.8 (GPIO1/RX)
unnamed: SW2.2, U1.9 (GPIO2/SCK)
unnamed: SW4.2, U1.11 (GPIO3/MOSI)
unnamed: SW3.2, U1.10 (GPIO4/MISO)
unnamed: SW6.B, U1.5 (GPIO6/SDA)
unnamed: SW6.A, U1.6 (GPIO7/SCL)
unnamed: SW5.B, U1.2 (GPIO27/ADC1/A1)
unnamed: SW5.A, U1.3 (GPIO28/ADC2/A2)
unnamed: SW5.S1, U1.4 (GPIO29/ADC3/A3)

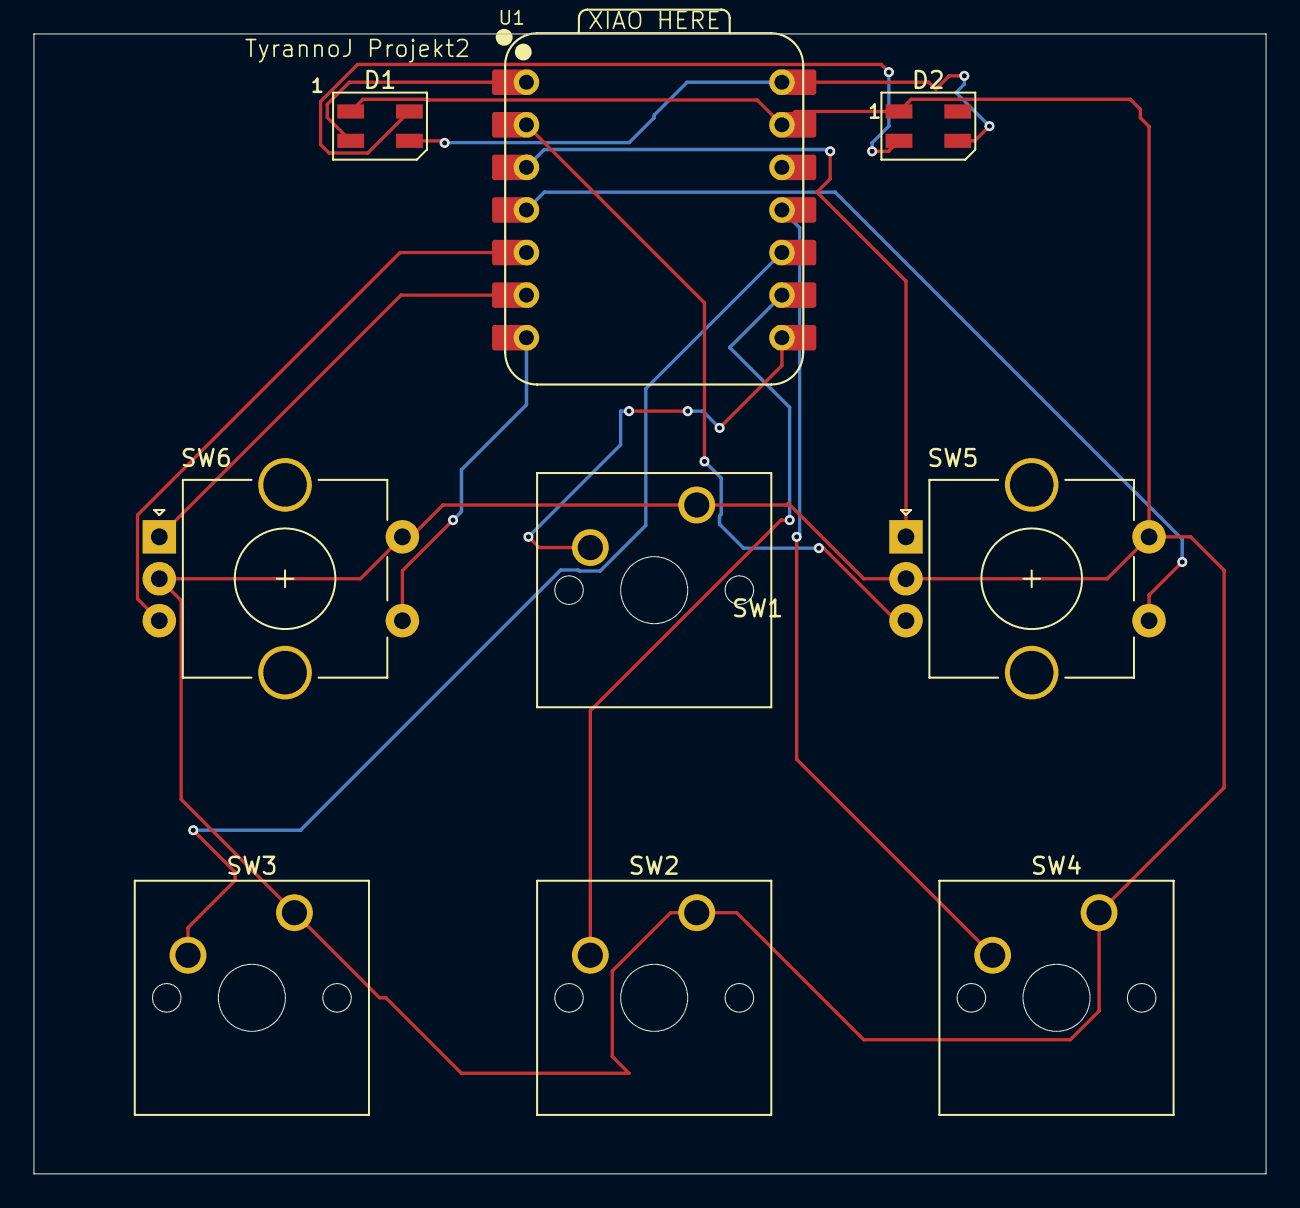
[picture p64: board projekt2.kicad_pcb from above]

Board: 2 copper layers, 73.5 x 68.0 mm, 9 parts (0 on the bottom side), 14 nets.

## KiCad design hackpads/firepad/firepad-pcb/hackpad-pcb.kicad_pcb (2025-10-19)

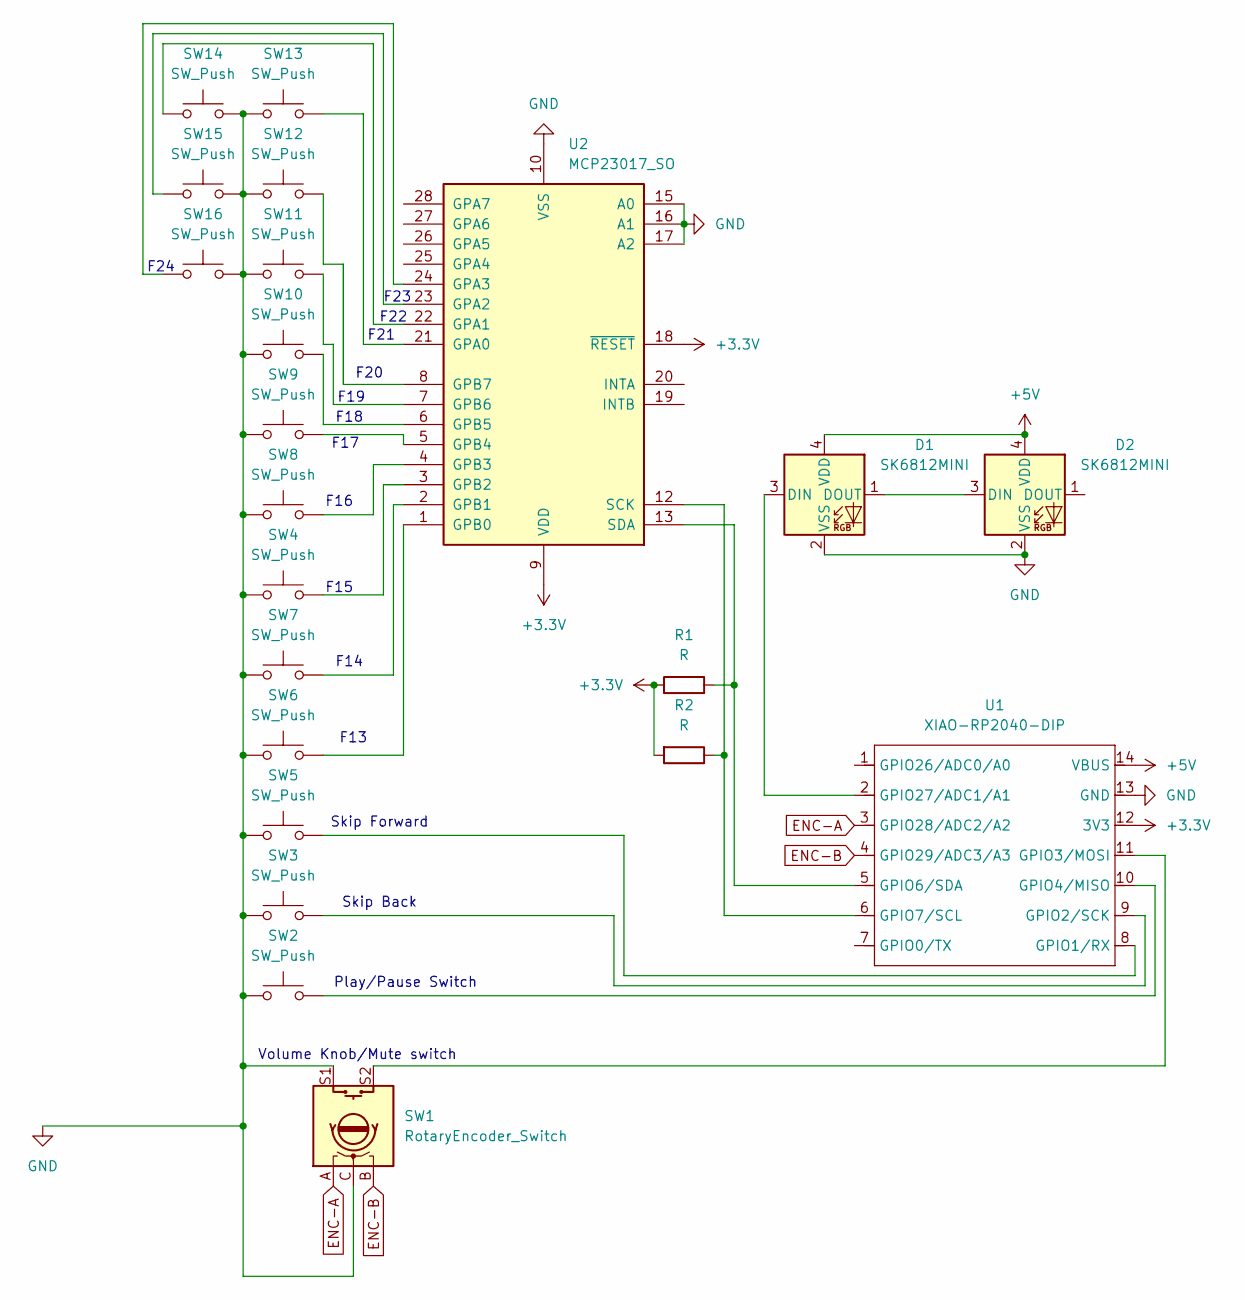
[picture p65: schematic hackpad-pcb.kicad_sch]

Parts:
D1, D2: SK6812MINI; LED_SK6812MINI_PLCC4_3.5x3.5mm_P1.75mm_3D
R1, R2: R; R_Axial_DIN0204_L3.6mm_D1.6mm_P7.62mm_Horizontal
SW1: RotaryEncoder_Switch; RotaryEncoder_Alps_EC11E-Switch_Vertical_H20mm_CircularMoun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
SW2, SW3, SW4, SW5, SW6, SW7, SW8, SW9, SW10, SW11, SW12, SW13, SW14, SW15, SW16: SW_Push; SW_Cherry_MX_1.00u_PCB_3D
U1: XIAO-RP2040-DIP; XIAO-RP2040-DIP-3D
U2: MCP23017_SO; SOIC-28W_7.5x17.9mm_P1.27mm

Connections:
+3.3V: R1.1, R2.2, U1.12 (3V3), U2.9 (VDD), U2.18 (~RESET)
+5V: D1.4 (VDD), D2.4 (VDD), U1.14 (VBUS)
ENC-A: SW1.A, U1.3 (GPIO28/ADC2/A2)
ENC-B: SW1.B, U1.4 (GPIO29/ADC3/A3)
GND: D1.2 (VSS), D2.2 (VSS), SW1.C, SW1.S1, SW2.1, SW3.1, SW4.1, SW5.1, SW6.1, SW7.1, SW8.1, SW9.1, SW10.1, SW11.1, SW12.1, SW13.1, SW14.2, SW15.2, SW16.2, U1.13 (GND), U2.10 (VSS), U2.15 (A0), U2.16 (A1), U2.17 (A2)
unnamed: D1.3 (DIN), U1.2 (GPIO27/ADC1/A1)
unnamed: D1.1 (DOUT), D2.3 (DIN)
unnamed: SW5.2, U1.8 (GPIO1/RX)
unnamed: SW3.2, U1.9 (GPIO2/SCK)
unnamed: SW1.S2, U1.11 (GPIO3/MOSI)
unnamed: SW2.2, U1.10 (GPIO4/MISO)
unnamed: R1.2, U1.5 (GPIO6/SDA), U2.13 (SDA)
unnamed: R2.1, U1.6 (GPIO7/SCL), U2.12 (SCK)
unnamed: SW13.2, U2.21 (GPA0)
unnamed: SW14.1, U2.22 (GPA1)
unnamed: SW15.1, U2.23 (GPA2)
unnamed: SW16.1, U2.24 (GPA3)
unnamed: SW6.2, U2.1 (GPB0)
unnamed: SW7.2, U2.2 (GPB1)
unnamed: SW4.2, U2.3 (GPB2)
unnamed: SW8.2, U2.4 (GPB3)
unnamed: SW9.2, U2.5 (GPB4)
unnamed: SW10.2, U2.6 (GPB5)
unnamed: SW11.2, U2.7 (GPB6)
unnamed: SW12.2, U2.8 (GPB7)

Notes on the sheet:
F15
F21
F14
Skip Forward
F13
F19
Volume Knob/Mute switch
F23
F24
F22
F17
F16
Play/Pause Switch
F18
Skip Back
F20

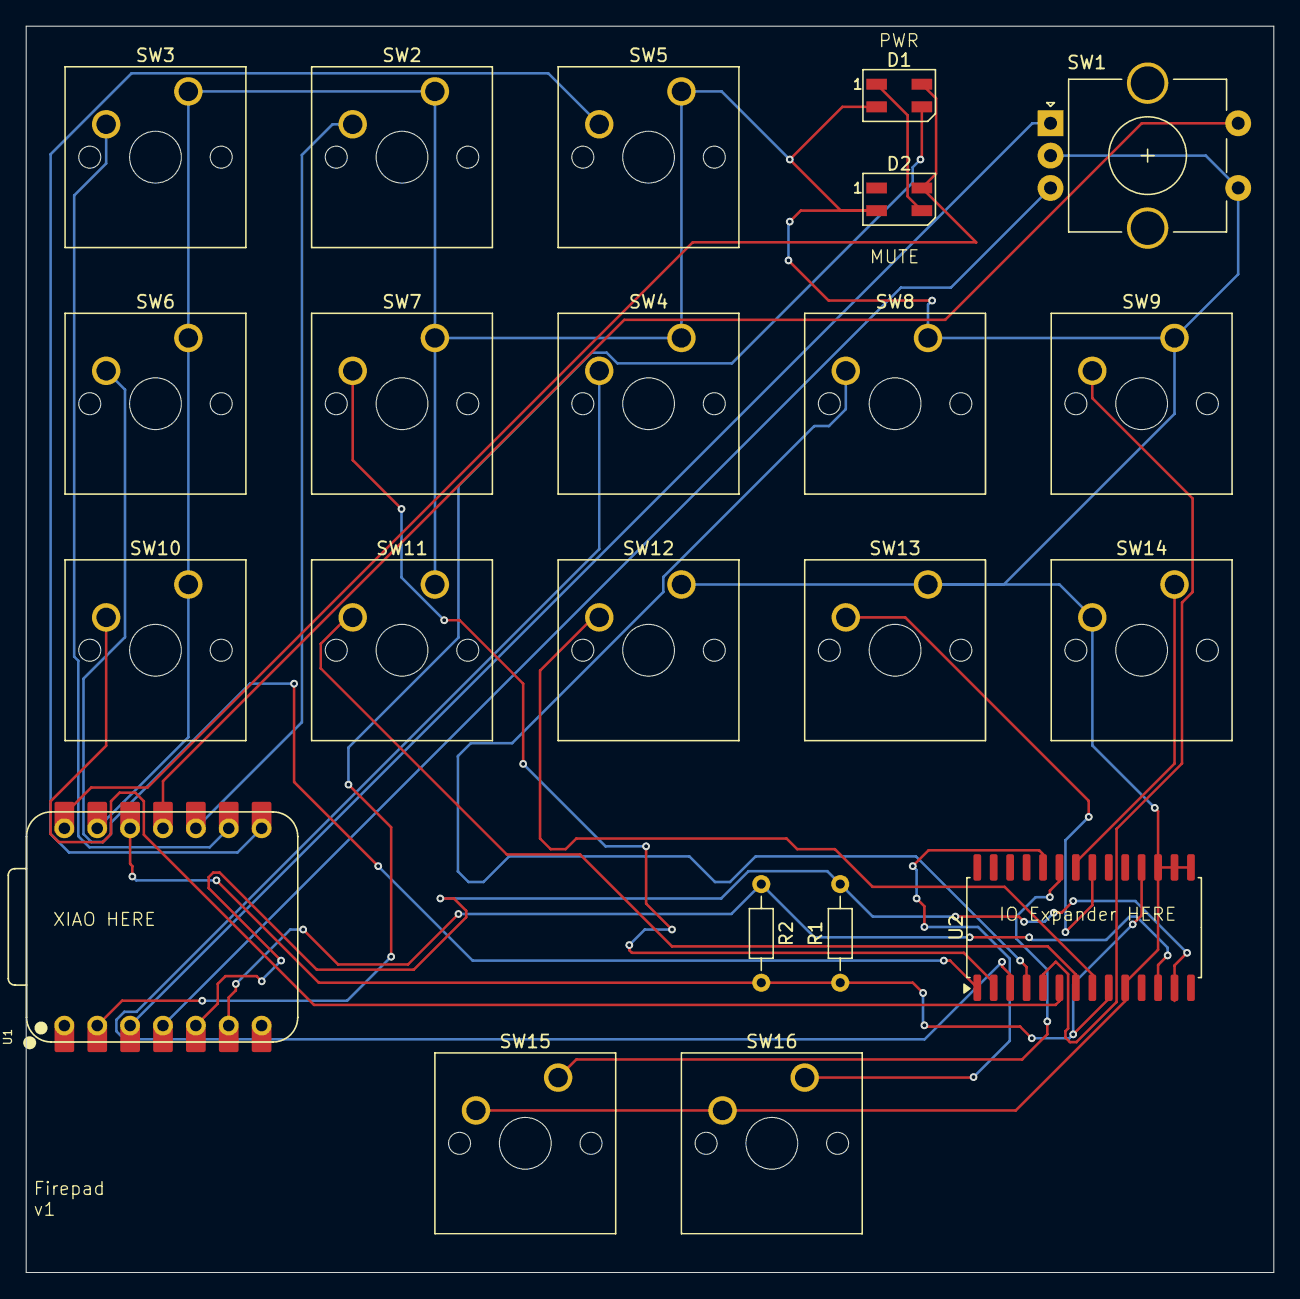
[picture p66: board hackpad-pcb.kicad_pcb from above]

Board: 2 copper layers, 96.4 x 96.3 mm, 22 parts (0 on the bottom side), 25 nets.

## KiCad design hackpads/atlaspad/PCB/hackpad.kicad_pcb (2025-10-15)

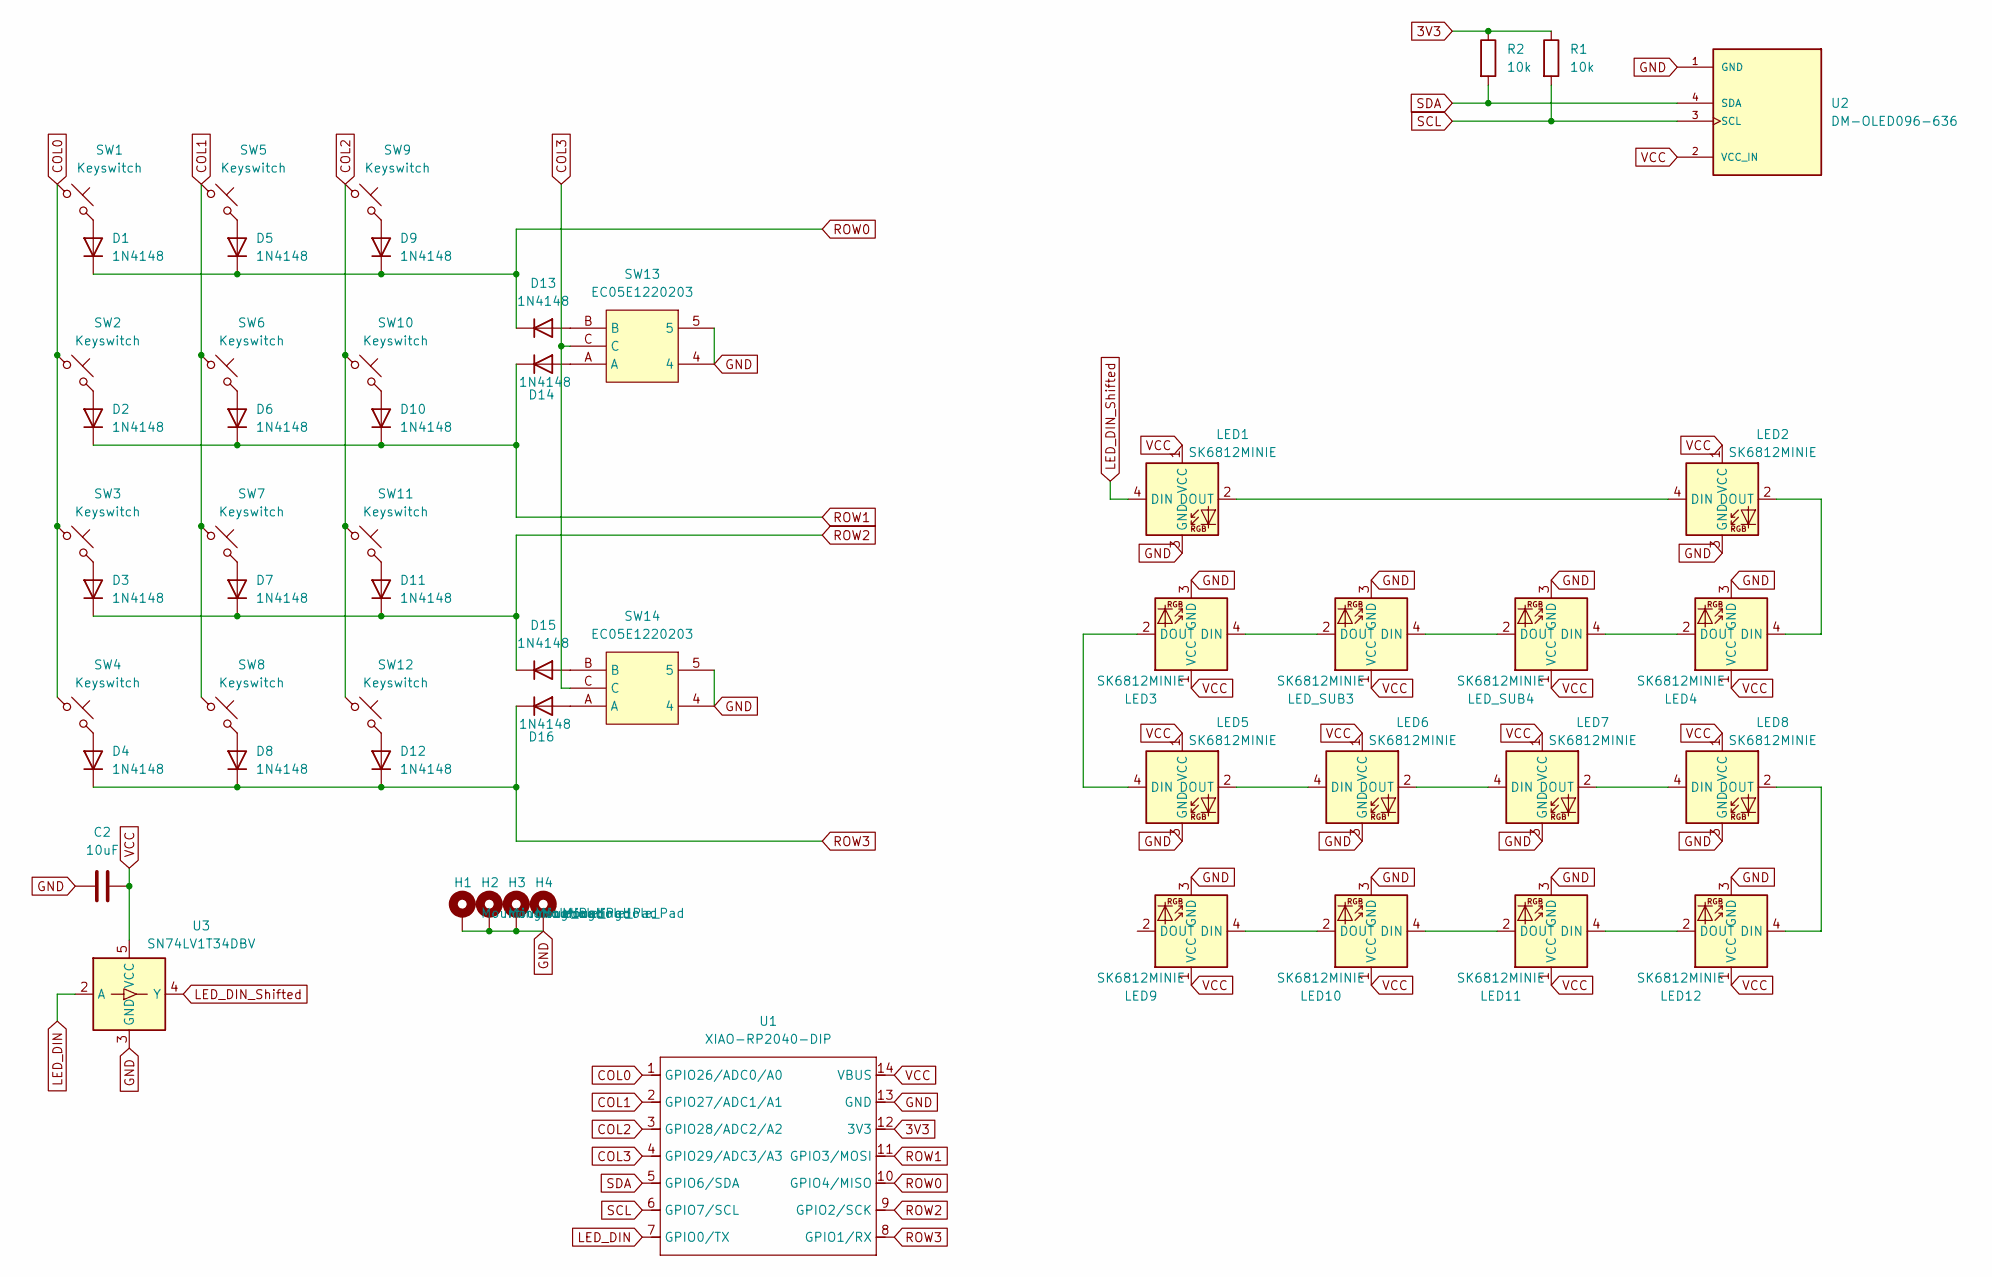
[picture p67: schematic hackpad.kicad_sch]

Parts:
C2: 10uF; C_Radial_D5.0mm_H7.0mm_P2.00mm
D1, D2, D3, D4, D5, D6, D7, D8, D9, D10, D11, D12, D13, D14, D15, D16: 1N4148; D_DO-35_SOD27_P7.62mm_Horizontal
H1, H2, H3, H4: MountingHole_Pad; MountingHole_2.2mm_M2_DIN965_Pad
LED1, LED2, LED3, LED4, LED5, LED6, LED7, LED8, LED9, LED10, LED11, LED12: SK6812MINIE; SK6812MINI-E-Reverse
LED_SUB3, LED_SUB4: SK6812MINIE; SK6812MINI-E-Reverse
R1, R2: 10k; R_0402_1005Metric_Pad0.72x0.64mm_HandSolder
SW1, SW2, SW3, SW4, SW5, SW6, SW7, SW8, SW9, SW10, SW11, SW12: Keyswitch; Kailh-PG1353-Solderable-1U
SW13, SW14: EC05E1220203; SW-SMD_EC05E1220203; LCSC Part C390930
U1: XIAO-RP2040-DIP
U2: DM-OLED096-636; MODULE_DM-OLED096-636; PARTREV 2018-09-10
U3: SN74LV1T34DBV; SOT-23-5

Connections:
3V3: R1.1, R2.1, U1.12 (3V3)
COL0: SW1.1, SW2.1, SW3.1, SW4.1, U1.1 (GPIO26/ADC0/A0)
COL1: SW5.1, SW6.1, SW7.1, SW8.1, U1.2 (GPIO27/ADC1/A1)
COL2: SW9.1, SW10.1, SW11.1, SW12.1, U1.3 (GPIO28/ADC2/A2)
COL3: SW13.C, SW14.C, U1.4 (GPIO29/ADC3/A3)
GND: C2.1, H1.1, H2.1, H3.1, H4.1, LED1.3 (GND), LED2.3 (GND), LED3.3 (GND), LED4.3 (GND), LED5.3 (GND), LED6.3 (GND), LED7.3 (GND), LED8.3 (GND), LED9.3 (GND), LED10.3 (GND), LED11.3 (GND), LED12.3 (GND), LED_SUB3.3 (GND), LED_SUB4.3 (GND), SW13.4, SW13.5, SW14.4, SW14.5, U1.13 (GND), U2.1 (GND), U3.3 (GND)
LED_DIN: U1.7 (GPIO0/TX), U3.2 (A)
LED_DIN_Shifted: LED1.4 (DIN), U3.4 (Y)
unnamed: D1.2 (A), SW1.2
unnamed: D2.2 (A), SW2.2
unnamed: D3.2 (A), SW3.2
unnamed: D4.2 (A), SW4.2
unnamed: D5.2 (A), SW5.2
unnamed: D6.2 (A), SW6.2
unnamed: D7.2 (A), SW7.2
unnamed: D8.2 (A), SW8.2
unnamed: D9.2 (A), SW9.2
unnamed: D10.2 (A), SW10.2
unnamed: D11.2 (A), SW11.2
unnamed: D12.2 (A), SW12.2
unnamed: D13.2 (A), SW13.B
unnamed: D14.2 (A), SW13.A
unnamed: D15.2 (A), SW14.B
unnamed: D16.2 (A), SW14.A
unnamed: LED1.2 (DOUT), LED2.4 (DIN)
unnamed: LED2.2 (DOUT), LED4.4 (DIN)
unnamed: LED3.4 (DIN), LED_SUB3.2 (DOUT)
unnamed: LED3.2 (DOUT), LED5.4 (DIN)
unnamed: LED4.2 (DOUT), LED_SUB4.4 (DIN)
unnamed: LED5.2 (DOUT), LED6.4 (DIN)
unnamed: LED6.2 (DOUT), LED7.4 (DIN)
unnamed: LED7.2 (DOUT), LED8.4 (DIN)
unnamed: LED10.4 (DIN), LED11.2 (DOUT)
unnamed: LED9.4 (DIN), LED10.2 (DOUT)
unnamed: LED11.4 (DIN), LED12.2 (DOUT)
unnamed: LED8.2 (DOUT), LED12.4 (DIN)
unnamed: LED_SUB3.4 (DIN), LED_SUB4.2 (DOUT)
ROW0: D1.1 (K), D5.1 (K), D9.1 (K), D13.1 (K), U1.10 (GPIO4/MISO)
ROW1: D2.1 (K), D6.1 (K), D10.1 (K), D14.1 (K), U1.11 (GPIO3/MOSI)
ROW2: D3.1 (K), D7.1 (K), D11.1 (K), D15.1 (K), U1.9 (GPIO2/SCK)
ROW3: D4.1 (K), D8.1 (K), D12.1 (K), D16.1 (K), U1.8 (GPIO1/RX)
SCL: R1.2, U1.6 (GPIO7/SCL), U2.3 (SCL)
SDA: R2.2, U1.5 (GPIO6/SDA), U2.4 (SDA)
VCC: C2.2, LED1.1 (VCC), LED2.1 (VCC), LED3.1 (VCC), LED4.1 (VCC), LED5.1 (VCC), LED6.1 (VCC), LED7.1 (VCC), LED8.1 (VCC), LED9.1 (VCC), LED10.1 (VCC), LED11.1 (VCC), LED12.1 (VCC), LED_SUB3.1 (VCC), LED_SUB4.1 (VCC), U1.14 (VBUS), U2.2 (VCC_IN), U3.5 (VCC)

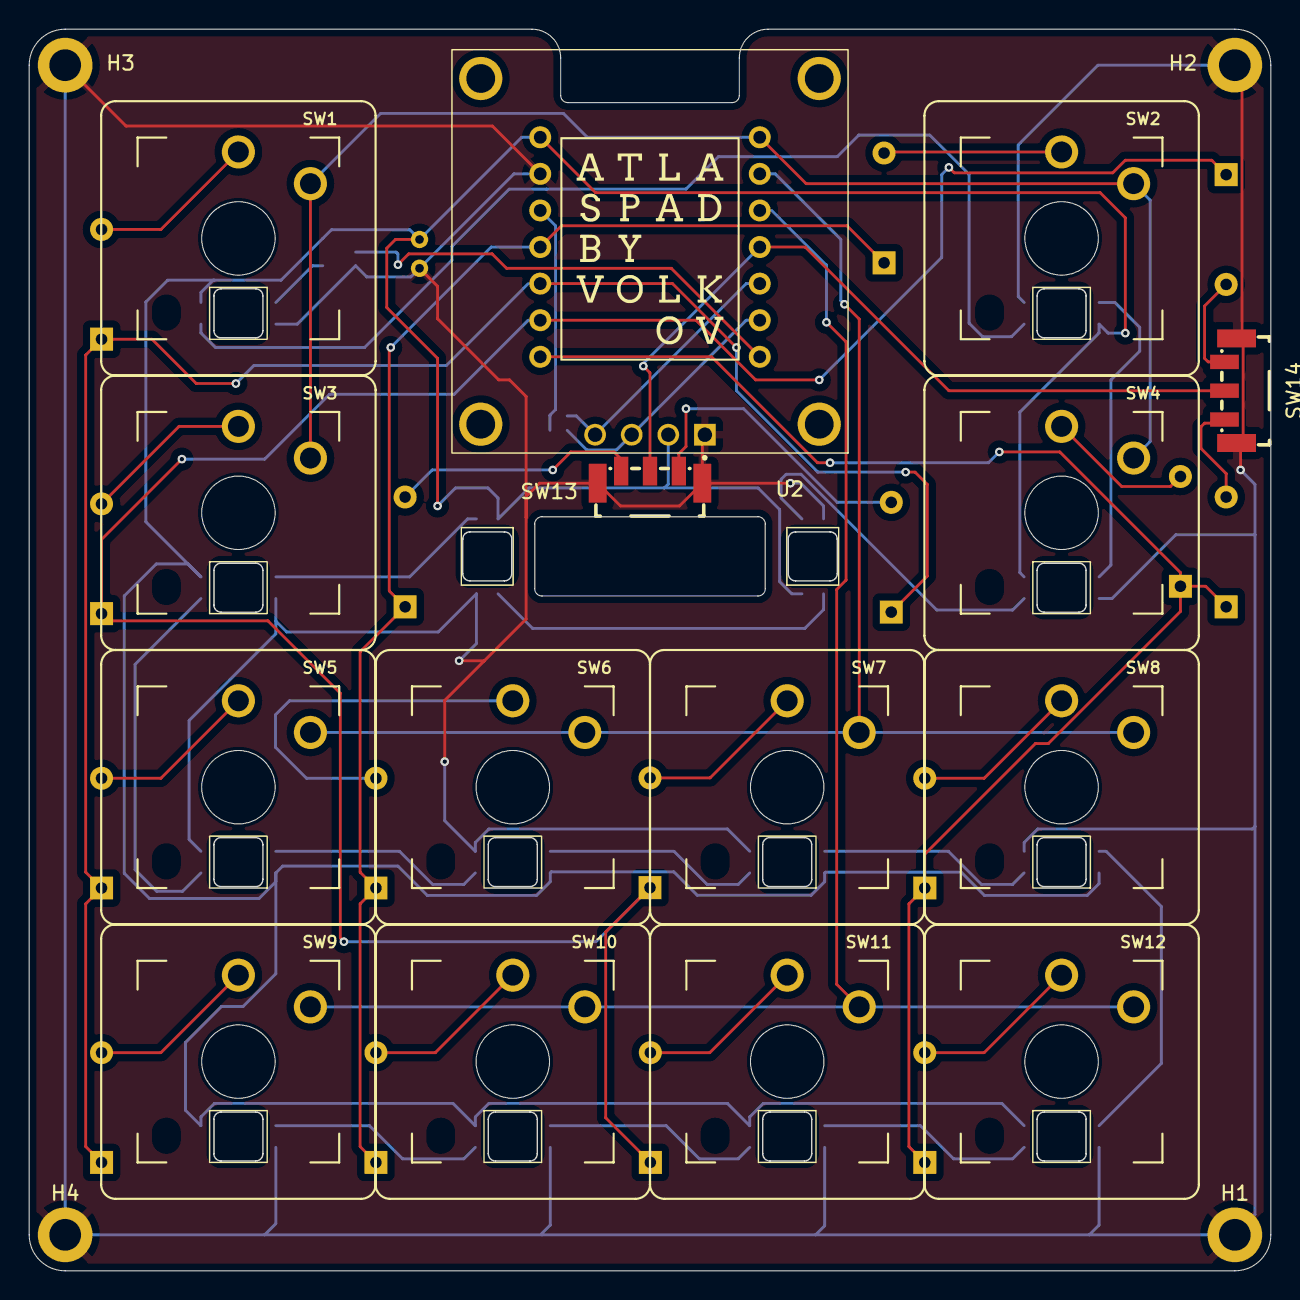
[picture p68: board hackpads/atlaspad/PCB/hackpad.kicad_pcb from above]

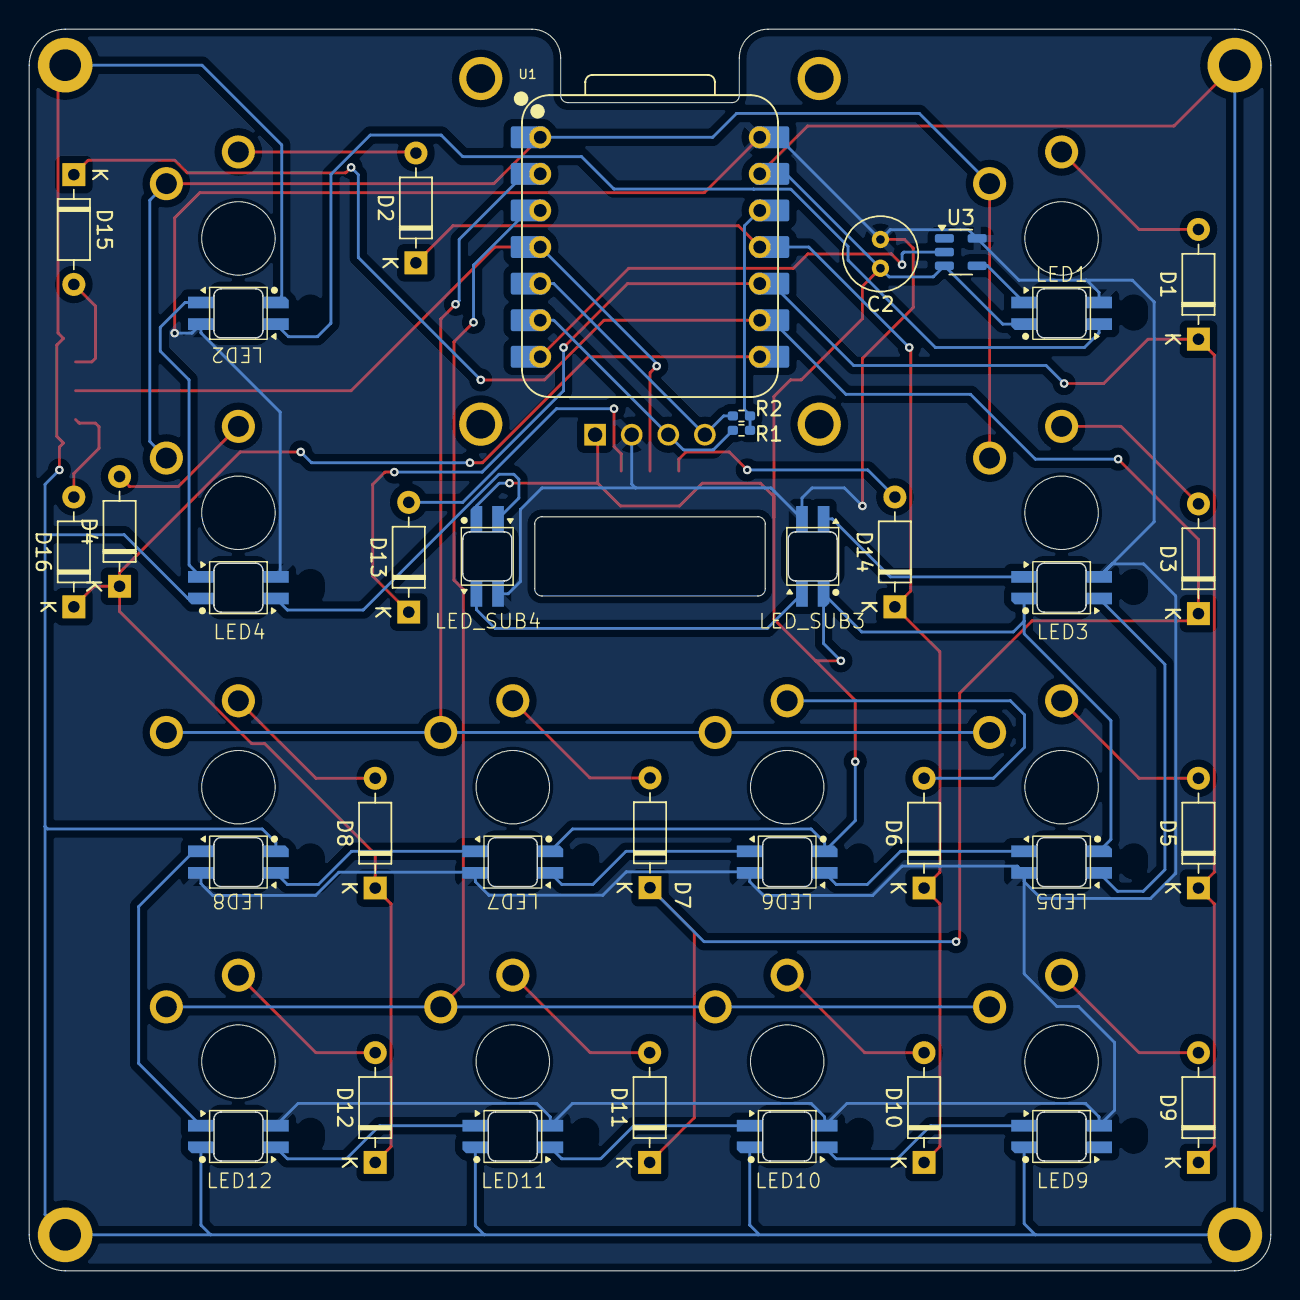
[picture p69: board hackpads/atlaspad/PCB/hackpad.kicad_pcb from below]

Board: 2 copper layers, 86.2 x 86.2 mm, 54 parts (21 on the bottom side), 44 nets.

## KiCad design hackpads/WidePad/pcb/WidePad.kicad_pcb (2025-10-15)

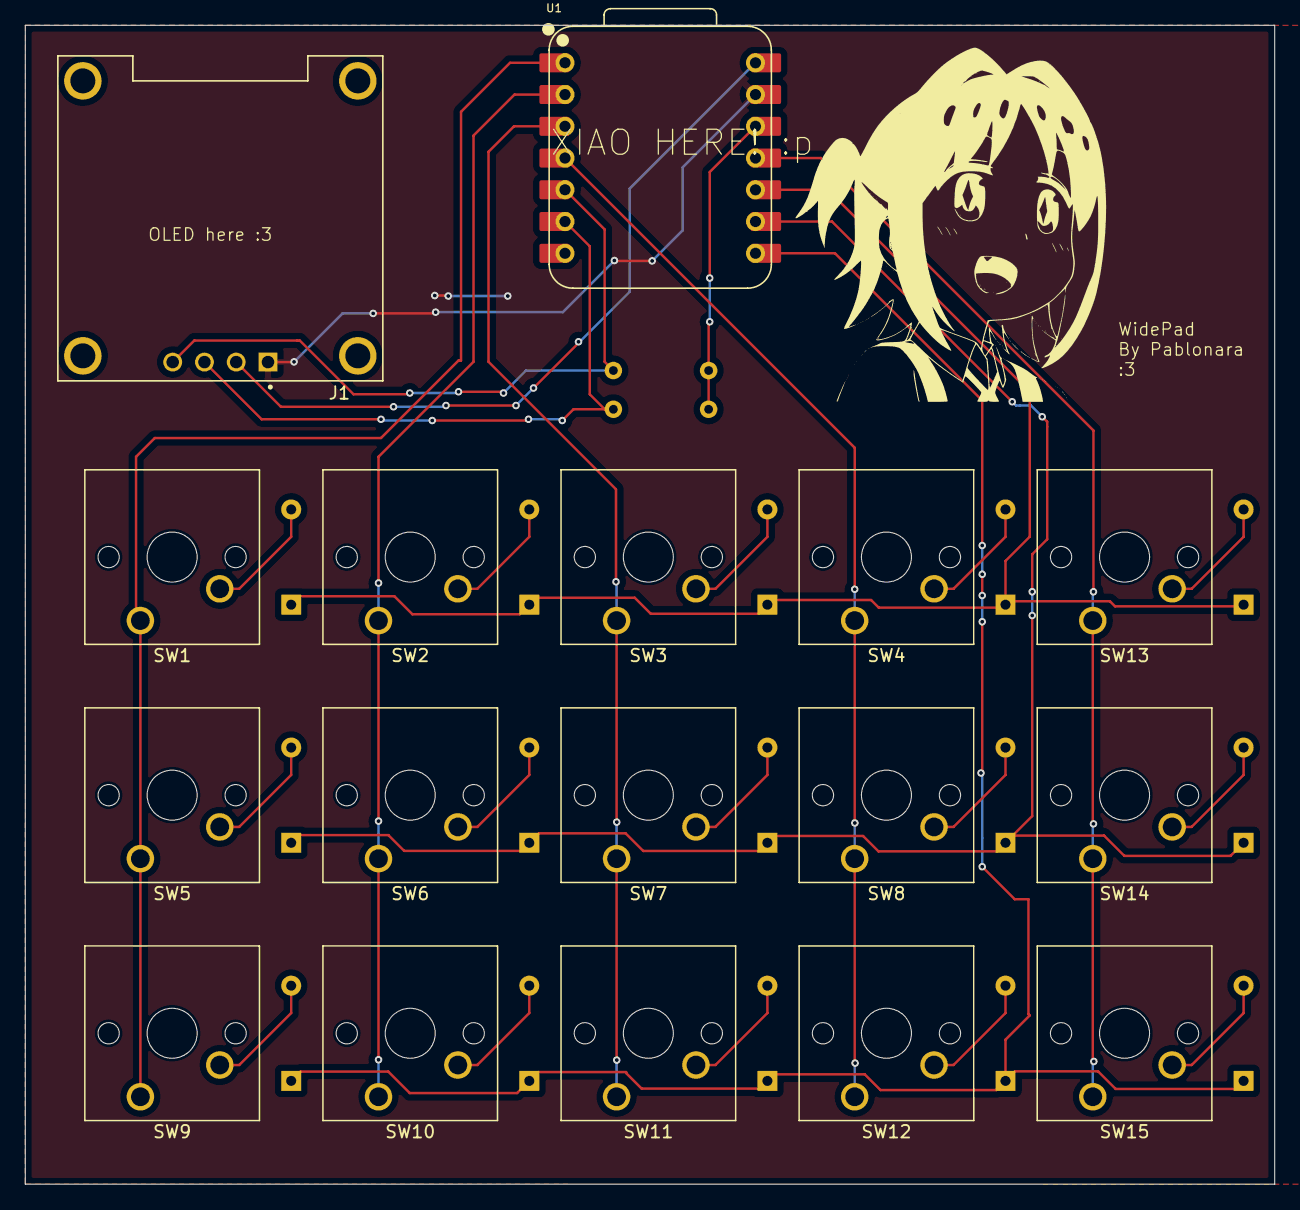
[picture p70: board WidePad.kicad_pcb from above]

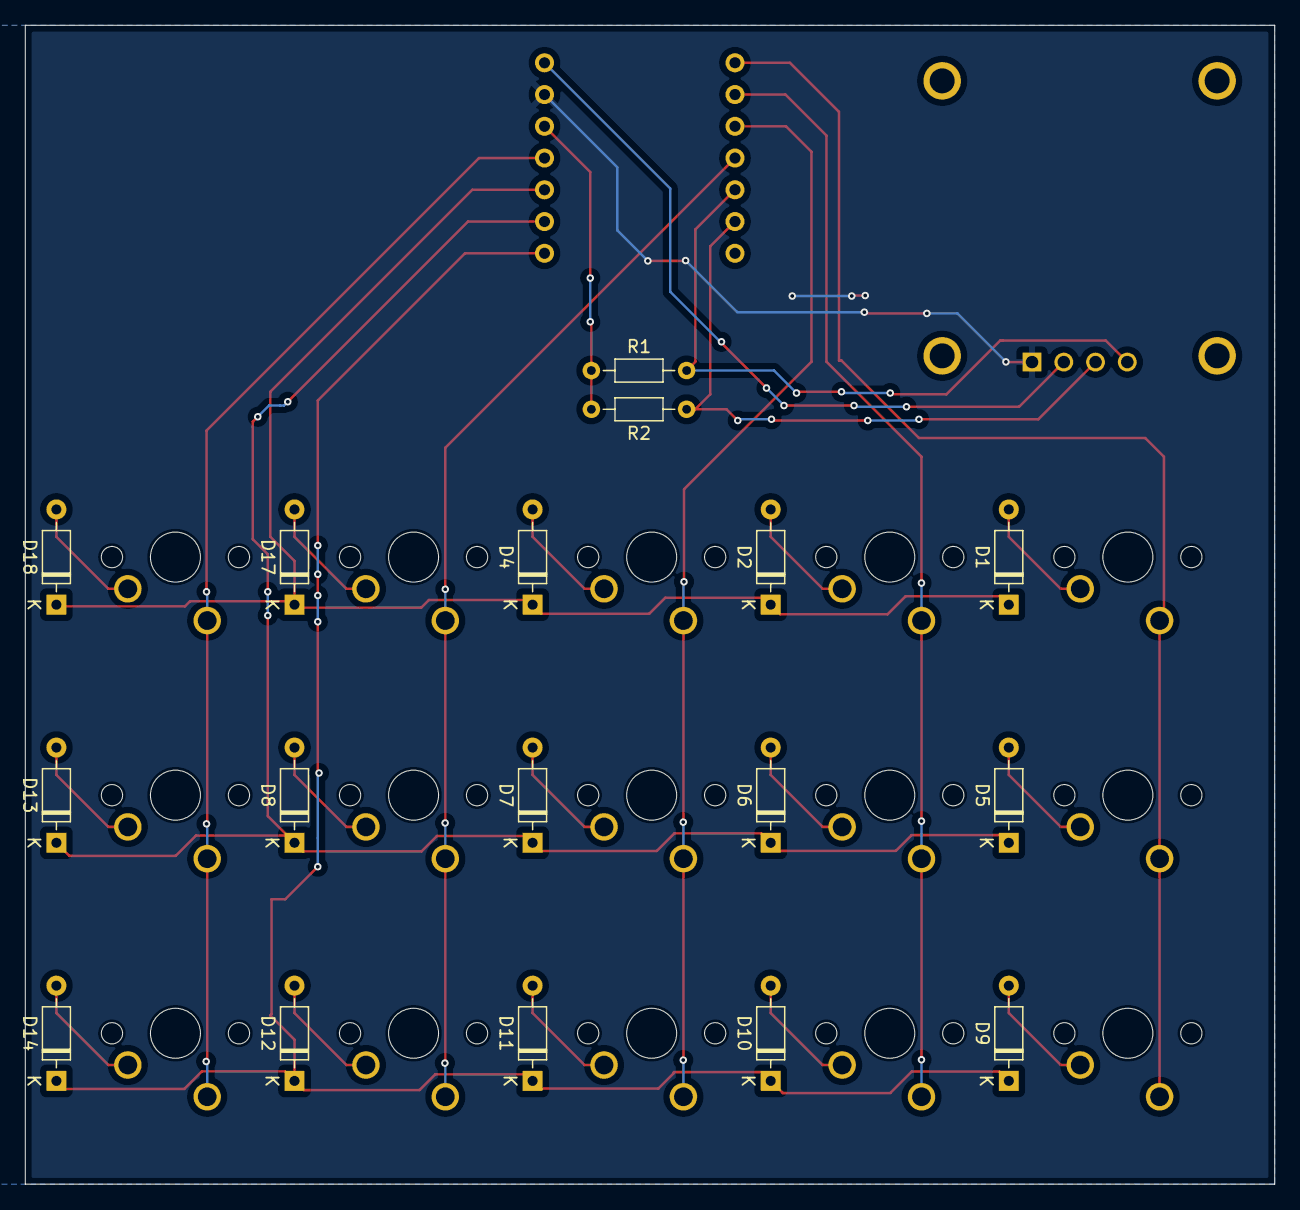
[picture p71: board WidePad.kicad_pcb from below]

Board: 2 copper layers, 100.0 x 92.7 mm, 34 parts (17 on the bottom side), 28 nets.

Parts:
D1, D2, D4, D5, D6, D7, D8, D9, D10, D11, D12, D13, D14, D17, D18: D; D_DO-35_SOD27_P7.62mm_Horizontal
J1: Conn_01x04_Pin; MODULE_DM-OLED096-636
R1, R2: R; R_Axial_DIN0204_L3.6mm_D1.6mm_P7.62mm_Horizontal
SW1, SW2, SW3, SW4, SW5, SW6, SW7, SW8, SW9, SW10, SW11, SW12, SW13, SW14, SW15: SW_Push; SW_Cherry_MX_1.00u_PCB
U1: XIAO-RP2040-DIP

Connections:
+3.3V: R1.1, R2.2, U1.12 (3V3)
+5V: J1.2, U1.14 (VBUS)
GND: J1.1, U1.13 (GND)
unnamed: D1.2 (A), SW1.2
unnamed: D1.1 (K), D2.1 (K), D4.1 (K), D17.1 (K), D18.1 (K), U1.10 (GPIO4/MISO)
unnamed: D2.2 (A), SW2.2
unnamed: D4.2 (A), SW3.2
unnamed: D5.2 (A), SW5.2
unnamed: D6.2 (A), SW6.2
unnamed: D7.2 (A), SW7.2
unnamed: D8.2 (A), SW8.2
unnamed: D9.2 (A), SW9.2
unnamed: D10.2 (A), SW10.2
unnamed: D9.1 (K), D10.1 (K), D11.1 (K), D12.1 (K), D14.1 (K), U1.8 (GPIO1/RX)
unnamed: D11.2 (A), SW11.2
unnamed: D12.2 (A), SW12.2
unnamed: D13.2 (A), SW14.2
unnamed: D5.1 (K), D6.1 (K), D7.1 (K), D8.1 (K), D13.1 (K), U1.9 (GPIO2/SCK)
unnamed: D14.2 (A), SW15.2
unnamed: D17.2 (A), SW4.2
unnamed: D18.2 (A), SW13.2
unnamed: SW13.1, SW14.1, SW15.1, U1.11 (GPIO3/MOSI)
unnamed: J1.4, R1.2, U1.5 (GPIO6/SDA)
unnamed: J1.3, R2.1, U1.6 (GPIO7/SCL)
unnamed: SW1.1, SW5.1, SW9.1, U1.1 (GPIO26/ADC0/A0)
unnamed: SW2.1, SW6.1, SW10.1, U1.2 (GPIO27/ADC1/A1)
unnamed: SW3.1, SW7.1, SW11.1, U1.3 (GPIO28/ADC2/A2)
unnamed: SW4.1, SW8.1, SW12.1, U1.4 (GPIO29/ADC3/A3)

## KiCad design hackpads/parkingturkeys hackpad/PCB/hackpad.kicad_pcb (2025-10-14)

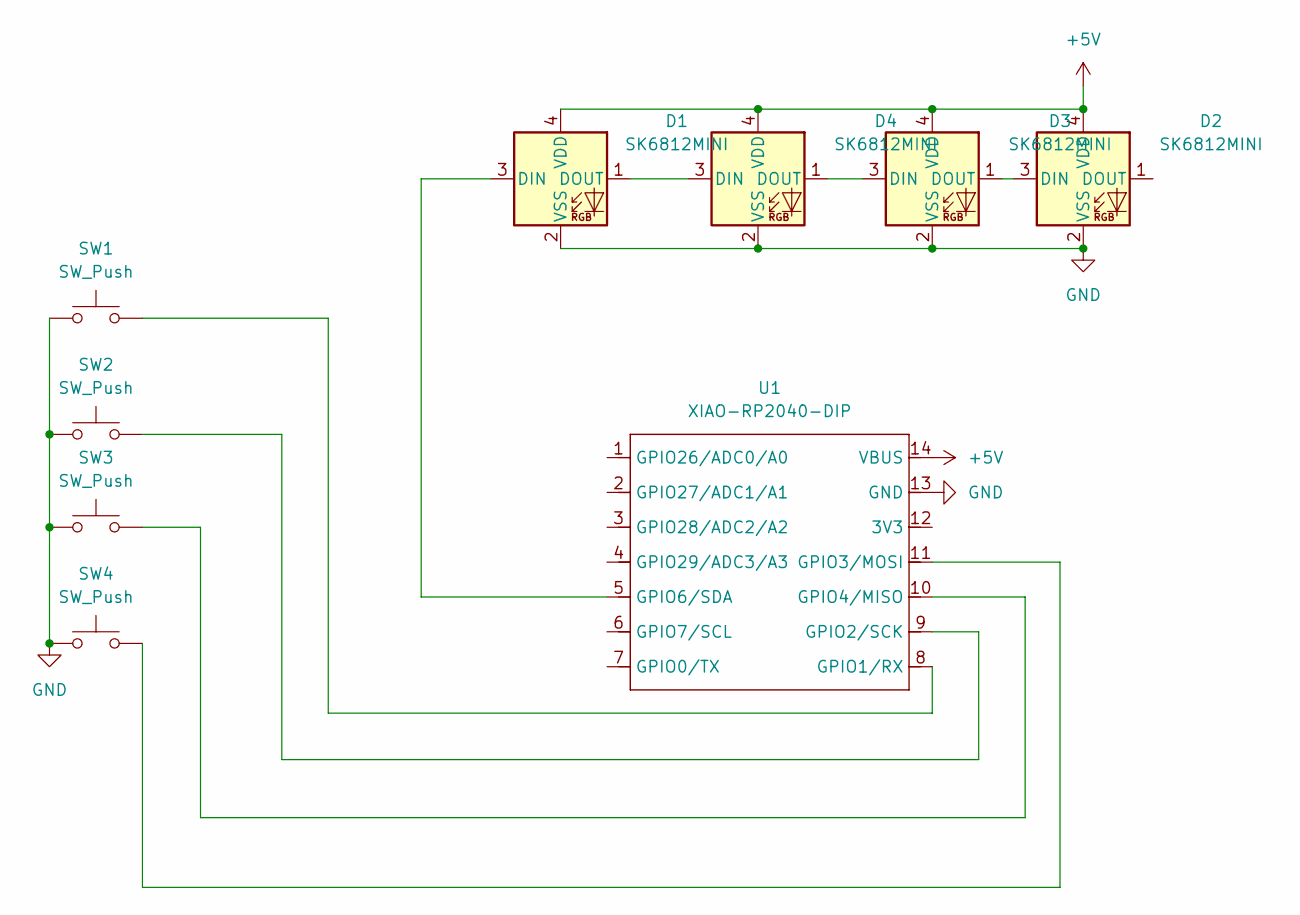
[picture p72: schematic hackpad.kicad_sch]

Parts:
D1, D2, D3, D4: SK6812MINI; LED_SK6812MINI_PLCC4_3.5x3.5mm_P1.75mm
SW1, SW2, SW3, SW4: SW_Push; SW_Cherry_MX_1.00u_PCB
U1: XIAO-RP2040-DIP

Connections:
+5V: D1.4 (VDD), D2.4 (VDD), D3.4 (VDD), D4.4 (VDD), U1.14 (VBUS)
GND: D1.2 (VSS), D2.2 (VSS), D3.2 (VSS), D4.2 (VSS), SW1.1, SW2.1, SW3.1, SW4.1, U1.13 (GND)
unnamed: D1.3 (DIN), U1.5 (GPIO6/SDA)
unnamed: D1.1 (DOUT), D4.3 (DIN)
unnamed: D2.3 (DIN), D3.1 (DOUT)
unnamed: D3.3 (DIN), D4.1 (DOUT)
unnamed: SW1.2, U1.8 (GPIO1/RX)
unnamed: SW2.2, U1.9 (GPIO2/SCK)
unnamed: SW4.2, U1.11 (GPIO3/MOSI)
unnamed: SW3.2, U1.10 (GPIO4/MISO)

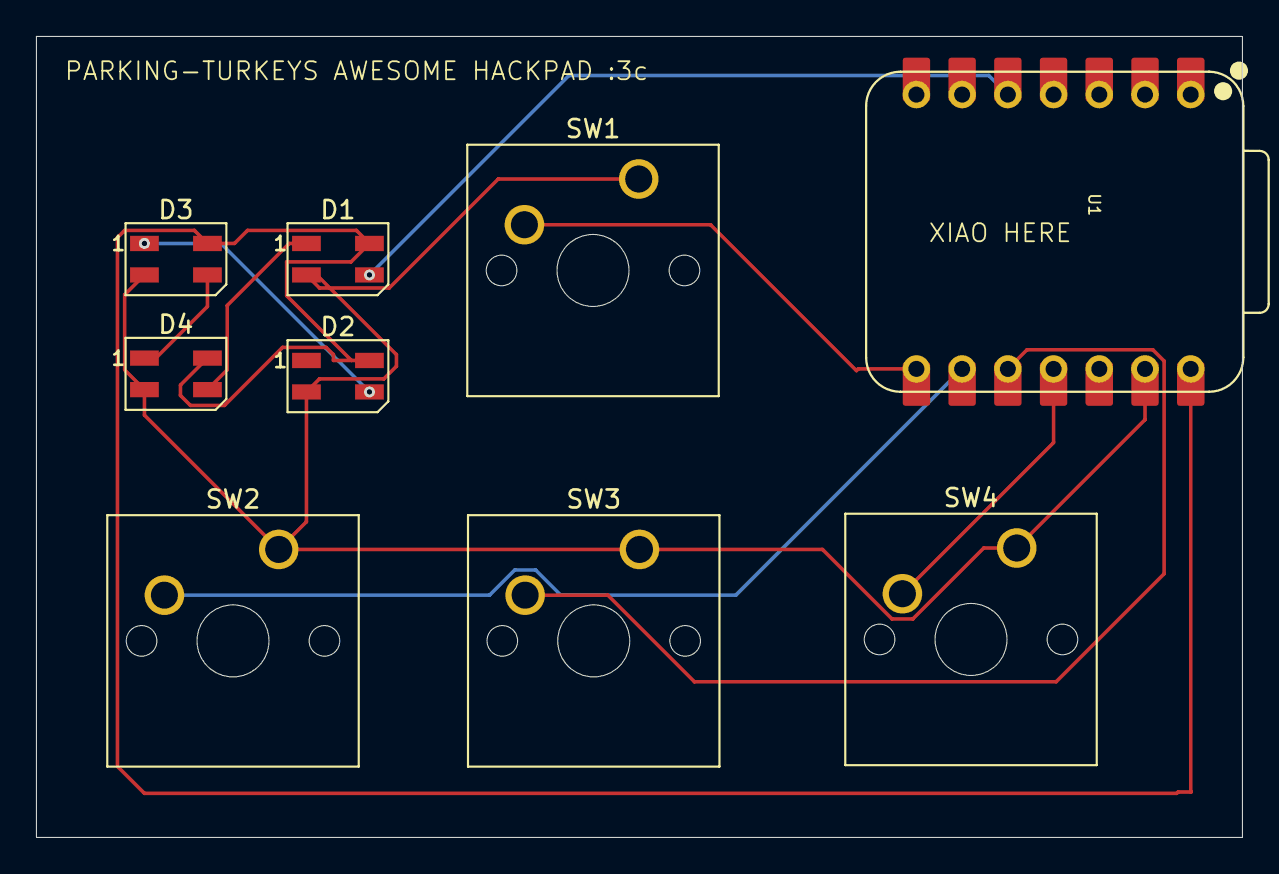
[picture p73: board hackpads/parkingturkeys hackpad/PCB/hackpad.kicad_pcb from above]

Board: 2 copper layers, 67.0 x 44.5 mm, 9 parts (0 on the bottom side), 10 nets.

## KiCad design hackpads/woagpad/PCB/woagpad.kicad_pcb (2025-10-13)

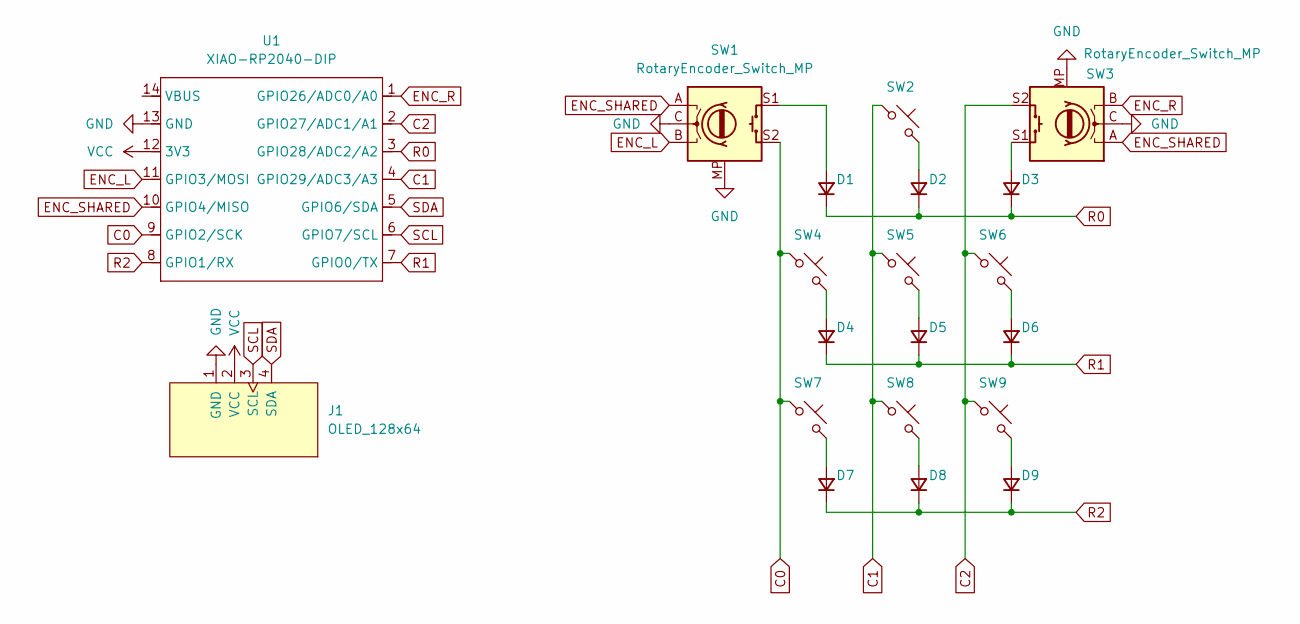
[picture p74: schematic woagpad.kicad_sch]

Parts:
D1, D2, D3, D4, D5, D6, D7, D8, D9: D; Diode_DO-35
J1: OLED_128x64; MODULE_DM-OLED096-636
SW1, SW3: RotaryEncoder_Switch_MP; Encoder_EC11_MX
SW2, SW4, SW5, SW6, SW7, SW8, SW9: SW_Push; MX_PCB
U1: XIAO-RP2040-DIP; Seeed_XIAO_RP2040

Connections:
C0: SW1.S2, SW4.1, SW7.1, U1.9 (GPIO2/SCK)
C1: SW2.1, SW5.1, SW8.1, U1.4 (GPIO29/ADC3/A3)
C2: SW3.S2, SW6.1, SW9.1, U1.2 (GPIO27/ADC1/A1)
ENC_L: SW1.B, U1.11 (GPIO3/MOSI)
ENC_R: SW3.B, U1.1 (GPIO26/ADC0/A0)
ENC_SHARED: SW1.A, SW3.A, U1.10 (GPIO4/MISO)
GND: J1.1 (GND), SW1.C, SW1.MP, SW3.C, SW3.MP, U1.13 (GND)
unnamed: D1.2 (A), SW1.S1
unnamed: D2.2 (A), SW2.2
unnamed: D3.2 (A), SW3.S1
unnamed: D4.2 (A), SW4.2
unnamed: D5.2 (A), SW5.2
unnamed: D6.2 (A), SW6.2
unnamed: D7.2 (A), SW7.2
unnamed: D8.2 (A), SW8.2
unnamed: D9.2 (A), SW9.2
R0: D1.1 (K), D2.1 (K), D3.1 (K), U1.3 (GPIO28/ADC2/A2)
R1: D4.1 (K), D5.1 (K), D6.1 (K), U1.7 (GPIO0/TX)
R2: D7.1 (K), D8.1 (K), D9.1 (K), U1.8 (GPIO1/RX)
SCL: J1.3 (SCL), U1.6 (GPIO7/SCL)
SDA: J1.4 (SDA), U1.5 (GPIO6/SDA)
VCC: J1.2 (VCC), U1.12 (3V3)



Board: 2 copper layers, 57.5 x 93.2 mm, 22 parts (10 on the bottom side), 22 nets.

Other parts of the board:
QR*****: WobblQR
kibuzzard-67AA371A: G***; kibuzzard-67AA371A

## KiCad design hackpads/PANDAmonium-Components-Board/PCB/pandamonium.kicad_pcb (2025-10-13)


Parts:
D1, D2: SK6812MINI; LED_SK6812MINI_PLCC4_3.5x3.5mm_P1.75mm
SW1, SW2, SW3, SW4, SW5, SW6, SW7, SW8, SW9: SW_Push; SW_Cherry_MX_1.00u_PCB
U1: XIAO-RP2040-DIP

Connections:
+5V: D1.4 (VDD), D2.4 (VDD), U1.14 (VBUS)
GND: D1.2 (VSS), D2.2 (VSS), SW1.1, SW2.1, SW3.1, SW4.1, SW5.1, SW6.1, SW7.1, SW8.1, SW9.1, U1.13 (GND)
unnamed: D1.3 (DIN), U1.1 (GPIO26/ADC0/A0)
unnamed: D1.1 (DOUT), D2.3 (DIN)
unnamed: SW1.2, U1.8 (GPIO1/RX)
unnamed: SW2.2, U1.9 (GPIO2/SCK)
unnamed: SW4.2, U1.11 (GPIO3/MOSI)
unnamed: SW3.2, U1.10 (GPIO4/MISO)
unnamed: SW7.2, U1.5 (GPIO6/SDA)
unnamed: SW8.2, U1.6 (GPIO7/SCL)
unnamed: SW5.2, U1.2 (GPIO27/ADC1/A1)
unnamed: SW6.2, U1.3 (GPIO28/ADC2/A2)
unnamed: SW9.2, U1.4 (GPIO29/ADC3/A3)


Board: 2 copper layers, 62.0 x 85.0 mm, 12 parts (0 on the bottom side), 13 nets.

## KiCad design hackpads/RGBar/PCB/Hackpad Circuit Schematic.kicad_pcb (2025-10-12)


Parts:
D1, D2, D3, D4, D5, D6, D7, D8: SK6812; MX-1U-SK6812Mini-E
D9, D10, D11, D12, D13, D14, D15, D16: 1N4148; DIOAD753W49L380D172B; PARTREV 5
SW1, SW2, SW3, SW4, SW5, SW6, SW7, SW8: SW_Push; SW_Cherry_MX_1.00u_PCB
SW9: RotaryEncoder; RotaryEncoder_Alps_EC11E-Switch_Vertical_H20mm_CircularMoun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
U1: XIAO-RP2040-DIP

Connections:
1: SW1.1, SW2.1, SW3.1, SW4.1, U1.1 (GPIO26/ADC0/A0)
2: SW5.1, SW6.1, SW7.1, SW8.1, U1.7 (GPIO0/TX)
3: D9.K, D13.K, U1.2 (GPIO27/ADC1/A1)
4: D10.K, D14.K, U1.3 (GPIO28/ADC2/A2)
5: D11.K, D15.K, U1.4 (GPIO29/ADC3/A3)
6: D12.K, D16.K, U1.5 (GPIO6/SDA)
7: SW9.S2, U1.8 (GPIO1/RX)
8: SW9.B, U1.9 (GPIO2/SCK)
9: SW9.A, U1.10 (GPIO4/MISO)
10: D1.2 (DIN), U1.6 (GPIO7/SCL)
+3V3: U1.12 (3V3)
+5V: D1.3 (VDD), D2.3 (VDD), D3.3 (VDD), D4.3 (VDD), D5.3 (VDD), D6.3 (VDD), D7.3 (VDD), D8.3 (VDD), U1.14 (VBUS)
GND: D1.1 (VSS), D2.1 (VSS), D3.1 (VSS), D4.1 (VSS), D5.1 (VSS), D6.1 (VSS), D7.1 (VSS), D8.1 (VSS), SW9.C, SW9.S1, U1.13 (GND)
unnamed: D1.4 (DOUT), D2.2 (DIN)
unnamed: D2.4 (DOUT), D3.2 (DIN)
unnamed: D3.4 (DOUT), D4.2 (DIN)
unnamed: D4.4 (DOUT), D5.2 (DIN)
unnamed: D5.4 (DOUT), D6.2 (DIN)
unnamed: D6.4 (DOUT), D7.2 (DIN)
unnamed: D7.4 (DOUT), D8.2 (DIN)
unnamed: D9.A, SW1.2
unnamed: D10.A, SW2.2
unnamed: D11.A, SW3.2
unnamed: D12.A, SW4.2
unnamed: D13.A, SW5.2
unnamed: D14.A, SW6.2
unnamed: D15.A, SW7.2
unnamed: D16.A, SW8.2


Board: 2 copper layers, 100.0 x 39.0 mm, 26 parts (0 on the bottom side), 27 nets.

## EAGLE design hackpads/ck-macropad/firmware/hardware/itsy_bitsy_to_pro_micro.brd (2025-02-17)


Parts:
FRAME2: FRAME-LETTER; CREATIVE_COMMONS
JP1: HEADER-1X570MIL; 1X05_ROUND_70
JP2, JP4: HEADER-1X14; 1X14_ROUND70
JP3, JP5: M12PTH; 1X12

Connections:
!RESET: JP3.3, JP4.14
+3V3: JP4.13
A0: JP3.5, JP4.10
A1: JP3.6, JP4.9
A2: JP3.7, JP4.8
A3: JP3.8, JP4.7
A4: JP3.9, JP4.6
A5: JP3.10, JP4.5
AREF: JP4.12
D2: JP4.1
D3: JP1.4
D4: JP1.5
D5_5V: JP2.10
D7: JP2.9, JP5.1
D9: JP2.8, JP5.2
D10: JP2.7, JP5.3
D11: JP2.6, JP5.4
D12: JP2.5, JP5.5
D13: JP2.4, JP5.6
EN: JP1.1
GND: JP2.2, JP3.2, JP5.9, JP5.10
MISO: JP4.2
MOSI: JP3.12, JP4.3
RAW_PM: JP3.1
RX_D0: JP2.14, JP5.11
SCK: JP3.11, JP4.4
SCL: JP2.11, JP5.7
SDA: JP2.12, JP5.8
SWCLK: JP1.3
SWDIO: JP1.2
TX_D1: JP2.13, JP5.12
VBAT: JP2.1
VBUS: JP2.3, JP3.4
VHI: JP4.11

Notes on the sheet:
TX0/PD3->TX RX1/PD2->RX GND->GND GND->GND 2/PD1->SDA 3/PD0->SCL 4/PD4->13 5/PC6->12 6/PD7->11 7/PE6->10 8/PB4->9 9/PB5->7
OLD
Raw-> GND->GND RST->RST VCC->USB A3/PF4->A0 A2/PF5->A1 A1/PF6->A2 A0/PF7->A3 15/PB1->A4 14/PB3->A5 16/PB2->SCK 10/PB6->MOSI
Bryan Siepert



Board: 2 copper layers, 35.8 x 20.7 mm, 6 parts (2 on the bottom side), 21 nets.

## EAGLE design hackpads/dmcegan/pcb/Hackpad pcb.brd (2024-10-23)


Board: 2 copper layers, 78.4 x 64.8 mm, 12 parts (0 on the bottom side), 12 nets.

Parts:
U1: XIAO-THRUHOLE; XIAO-GENERIC-THRUHOLE-MODULE14P-2.54-21X17.8MM
U$1, U$2, U$3, U$4, U$5, U$6, U$7, U$8, U$9, U$10, U$11: CHERRY-MX

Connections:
GND: U1.13, U$1.SW2, U$2.SW2, U$3.SW2, U$4.SW2, U$5.SW2, U$6.SW2, U$7.SW2, U$8.SW2, U$9.SW2, U$10.SW2, U$11.SW2
unnamed: U1.1, U$5.SW1
unnamed: U1.2, U$6.SW1
unnamed: U1.3, U$7.SW1
unnamed: U1.4, U$8.SW1
unnamed: U1.5, U$9.SW1
unnamed: U1.6, U$10.SW1
unnamed: U1.7, U$11.SW1
unnamed: U1.11, U$1.SW1
unnamed: U1.10, U$2.SW1
unnamed: U1.9, U$3.SW1
unnamed: U1.8, U$4.SW1

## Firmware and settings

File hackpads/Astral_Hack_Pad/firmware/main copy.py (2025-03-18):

from kmk.kmk_keyboard import KMKKeyboard
from kmk.scanners import DiodeOrientation
from kmk.modules.layers import Layers
from kmk.modules.display.oled import Oled, OledDisplayMode
from kmk.modules.usb_hid import USBHID
from kmk.extensions.media_keys import MediaKeys
from kmk.keys import KC
import board
import digitalio
import rotaryio
import displayio
import adafruit_displayio_ssd1306
import terminalio
from adafruit_display_text import label

# Initialize KMK
keyboard = KMKKeyboard()
keyboard.modules.append(Layers())
keyboard.modules.append(USBHID())
keyboard.extensions.append(MediaKeys())

# Define MX key pins based on the schematic
keyboard.col_pins = (board.GP26, board.GP27, board.GP28)  # Columns
keyboard.row_pins = (board.GP5, board.GP9, board.GP10, board.GP11)  # Rows
keyboard.diode_orientation = DiodeOrientation.COL2ROW

# Rotary Encoder Setup
encoder = rotaryio.IncrementalEncoder(board.GP8, board.GP9)
encoder_switch = digitalio.DigitalInOut(board.GP10)
encoder_switch.direction = digitalio.Direction.INPUT
encoder_switch.pull = digitalio.Pull.UP

# OLED Setup (128x64 display on I2C, connected to GP6 (SDA) & GP7 (SCL))
displayio.release_displays()
i2c = board.I2C()
display_bus = displayio.I2CDisplay(i2c, device_address=0x3C)
display = adafruit_displayio_ssd1306.SSD1306(display_bus, width=128, height=64)

# Define key layers with customizable function keys
LAYER_1 = [
    KC.F1, KC.F2, KC.F3,
    KC.F4, KC.F5, KC.F6,
    KC.F7, KC.F8, KC.F9,
    KC.F10, KC.F11, KC.F12,
]
LAYER_2 = [
    KC.MEDIA_PLAY_PAUSE, KC.MEDIA_NEXT_TRACK, KC.MEDIA_PREV_TRACK,
    KC.VOLU, KC.VOLD, KC.MUTE,
    KC.BRIGHTNESS_UP, KC.BRIGHTNESS_DOWN, KC.SLEEP,
    KC.ESC, KC.ENTER, KC.SPACE,
]

# Track layer index
layer_index = 0

# Encoder handling function
def check_encoder():
    global layer_index
    last_position = encoder.position
    while True:
        if encoder.position > last_position:
            layer_index = (layer_index + 1) % 2  # Toggle layers
        elif encoder.position < last_position:
            layer_index = (layer_index - 1) % 2
        last_position = encoder.position
        keyboard.active_layers = [layer_index]
        update_oled()
        keyboard.go()

# OLED Update Function
def update_oled():
    splash = displayio.Group()
    text = f"Layer: {layer_index}"
    text_area = label.Label(terminalio.FONT, text=text, color=0xFFFFFF, x=10, y=30)
    splash.append(text_area)
    display.show(splash)

# Assign layers to KMK
keyboard.keymap = [LAYER_1, LAYER_2]

# Run encoder checking in a loop
import supervisor
supervisor.set_next_stack_limit(4096)
import asyncio
async def main():
    while True:
        check_encoder()
        await asyncio.sleep(0.01)

import asyncio
asyncio.run(main())

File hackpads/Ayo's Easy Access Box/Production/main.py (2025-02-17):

import board

from kmk.kmk_keyboard import KMKKeyboard
from kmk.keys import KC
from kmk.scanners import DiodeOrientation
from kmk.modules.encoder import EncoderHandler

keyboard = KMKKeyboard()

# Matrix pins
COL1 = board.D0
COL2 = board.D1
COL3 = board.D2

ROW1 = board.D3
ROW2 = board.D4
ROW3 = board.D5

# rotary encoder pins
ROTA = board.D7
ROTB = board.D8
PUSHBUTTON = board.D9

# Matrix settings
keyboard.col_pins = (COL1, COL2, COL3)
keyboard.row_pins = (ROW1, ROW2, ROW3)
keyboard.diode_orientation = DiodeOrientation.COL2ROW

# Encoder settings
encoder_handler = EncoderHandler()
keyboard.modules.append(encoder_handler)
encoder_handler.pins = ((ROTA, ROTB, PUSHBUTTON, False),)
encoder_handler.map = (((KC.VOLD, KC.VOLU, KC.MUTE),),)

keyboard.keymap = [
    [KC.LCTRL(KC.Z), KC.LCTRL(KC.Y), KC.LCTRL(KC.S),  # Row 1
    [KC.LALT(KC.TAB), KC.LCTRL(KC.F), KC.LCTRL(KC.SHIFT(KC.T)),  # Row 2
    [KC.LCTRL(KC.T), KC.LCTRL(KC.C), KC.LCTRL(KC.V)) # Row 3

]


if __name__ == "__main__":
    keyboard.go()

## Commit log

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2025-02-15 gerbers update
    updated gerbers to reflect pcb fix
2025-02-15 Delete hackpads/artzelpad/pcb/artzelpad.kicad_pcb
    deleted old pcb file
    [artzelpad.kicad_pcb]
2025-02-15 Added new pcb file
    changed pcb file to reflect changes
    [artzelpad.kicad_pcb]
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2025-02-15 Moved filed to randoms folder
    [bom.csv, designators.csv, positions.csv]
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2025-02-15 Reuploaded Shortycuts
    [Hack club YSWS.kicad_pcb, Hack club YSWS.kicad_sch, Main body.stl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]
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2025-02-15 fix gerbers
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2025-02-15 add production case and gerbers
    [macropad-bottom.step, macropad-top.step]
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2025-02-15 Updates to case and PCB for GamerPad
    [bottom.step, gamerpad.kicad_pcb, top.step]
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2025-02-15 Remove weird PCB connection point
    [gamerpad.kicad_pcb]
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2025-02-15 Add files via upload
    Added Jayden'sCustomizablePad
    [HackPadCase.step, HackPadCover.step, HackPadV2.kicad_pcb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]
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2025-02-15 Add files via upload
    Added Jayden's Customizable Pad
    [HackPadCase.step, HackPadCover.step, HackPadV2.kicad_pcb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]
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2025-02-16 Update README.md
    Added the forgotten keycaps in the BOM + fixed the image problem for the CAD, PCB, and Schematic
2025-02-16 DeployorPad V1 Added!
    With this PR i am adding my Hackpad called Deployor Pad to this repo!
    [BOTTOM.step, MIDDLE.step, Macropad.kicad_pcb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]
2025-02-16 added components + updated cover design
    [cover.step]
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2025-02-16 oops forgot the branding text stuff
    [base.step, yanpad.kicad_pcb]
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2025-02-16 Added Fixes
    [Bottom Plate.step, MacroPad 3D Case.step, Top Plate.step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]
2025-02-16 added hackerpad! (pelase say yes)
    [Main body.stl, Top cover.stl, hackerpad.kicad_pcb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]
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2025-02-16 Bat-Board pr for hackpad
    it is a 13 key macropad similar to protadesigns and adafruit macropad.
    [3DShell_3DShell_Macropad 2_B.stl, 3DShell_3DShell_Macropad 2_T.stl, 3DShell_Macropad_Box_B.stl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]
2025-02-16 3d file correction
    [dorian_macropad_plate.stl]
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2025-02-16 production fix
    [duckpad_v2_lock.step]
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2025-02-16 Submission Preparation
    All the things ;)
    [MX_Switch.step, RotaryEncoder_Alps_EC11E-Switch_Vertical_H20mm.step, SK6812MINI-E.step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]
2025-02-16 Final Changes done, ready for submission.
    [HackPad v0.step]
2025-02-16 Last commit had issues, hopefull final commit.
    [HackPad v4.step, TOP.stl]
2025-02-16 feat: Add wasdup_pad from Jayden295
    That's my hackpad!
    [SSD1306_OLED_Display(128x64).step, full-pad.FCStd, hackpad.kicad_pcb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]
2025-02-16 I suck at git
    [BOT.stl, HackPad v0.step, TOP.stl]
2025-02-16 Okay maybe final commit
    [BOT.stl, HackPad v0.step, TOP.stl]
2025-02-16 Final Updates
    This is the last one I swear
    [SplashPad Case - Case Top.step]
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2025-02-16 Eason Yang's Yippee! Hack Pad :D
    [Base - Final Copy.step, Top - Final Copy.step, hackpad.kicad_pcb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]
2025-02-16 Rename StenoPad to DawPad and remove all the PCB stuff from it
    [Left_Half.kicad_sch, Right_Half.kicad_sch, StenoPad.kicad_pcb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]
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2025-02-16 Add a blank PCB for the DawPad
    [DawPad.kicad_pcb, DawPad.kicad_sch]
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2025-02-16 Add Yet Another Hackpad
    [Bottom.step, EC11_Rotary_Encoder_Switched.step, Seeed Studio XIAO RP2040 v26.step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]
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2025-02-16 firmware and case in production
    [Danger_Hackpad_bottom v2.step, Danger_Hackpad_top v1.step]
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2025-02-16 everything should be good
    [Hackpad v2.step, Hackpad v6.step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]
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2025-02-16 have pcb folder not be a submodule
    [Gateron-KS33-Socket.step, Grove - Vision AI Module V2.kicad_pcb, Grove - Vision AI Module V2.kicad_sch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]
2025-02-17 Revert "Add MayoDevice"
    [128x32-OLED.STEP, Bottom.step, Kailh_PG1353.STEP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]
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2025-02-17 added brand thing to bottom part
    [Bottom.step]
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2025-02-17 Update BOM.md (More link fixes)
    forgot there were more
    oopsies
2025-02-17 update pcb to have buzzer
    [bom.csv, macropad.kicad_pcb, macropad.kicad_sch]
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2025-02-18 Switch to Seeed Studio OPL KiCad Library for DawPad Also rearranges the .gitmodules file to be alphabetical (except for the OrpheusPad, which is at the top).
    [DawPad.kicad_sch]
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2025-02-18 new file: hackpads/TriggerPad/production/case/Case Bottom v2.step new file: hackpads/TriggerPad/production/case/Case Top V2.step deleted: hackpads/TriggerPad/production/case/Case Top.stl deleted: hac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
    [Case Bottom v2.step, Case Top V2.step, Case Top.stl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]
2025-02-18 Updated KiCad source files with potential hackpad fixes
    [retrooper_keyboard.kicad_pcb, retrooper_keyboard.kicad_sch]
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2025-02-18 Revert "Add RayPad*"
    [Case Body v11.stl, Case Top v4.stl, hackpad.kicad_pcb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]
2025-02-18 Revert "Attempted Fixes to retrooperpad"
    [retrooper_keyboard.kicad_pcb, retrooper_keyboard.kicad_sch]
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2025-02-19 fix stand rotation (hopefully)
    [stand.step]
2025-02-19 Connect inputs on the DawPad schematic and lay things out on the PCB
    [DawPad.kicad_pcb, DawPad.kicad_sch]
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2025-02-19 Add fixed QOLPad
    [BottomCase.step, HackPad Osu Macropad.kicad_pcb, HackPad Osu Macropad.kicad_sch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]
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2025-02-19 Split 3d models & made minor corrections
    [RoyTyper_bottom.stl, RoyTyper_plate.stl]
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2025-02-20 Add files via upload
    added the name son case
    [RR-GAMEPAD_bottom_case.stl, RR-GAMEPAD_top_case.stl]
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2025-02-20 added the PANDAmonium Components Board by Kai Pereira
    [Bottom Case.stl, Top Case.stl, pandamonium.kicad_sch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]
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2025-02-20 fixed schematic errors
    [craftpad.kicad_sch]
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2025-02-21 wrong step file
    [HackpadCase v172.step]
2025-02-21 Add files via upload
    its nearly 1am sorry if I made any mistakes
    [Bottom.step, Top.step, hackpad body.stl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]
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2025-02-21 Fixed JoyKey cad models
    [Case - JoyKey lid.step]
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2025-02-21 Update ScrollPad hardware and firmware
    - Change GPIO pin assignments
    - PCB improvements: add mounting holes, LED position, routing
    - Case improvements: add spacer, cover fix, add Skadis holder
    - Update firmware: add LED layer indication, add mouse scrolling keys, change keys
    [Case.step, CaseBase.step, CaseCover.step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]
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2025-02-24 Add LEDs to and finish PCB for DawPad
    [DawPad.kicad_pcb, DawPad.kicad_sch]
2025-02-24 Delete hackpads/BluePunia's hackpad/production/BluePunia's_bottomside.step
    (removed the wrong version of the bottom side of the case)
    [BluePunia's_bottomside.step]
2025-02-25 Fix up some things on the DawPad PCB
    [DawPad.kicad_pcb]
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2025-02-26 renamed: hackpads/QOLPad/QOLPad/BOM.md -> hackpads/QOLPad/BOM.md renamed: hackpads/QOLPad/QOLPad/QOLPad Gerbers.zip -> hackpads/QOLPad/QOLPad Gerbers.zip renamed: hackpads/QOLPad/QOLPad/QOLPad Kicad 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
    [BottomCase.step, HackPad Osu Macropad.kicad_pcb, HackPad Osu Macropad.kicad_sch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]
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2025-02-28 New Case Bottom part with my Hackpad Branding
    [Bottom Case v1.step]
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2025-03-03 reverted example deleted: hackboards/dari_awesomesauce_board/pcb/#auto_saved_files# deleted: hackboards/dari_awesomesauce_board/pcb/_autosave-dari_awesomesauce_board.kicad_sch modified: hackboards/da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
2025-03-08 add some more stuff to the case + fix a bit of code + add bom to readme
    [hackpad bottom.step, hackpad top.step, top.step]
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2025-03-09 Fixed PCB dir
    [board.kicad_pcb, board.kicad_sch]
2025-03-09 fixed gerbers
2025-03-10 updated board, added footprint for pico w/ machined headerpin sockets
    [dari_awesomesauce_board.kicad_pcb, dari_awesomesauce_board.kicad_sch]
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2025-03-11 updated folder name to not match duplicates and not cause issues
    [OsuPad.stl, hackpad.kicad_pcb, hackpad.kicad_sch]
2025-03-11 I deleted the upload to the wrong directory
    [TyrannoJ_Projekt2.step, bottom case.stl, projekt2.kicad_pcb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]
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2025-03-12 fixed modified HackPad.kicad_prl
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2025-03-13 update models + bom, new images for model
    [bom.csv, top.step]
2025-03-13 added schematic Screenshot and changed C1 to 10uF
    [hackpad.csv, hackpad.kicad_sch]
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2025-03-14 Deleting old version before checking that xiao fit
    [Assembled Turtlepad! v6.step]
2025-03-14 Fixed pcb
    [Turtlepad PCB.kicad_pcb, Turtlepad PCB.kicad_sch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]
2025-03-14 Fixed pcb and added fixed production
    [Turtlepad Plate v4.step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]
2025-03-15 Add branding for bottom of case for robopad
    [case_bottom.scad]
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2025-03-29 Fixed tolerances
    [Assembled Turtlepad! v11.step]
2025-03-30 fix: add case opening for usb
    [Bottom.step]
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2025-04-04 fixed bottom shell to print without support
    [bottom_shell.step]
2025-04-08 fix: move basmati.step to CAD/
    [basmati.step]
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2025-06-29 Override crappy files with good ones HOPEFULLY LAST TIME
    [Hackpad Cover.step, hackpad.kicad_pcb, hackpad.kicad_sch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]
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2025-10-13 refactor(woagpad): replace git submodule with raw src take 2
    [Bottom.step, Top.step, woagpad.kicad_pcb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]
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2025-10-18 update firepad files (I thought I did this ages ago oops :/)
    [firepad-bottom.step, firepad-case.step, firepad-top.step]

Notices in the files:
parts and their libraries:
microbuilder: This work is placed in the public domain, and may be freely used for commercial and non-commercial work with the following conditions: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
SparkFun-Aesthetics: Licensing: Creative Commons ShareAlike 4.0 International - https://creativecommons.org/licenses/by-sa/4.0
